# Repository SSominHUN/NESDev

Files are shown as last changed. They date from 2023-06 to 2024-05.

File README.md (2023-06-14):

# NESDev

Thesis work.

In my thesis, I re-design the iconic game console Nintendo Entertainment System to modern standards. My project based on the hardware emulation of the NES’s hardware in an FPGA (Xilinx Spartan-
6). 

This is an ongoing project. In my last semester, I designed a two layer PCB, with Altium Designer, where I upgrade the old
hardware, with modern components. I placed an HDMI for VGA rendering, also an on board SRAM (for NES game ROM's). For future improvements I placed an MicroSD card reader (holding more game ROM's). Of course next to these "upgrades" my console have to play the original games.

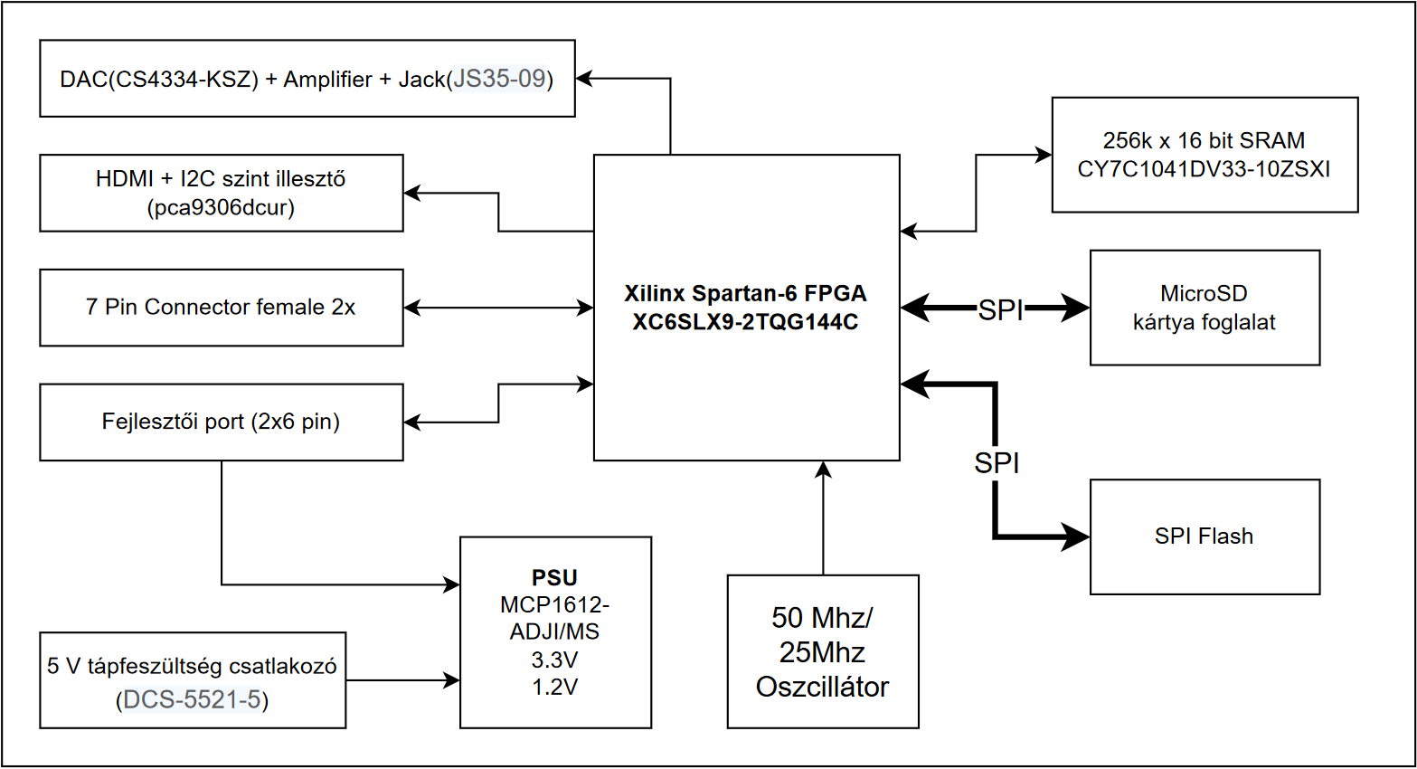
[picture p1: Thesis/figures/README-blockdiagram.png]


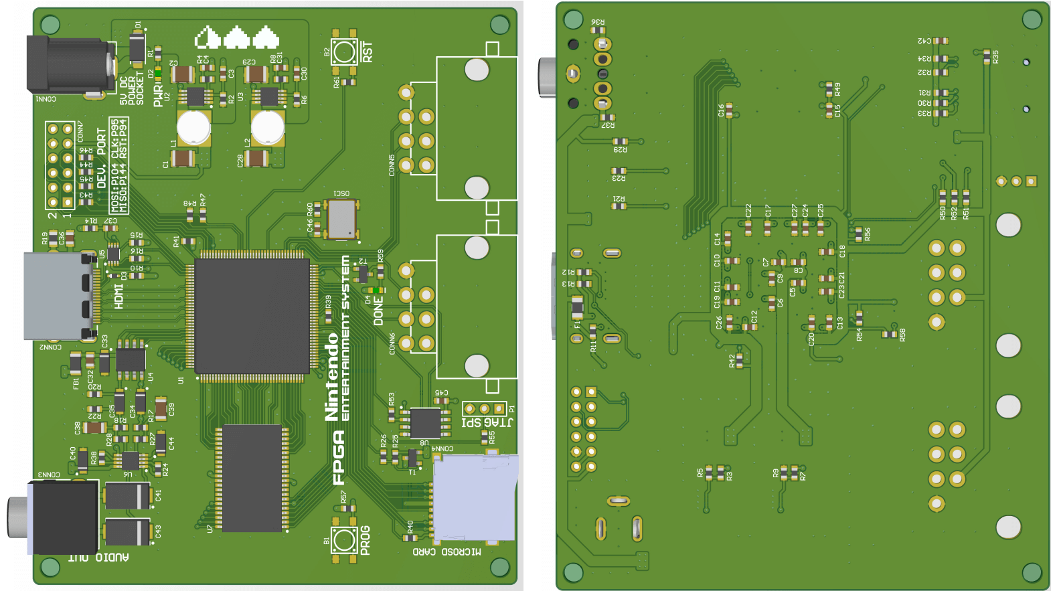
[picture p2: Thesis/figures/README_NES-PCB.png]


Moreover I started to work on re-designing the PPU (Picture Process Unit) of the NES. 

In the future I'm going to implement the CPU (6502 8-bit) of the original hardware and the APU (Audio Process Unit) and in the end I will test my hardware with the original games.
This stage of the project have a Hungarian documentation.

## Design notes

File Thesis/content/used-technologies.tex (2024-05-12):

\chapter{Felhasznált eszközök}

\section{Altium Designer}

Az Altium Designer egy teljes körű elektronikai tervező szoftvercsomag (EDA), amelyet nyomtatott áramköri lapok (PCB-k) tervezésére alkalmaznak. Egységes környezetben kombinálja a kapcsolás rajz és a PCB tervezését, ezzel lehetővé téve a tervezőknek a grafikus áramköri tervek gyors és hatékony létrehozását. A szoftver támogatja a hierarchikus tervezést és a kapcsolási rajzok valós idejű ellenőrzését. A PCB tervezés során előnyös funkciói közé tartozik az interaktív huzalozás, a 3D-s PCB megjelenítés és a különböző tervezési szabályok ellenőrzése.

Az Altium Designer integrált megközelítése lehetővé teszi a tervezők számára, hogy egyetlen platformon belül hozzák létre és optimalizálják elektronikai terveiket. A szoftver nemcsak a tervezési folyamatot egyszerűsíti, hanem magában foglalja a szimulációs és elemző eszközöket is, amelyek segítik a tervezőket az elektronikai rendszerek teljesítményének és megbízhatóságának előzetes értékelésében.

\section{Xilinx ISE}

A projektben használt Spartan-6-os FPGA-t a Xilinx új fejlesztő környezete, a Vivado már nem támogatja, ezért a fejlesztéseket a régebbi Xilinx ISE-ben kellett elkészítenem. A Xilinx ISE (Integrated Softver Environment) a Xilinx Inc. által kifejlesztett, széles körben használt szoftvercsomag. Átfogó eszközkészletet biztosít a digitális logikai áramkörök tervezéséhez, teszteléséhez és megvalósításához a Xilinx Field-Programmable Gate Array (FPGA) és Complex Programmable Logic Device (CPLD) eszközökkel.

A Xilinx ISE teljes körű megoldást kínál a digitális tervezéshez, beleértve a HDL (Hardware Description Language) tervezést, a szimulációt, a szintézist, az implementációt és az eszközprogramozást. Támogatja a különböző tervezési beviteli módszereket, beleértve a Xilinx Schematic Editor segítségével történő sematikus rögzítést és a HDL-alapú tervezést olyan nyelvekkel, mint a VHDL (VHSIC Hardware Description Language) és a Verilog.

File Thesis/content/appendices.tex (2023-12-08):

%----------------------------------------------------------------------------
\appendix
%----------------------------------------------------------------------------
\chapter*{\fuggelek}\addcontentsline{toc}{chapter}{\fuggelek}
\setcounter{chapter}{\appendixnumber}
%\setcounter{equation}{0} % a fofejezet-szamlalo az angol ABC 6. betuje (F) lesz
\numberwithin{equation}{section}
\numberwithin{figure}{section}
\numberwithin{lstlisting}{section}
%\numberwithin{tabular}{section}

\section{NES kártya alkatrész elhelyezési terve}
\label{sec:NES-components}
\subsection{Top}
\label{sec:NES-components-top}
\begin{figure}[H]
	\centering
	
	
\end{figure}

\subsection{Bottom}
\label{sec:NES-components-bottom}
\begin{figure}[H]
	\centering
	
	%\caption{Tápegység} 	
\end{figure}

\section{Nyomtatott áramköri terve (2D transparent)}
\label{sec:FPGA-nes-transparency}
\begin{figure}[H]
	\centering
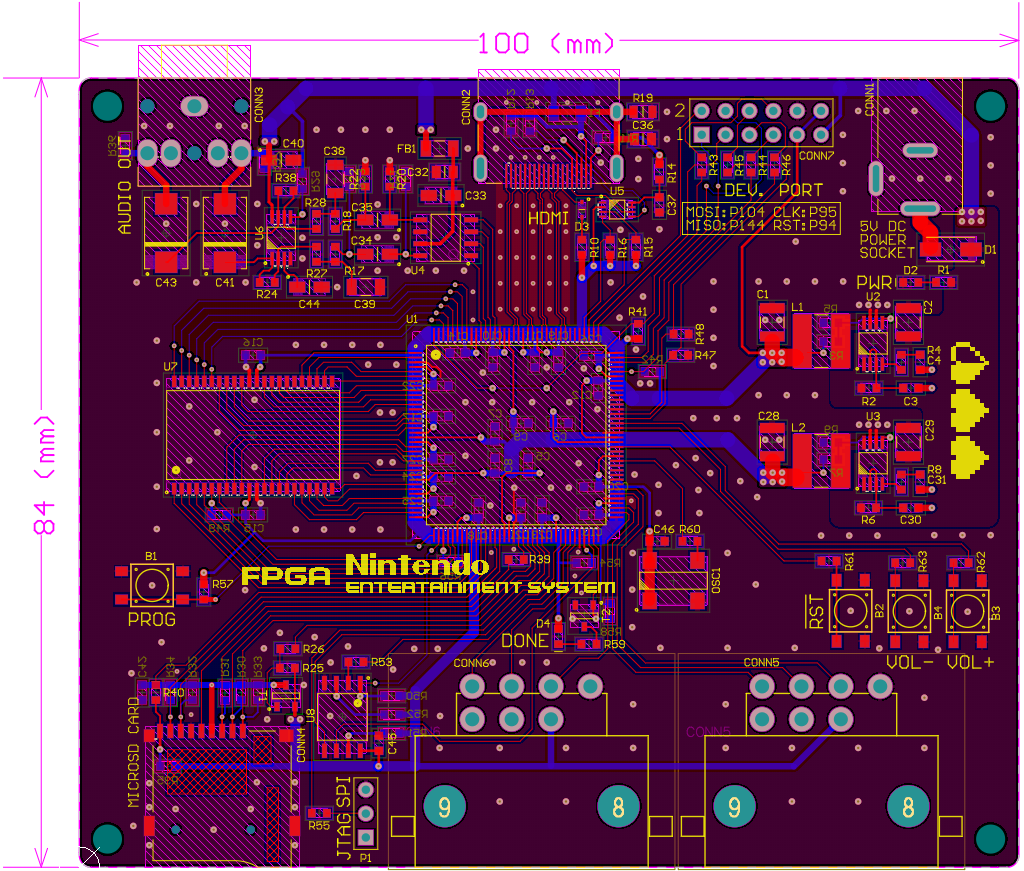
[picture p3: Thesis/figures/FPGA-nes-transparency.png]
	
	%\caption{Tápegység} 	
\end{figure}

%TODO new fugellek here
\newpage
\section{FPGA NES kártya kapcsolási rajza}
\subsection{Tápegység}
\label{sec:PSU}
\begin{figure}[H]
	\centering
	
	%\caption{Tápegység} 
\end{figure}
\subsection{HDMI és MicroSD kártya csatlakozó}
\label{sec:HDMI-MicroSDcard}
\begin{figure}[H]
	\centering
	
	%\caption{HDMI és MicroSD kártya csatlakozó} 
\end{figure}
\subsection{DAC, erősítő és kontroller áramkörök}
\label{sec:DAC-controllers}
\begin{figure}[H]
	\centering
	
	%\caption{DAC, erősítő és kontroller áramkörök}	
\end{figure}
\subsection{SRAM és SPI-Flash}
\label{sec:SRAM-SPI-Flash}
\begin{figure}[H]
	\centering
	
	%\caption{SRAM és SPI-Flash} 	
\end{figure}
\subsection{FPGA OSC és JTAG}
\label{sec:OSC-JTAG}
\begin{figure}[H]
	\centering
	
	%\caption{FPGA OSC és JTAG} 
\end{figure}
\subsection{FPGA IO bankok}
\label{sec:FPGA-BANKS}
\begin{figure}[H]
	\centering
	
	%\caption{FPGA IO bankok} 
\end{figure}

\newpage
\section{NTSC PPU eredeti képalkotás}
\label{sec:NTSC-PPU-frame}
\begin{figure}[H]
	\centering
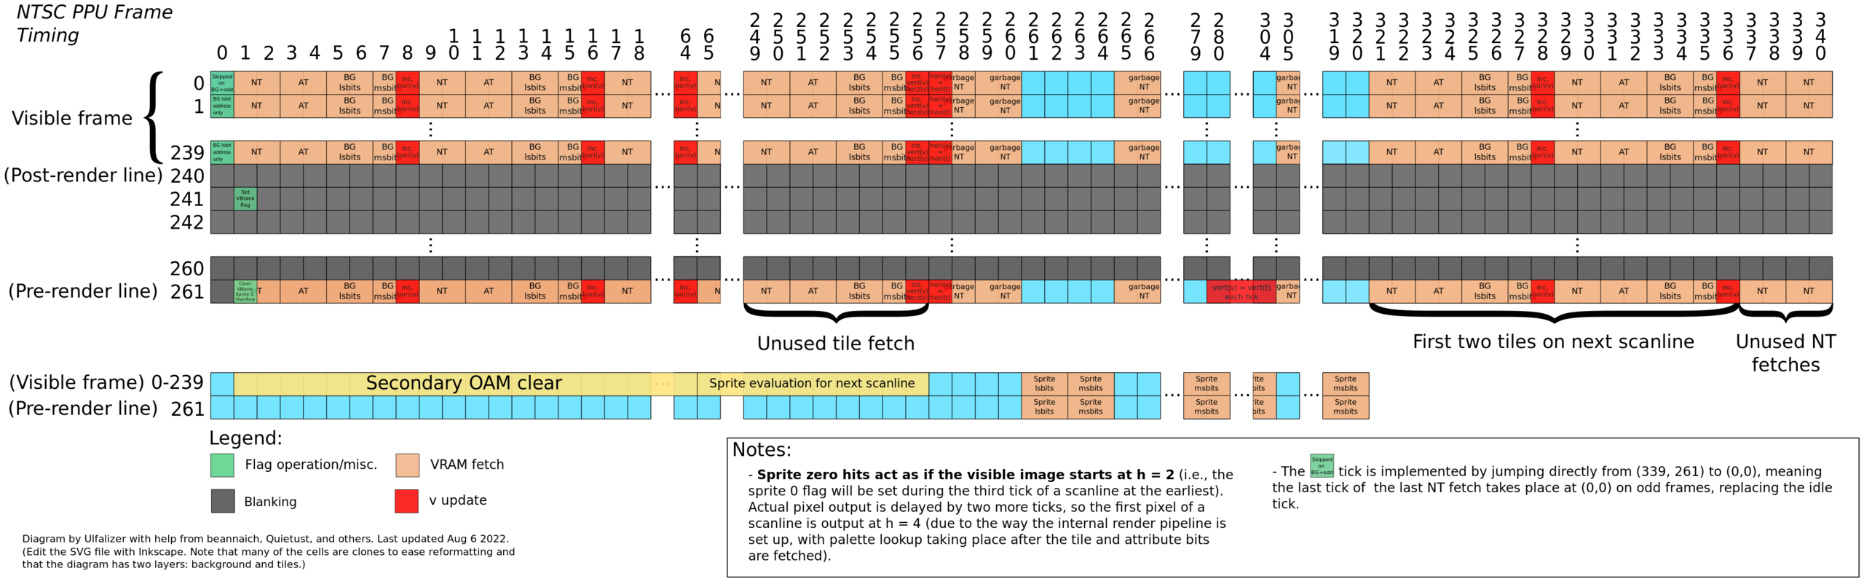
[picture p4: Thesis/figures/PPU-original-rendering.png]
	
	%\caption{FPGA IO bankok} 
\end{figure}

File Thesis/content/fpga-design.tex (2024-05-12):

\chapter{FPGA tervezés}
\label{sec:fpga-desing-begining}

A Nintendo Entertainment System hardveres komponenseinek újratervezése során az ISE Design Suite szoftvert és a Verilog hardverleíró nyelvet választottam. A tervezés fő szempontja az áttekinthetőség, %% beláthatóság?
céltudatosság és tesztelhetőség volt, mely tulajdonságok elengedhetetlenek egy nagyobb projekt fejlesztése során. A megtervezett chipeknek az összehangolt és hibátlan (az eredeti NES hardverrel megegyező) működésének ellenőrzését követően léptem tovább a következő fejlesztési egységre.

A következőkben a diplomamunka során tervezett és tesztelt hardveres komponensek működését és felépítést fogom bemutatni, az úgynevezett "top-down" elv alapján. Ennek jelentése, hogy először a teljes rendszer kapcsolatát mutatom be, majd ezt követően térek ki a különböző elemek részletes működésére.

\begin{figure}[H]
	\centering
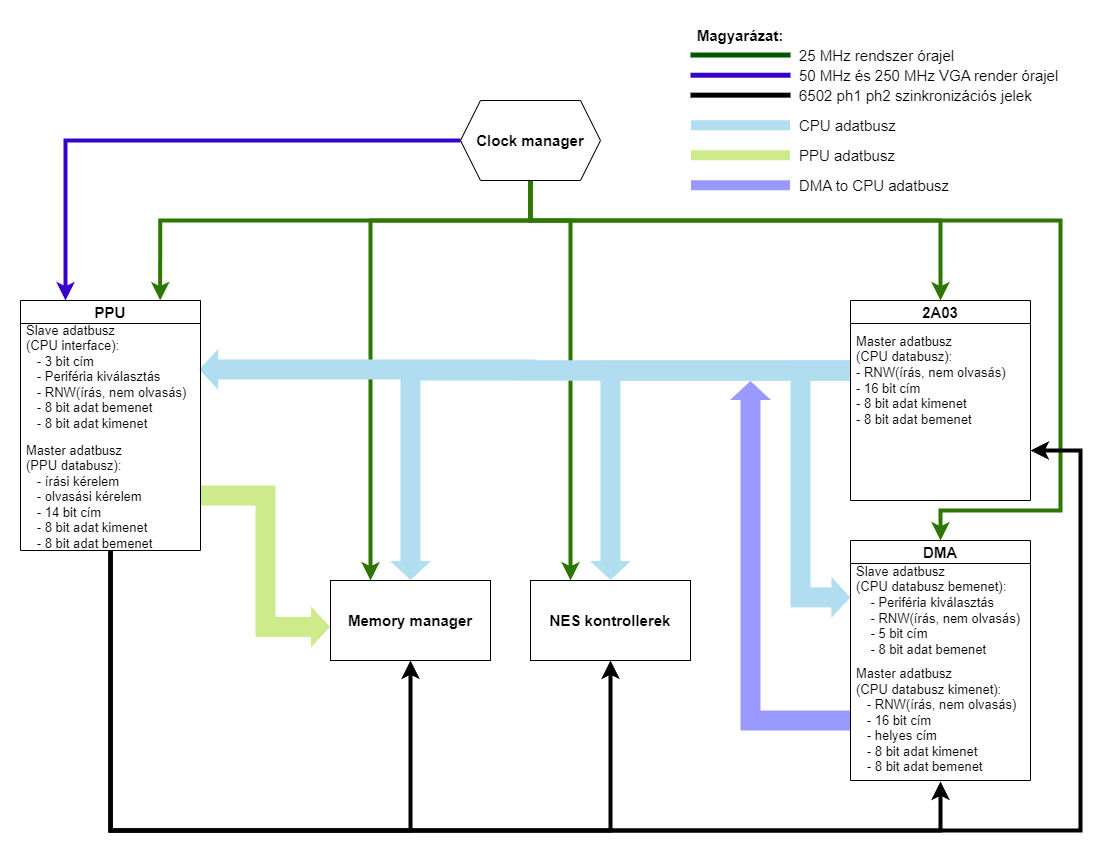
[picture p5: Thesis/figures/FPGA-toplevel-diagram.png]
	
	\caption{Megvalósult FPGA projekt (nes\_top) diagramja} 
	\label{fig:FPGA-toplevel-diagram}
\end{figure}
%\section{Rendszer blokkvázlat bemutatása}

% ebben valami nem kóser a zárójel környékén
Az FPGA tervezés első fázisában a NES eredeti hardverét a különböző funkciókat ellátó hardveres elemek (chipek) alapján modulokra osztottam. Ezeket a modulokat és a köztük lévő logikai kapcsolatokat láthatjuk \aref{fig:FPGA-toplevel-diagram}. ábrán.

% két FAJTA/CSOPORT adatkapcsolat van ha jól értem, nem két adatkapcsolat
A modulok között kétfajta logikai adatkapcsolat látható, az első a kommunikációs buszok (vastag nyilak), ezek többféle vezetéket foglalnak magukba (adat, cím, vezérlőjelek), ezek pontos tartalmát a nyilak kezdőpontjánál láthatjuk. A második pedig a rendszer órajelek. Ide tartoznak a rendszerórajelből előállított, $\phi_1$ és $\phi_2$ szinkronizációs jelek is.
% phit megcsinálni

\section{A buszok implementálása}

A NES eredeti belső logikai kapcsolatait alapul véve, két fő adatbuszt különböztetünk meg, a CPU és a PPU adatbuszt. 

A PPU adatbusz struktúrájában egyszerűbb, csupán a memória %memória kezelő?
kezelő modullal kommunikál. Az itt található névtábla (NT) memóriát írja és olvassa, illetve a karakter ROM tartalmát olvassa. %ezt nem értem, de lehet értelmes

A CPU adatbusz működése a DMA miatt egy fokkal bonyolultabb. Alapesetben a CPU az adatbuszán keresztül éri el a címtartományában található különböző perifériák regisztereit/memóriáit. A slave interfészek implementálása során ügyeltem arra, hogy a különböző hardveres komponensek minél egyszerűbben fogadják a CPU adatbuszát (ezzel egyszerűsítve a szintetizálandó hardveren). Ez \aref{code:cpu-databus-simplification}. hardverleírásban is látható. Viszont a DMA a működése során elveheti a processzor adatbuszát% ki veheti át? és nem írányítást vesz át?
, ilyenkor ő végez memória és regiszter hozzáféréseket a perifériákon. A helyes cím kiadása mellett a DMA elveszi a processzor Ready jelét is, ezzel blokkolva CPU működését és megakadályozva a busz több master egység általi meghajtását. A különböző modulok kimeneti jelei úgy lettek megtervezve, hogy csak megfelelő időzítés mellett adjanak ki adatokat (különben nullát), így \aref{code:cpu-data-bus}. hardverleírásban is látható, hogy a különböző kimenetek egyszerű logikai vagy kapcsolatával tudjuk a perifériák olvasási adatbuszait összekötni.

\begin{lstlisting}[caption={CPU adatbuszt befolyásoló DMA jelek}, label={code:cpu-data-bus}, style=prettyverilog]
// CPU data in
wire [7:0] cpu_din = (memory_manager_cpu_din | ppu_to_cpu_din | controller_cpu_din);

// DMA and CPU outputs
assign cpu_addr = (dma_cpu_avalid) ? (dma_cpu_addr) : (nes6502_addr);
assign cpu_dout = (dma_cpu_dout | nes6502_dout);
assign rnw = ~(~dma_cpu_rnw | ~nes6502_rnw);\end{lstlisting}

A különböző interfészek egyszerűsítése során \aref{tab:CPU-Memory}. táblázatban és \aref{sec:NT-AT-mirroring}. fejezetben bemutatott tükrözés (\textit{mirroring}) módszerét % ez nem egy módszer?
használtam ki. Ennek alapja hogy csupán a címbusz adott bitjeit figyeljük, például PPU regiszterek esetén az alsó három bitet. Ezzel párhuzamosan pedig megpróbálunk egy megfelelő kiválasztó jelet generálni a chiphez, PPU esetén a felső három bit fixálja a \$2000 - \$3FFF-ig tartó cím tartományt. Ilyen egyszerűsítést alkalmaztam a kontrollerek és DMA interfész esetén is (lásd \ref{code:cpu-databus-simplification}. hardverleírás).

\begin{lstlisting}[caption={A CPU adatbusz interfészek egyzserüsítése}, label={code:cpu-databus-simplification}, style=prettyverilog]
// PPU Slave interface bemenet
.slv_mem_addr(cpu_addr[2:0]),      				// register interface reg select (#2000-#2007)
.slv_mem_cs((cpu_addr[15:13] == 3'b001)), 		// register interface enable (#2000 - #3FFF just when it is active)

// Controller inputs
.cpu_data_in(cpu_dout[0]), //just one bit the $4016 write strobe

// DMA Slave databus
.slv_mem_select((ag6502_addr[15:14] == 2'b01)),  
.slv_mem_addr(ag6502_addr[4:0]),\end{lstlisting}

\section{Működési órajel választása}

Egyik első feladat FPGA tervezés során a hardver átgondolását követően, a rendszerórajel kiválasztása. Erről a fő órajelről fogjuk működtetni a szinkron tárolóinkat, a memória elérésünket és az összes perifériánk időzítésének is ez lesz az alapja. A NES megvalósítása során használtam két specifikusabb órajelet is a rendszer órajel mellett, ezeket a TMDS jelek előállítása során használtam fel. Ezek a kiemelt órajelek a többi FPGA-n található jeltől elkülönített helyen, a globális órajel hálózatban terjednek. Ennek is van késleltetése, amelyet az időzítés analízis figyelembe vesz és ez alapján befolyásolja az elérhető legmagasabb órajel frekvenciát. Ehhez az órajel hálózathoz csatlakozik a külső oszcillátorunk, % nem ehhez a hálózathoz?
 illetve a PLL és DCM FPGA-n belüli hardveres elemek is, amelyek lehetővé teszik az órajelek frekvenciájának változtatását.

%itt kicsit zavaros, hgoy melyik jelből mennyi van, egyes-többes számot kell lecsekkolni
A NES kártyán egy 50 MHz-es külső órajel forrást helyeztem el. \Aref{sec:picture-creation-ideas}. fejezetben leírtak alapján a rendszer órajelemet a megjelenítésnek megfelelően kell megválasztanom, ezt figyelembe véve a működési (rendszer) órajelemet 25 MHz-nek választom. A beérkező 50 MHz-ből a PLL helyes beállítása során előállítok 25 MHz-et és 250 MHz-et. A VGA kép generálásához szükségem lesz mind a három órajelre, a 25 MHz a pixel órajelem lesz (erre a jelre kell előállítanom a  24 bites RGB értékeimet), az 50 MHz az 5 bites párhuzamos-soros átalakítókhoz kell, végül pedig 250 MHz-el fogom kiadni a biteket a HDMI differenciális adatvezetékei számára. 

%phit itt is megcsinálni
\begin{lstlisting}[caption={6502 $\phi_1$ és $\phi_2$ vezérlőjelek előállítása}, label={code:6502-clocksignals}, style=prettyverilog]
reg  clkgen_cnt_en_clr;
wire clkgen_cnt_en_set = (x_rendercntr == (ODDFRAME_END_OF_BG_RENDERING_LINE + 4));
always @(*) 
begin
	if (background_enabled && oddframe && (y_renderingcntr == PRERENDERING_ROW))
		clkgen_cnt_en_clr <= (x_rendercntr == ODDFRAME_END_OF_BG_RENDERING_LINE);
	else
		clkgen_cnt_en_clr <= 1'b0;	
end

// clock genereation enable
reg		clkgen_cnt_en;
always @ (posedge clk)
begin
	if (rst || (x_rendercntr == END_OF_BG_RENDERING_LINE) || clkgen_cnt_en_clr)
		clkgen_cnt_en <= 1'b0;
	else
		if ((x_rendercntr == FIRST_SCANLINE_PIXEL) || clkgen_cnt_en_set)
			clkgen_cnt_en <= 1'b1;
end	

//clock generation timer
reg	[3:0]	clkgen_cnt;
always @ (posedge clk)
begin
	if (rst)
		clkgen_cnt <= 4'd0;
	else
		if (clkgen_cnt_en)
			if (clkgen_cnt == 4'd11)
				clkgen_cnt <= 4'd0;
			else
				clkgen_cnt <= clkgen_cnt + 4'd1;
end

always @ (posedge clk)
begin
	ph1_rising	<= clkgen_cnt_en & (clkgen_cnt == 4'd0);
	ph1_falling <= clkgen_cnt_en & (clkgen_cnt == 4'd5);
	ph2_rising	<= clkgen_cnt_en & (clkgen_cnt == 4'd6);
	ph2_falling <= clkgen_cnt_en & (clkgen_cnt == 4'd11);
end\end{lstlisting}

%phi
Ezekből az órajelekből kell előállítani a NES hardver számára a megfelelő kiválasztó jeleket. Az NTSC NES-ben található MOS 6502 1,789773 MHz-es bemeneti $\phi_0$ órajellel rendelkezik. Ebből hozza létre a eltolt fázisú $\phi_1$ és $\phi_2$ külső időzítési órajelet. %fázis tolt?
A $\phi_2$ órajel lefutó élére történik a periféria adatok olvasása. 

%phi
A rendszer %projekt helyett rendszer vagy kártya vagy eszköz
VGA rendrelését úgy implementáltam, hogy amíg a PPU képgenerálást kiegészíti a hardver VGA jellé, addig a PPU és vele együtt az egész NES hardver egy alvó állapotban várakozik. Ezt a $\phi_1$ és $\phi_2$ jelek megfelelő időben történő generálásával (késleltetésével) tudtam kialakítani. Ezt láthatjuk \aref{code:6502-clocksignals}. hardverleírásban. A Verilog kód első felében azt láthatjuk, hogy a PPU aktív kép generálása során az óra jel generálásáért felelős számláló engedélyezve van, viszont a képalkotás végeztével (VGA blanking terület) a számlálót tiltjuk. Legfelül pedig az látható, hogy az eredeti PPU megkülönböztette minden második (páratlan) kép generálását úgy, hogy specifikus pixeleket kihagyott a generálásból, ezt is figyelembe kell venni a hardver tervezése során (clkgen\_cnt\_en\_clr jel). Ezt követően pedig kiszámolható, hogy a 25 MHz-es órajelünkre működtetett számlálót, ha 11-re nullába állítjuk, akkor az első hat óra el alatt aktív a $\phi_1$ és a második hat alatt pedig a $\phi_2$. Ha ehhez még hozzászámoljuk a számláló megfelelő engedélyezését, ~1,8 MHz körüli értéket kapunk. Ezen órajelek felfutó és a lefutó éleihez tartozó számláló élállapotok kerülnek dekódolásra a Verilog kód második felében (\ref{fig:FPGA-phi1-phi2}. ábra).

\begin{figure}[H]
	\centering
	
	\caption{MOS 6502 órajel generálása (FPGA sim)} 
	\label{fig:FPGA-phi1-phi2}
\end{figure} 

\section{Picture Process Unit}
\label{sec:PPU-FPGA}

A PPU időzítésének és működésének alappillérét két számláló, egy horizontális és egy vertikális számláló képzi. Ezek szinkronban végigkövetik a teljes eredeti képgenerálást és ezzel együtt a új HDMI-n keresztül történő képgenerálást is. \Aref{sec:picture-creation-ideas}. fejezetben bemutatott két módszer közül az egyszerűbb megoldást választottam a képgenerálás megalkotására. Tehát minden egyes NES pixelt felnagyítok 2x2-es pixelekké, ezzel egy pixelesebb %pixelesebb de élesebb? ezek egymás ellentétei
képet kapva végeredményként (amely jobban hasonlít az eredeti konzol képére).

%itt mintha a pixel és az órajel kompatibilis lenne egymással. Nem pixel előállítása(ának ideje) és órajel, amik kompatibilisek?
Az NTSC PPU képalkotásának leírását %képalkotásáabnk leírását, nem?
\aref{sec:NTSC-PPU-frame}. függelékben láthatjuk. Az eredeti hardver, a 0-239-ig tartó sorokban, az 1. pixeltől kedve a 256. pixelig minden egyes órajelben előállít egy pixelt (kompozit jelként)% ezt nem értem
. Ha ezt a képalkotást szeretnénk szinkronba hozni a 640x480 pixeles VGA jel előállításával, ami 800 pixelt jelent horizontálisan és 525 sort vertikálisan a kioltási tartományokat is beleértve, akkor egy 1600-as horizontális és egy 261-ig tartó vertikális számlálóra van szükség, ezáltal egy PPU sor ideje alatt, két sor VGA képet küldünk ki. Természetesen így egy puffereléssel el kell csúsztatnunk a VGA képalkotást a PPU-hoz képest és az 1600-as PPU sort minden második rendszerórajelre kell mintavételeznünk. Ennek függvényében \aref{sec:NTSC-PPU-frame}. függelékben látható állapotgépek állapotaiban töltött időt is meg kell hosszabbítani, még hozzá úgy, hogy a képen látható horizontális pixel órajel minden órajele az FPGA képalkotásban négy rendszer órajelnek feleljen meg. 

	\subsection{CPU által elérhető regiszterek és CPU adatbusz}
	\label{sec:CPU-databus-ppu_reg}

    %phi
	Először is tekintsük meg a CPU adatbusz címének dekódolását és az ebből előállított vezérlőjeleket a PPU számára (\ref{code:CPU-signals-decode}. hardverlírás részlet). Ezek a jelek vezérlik a chip belső hét regiszterének elérését. A regiszterek írását a $phi_2\_falling$ jelre szinkronizálom (inaktív RNW jel mellett). Az olvasás során pedig az adatokat a $phi_2\_rising$ jel hatására (aktív RNW jel mellett) helyezem el a CPU buszinterfész adatkimenetén. Ezt az adat kimenetet a $phi_2\_falling$ jelre nullába állítom, az adatbusz helyes működése érdekében.
	
\begin{lstlisting}[caption={A CPU adatbusz feldolgozása (PPU vezérlőjelek)}, label={code:CPU-signals-decode}, style=prettyverilog]
//CTRL register write #2000
wire control_wr     = ph2_falling & slv_mem_cs & ~slv_mem_rnw & (slv_mem_addr == 3'b000);
//MASK register write #2001 
wire render_mask_wr = ph2_falling & slv_mem_cs & ~slv_mem_rnw & (slv_mem_addr == 3'b001);
//OAM read/write address #2003 
wire oam_addr_wr    = ph2_falling & slv_mem_cs & ~slv_mem_rnw & (slv_mem_addr == 3'b011);
//OAM data read/write #2004 
wire oam_data_wr    = ph2_falling & slv_mem_cs & ~slv_mem_rnw & (slv_mem_addr == 3'b100);
//fine scroll position (two writes: X scroll, Y scroll) #2005
wire scrolling_wr   = ph2_falling & slv_mem_cs & ~slv_mem_rnw & (slv_mem_addr == 3'b101);
//PPU read/write address (two writes: most significant byte, least significant byte) #2006
wire vram_addr_wr   = ph2_falling & slv_mem_cs & ~slv_mem_rnw & (slv_mem_addr == 3'b110);
//PPU data read/write #2007 
wire vram_data_wr   = ph2_falling & slv_mem_cs & ~slv_mem_rnw & (slv_mem_addr == 3'b111);
//Register read enable signals
wire status_rd      = slv_mem_cs & slv_mem_rnw & (slv_mem_addr == 3'b010);
wire oam_data_rd    = slv_mem_cs & slv_mem_rnw & (slv_mem_addr == 3'b100);
wire vram_data_rd   = slv_mem_cs & slv_mem_rnw & (slv_mem_addr == 3'b111);\end{lstlisting}

	A CPU által írt PPU regiszterek értékét \aref{code:CPU-signals-decode}. részletben látható vezérlőjelek segítségével mentem regiszterekbe. Majd ezeknek a regisztereknek a megfelelő bitjeit szétbontom a könnyebb feldolgozás érdekében. Viszont a PPU rendelkezik 16 bites belső regiszterekkel is, ezeket a regisztereket kétszeri írással tudja elérni a CPU 8 bites adatbusza. Ilyen regiszter a görgetési pozíció és a VRAM cím regisztere. Az FPGA projektben \aref{code:second-write}. hardverleírásban látható $second\_write$ jel segítségével vagyunk képesek a regiszterek második írásának detektálására. A második 8 bites adat mentésé pedig ennek a jelnek és a regiszter írását jelző jel hatására történik.

\begin{lstlisting}[caption={Cím és görgetés regiszterek második írásának figyelése}, label={code:second-write}, style=prettyverilog]
reg second_write;
always @ (posedge clk) 
begin
	if (rst || (status_rd && ph2_falling))
		second_write <= 1'b0;
	else
		if (scrolling_wr || vram_addr_wr)
			second_write <= ~second_write;
end\end{lstlisting}
	
	A PPU regiszter elérésének vannak olyan részei, amelyek időzítés kritikusak (ha ezekre nem figyelünk a játékaink képgenerálásában különböző hibákat figyelhetünk meg). Ilyen például a VRAM írása és olvasása, ezeket a jeleket megfelelő módon késleltetnünk kell, hogy szinkronban legyenek a PPU megjelenítéshez tartozó memória eléréseivel. Erre a legkönnyebb mód egy állapotgép, ezt \aref{fig:VRAM-read-write-FSM}. ábrán láthatjuk.
	
	\begin{figure}[H]
		\centering
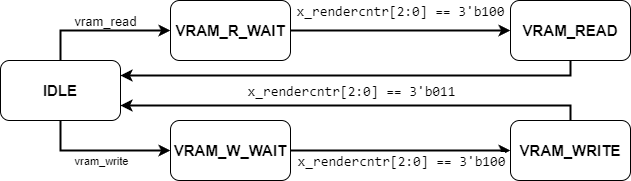
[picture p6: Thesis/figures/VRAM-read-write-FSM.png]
		
		\caption{CPU-ból ékrekző VRAM írási és olvasási jelek PPU időzítéséhez igazító állapotgép} 
		\label{fig:VRAM-read-write-FSM}
	\end{figure} 	
	
	\subsection{Háttér képalkotást és memória olvasást vezérlő állapotgép}
	
	\Aref{PPU-irodalom}. fejezetben olvasottak alapján az eredeti PPU kép generálását két nagyobb egységre bonthatjuk: a háttér, és a mozgó csempe elemek (sprite-ok) %itt szerintem valami kihagyható, vayg zárójelezni kell
 generálására. Ebben a fejezetben először az FPGA-ban implementált háttér generálási megoldást olvashatjuk.
	
	\begin{figure}[H]
		\centering
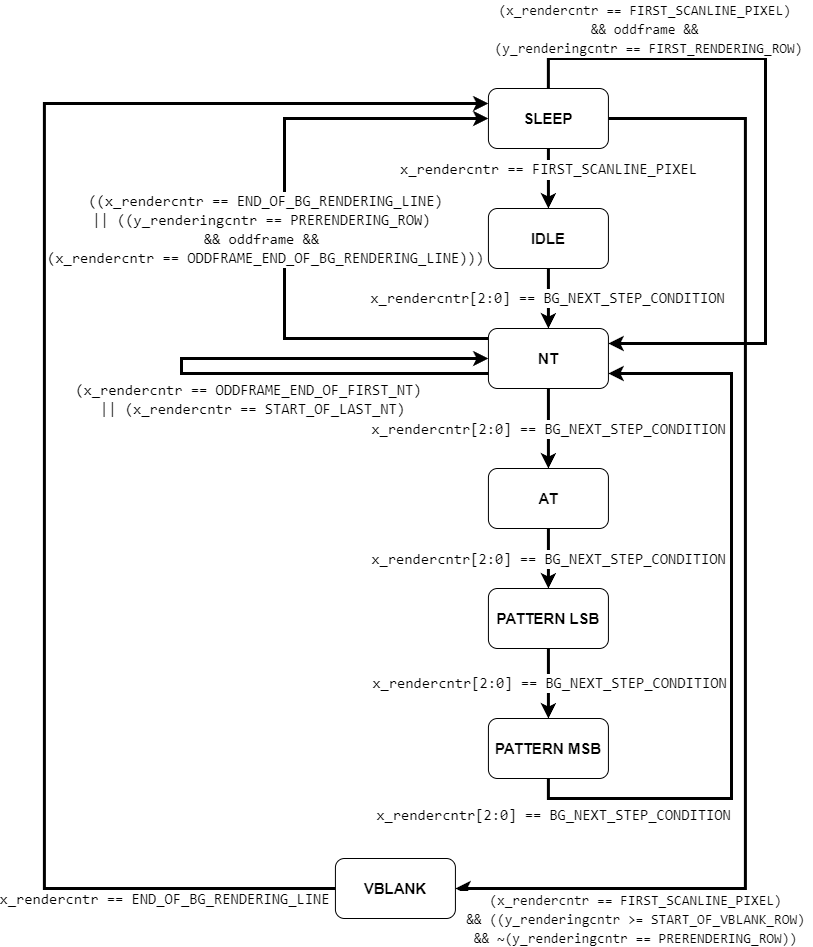
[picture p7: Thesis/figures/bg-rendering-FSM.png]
		
		\caption{Háttér képalkotás és memória olvasást vezérlő állapotgép} 
		\label{fig:bg-rendering-FSM}
	\end{figure} 
	
	Az FPGA projekt háttér képalkotását, \aref{fig:bg-rendering-FSM}. ábrán látható állapotgép határozza meg. Az állapot átmenetek képzéséhez a chip horizontális és vertikális számlálóit használtam, illetve az eredeti háttér alkotási leírást vettem alapul (lásd \ref{sec:NTSC-PPU-frame}. függelék). A PPU ismertetése során már olvashattuk, hogy az eredeti állapotgépben található állapotokban négyszer annyi időt kell tölteni a hardvernek, a VGA jel kiadásának szinkronizálása miatt. Az állapotgépünk hat, az eredeti PPU-ban is megtalálható állapotra és egy SLEEP blokkoló állapotra bonthatjuk. A SLEEP állapot során a PPU és vele együtt az egész NES hardver egy blokkolt állapotba kerül. Ezalatt az idő alatt a CPU órajel képzését is blokkoljuk, így csak a pixel kétszerezés és a TMDS jelek kiadása zajlik. 
	
	\Aref{fig:bg-rendering-FSM}. ábrán látható hat alapállapot működése hasonlít az eredeti PPU állapotokhoz (lásd \ref{sec:NTSC-PPU-frame}. függelék):
	
	\begin{enumerate}
		\item \emph{Idle:} Minden képgenerálási sor első (nulladik) órajele egy \emph{Idle} állapot, itt a PPU nem végez memória elérést, csak cím regisztereket állít. Minden páratlan teljes kép generálása során, ez az állapot kihagyásra kerül (helyette az utolsó NT olvasás zajlik le).
		\item \emph{NT, névtáblák olvasása:} Ebben az állapotban kerülnek kiolvasásra a névtábla adatok. A fentebb látható állapotgépben még azt láthatjuk, hogy \aref{sec:NTSC-PPU-frame}. függelékben is látható módon, a 261. sor és a látható képtartomány (0-239. sor) végén, az állapotgép még két névtábla olvasást végez. %ezt nem értem
		\item \emph{AT, csempe attribútumok olvasása:} Ebben az állapotban a névtábla memóriából olvassuk ki a csempéhez tartozó attribútum adatokat. A későbbiekben ez határozza meg a csempe színeit.
		\item\emph{Pattern LSB (least significant byte):} A névtábla olvasás során megszerzett Pattern csempe cím használatával, egy csempe sor (8 pixel) adatainak, alsó 8 bitjének olvasása történik ebben az állapotban. (\aref{fig:Gumba-tile}. ábrán látható csempe egy sorának alsó bitjei).
		\item \emph{Pattern MSB (most significant byte):} A negyedik állapotban leírt olvasás, befejező lépése történik ebben az állapotban, tehát a felső 8 bit kiolvasása és mentése. Illetve ebben az állapotnak történik még a vertikális és horizontális VRAM címszámlálók növelése, \aref{sec:NTSC-PPU-frame}. függelékben látható helyeken (vörös négyzetek).
		\item \emph{VBLANK:} Ez az állapot az eredeti PPU vertikális kioltása, a legtöbb játék ezalatt az idő alatt végzi a PPU memória műveletek. Itt hozom létre a PPU státusz regiszter, VBLANK (IRQ) jelét. Ez jelez a NES CPU számára (NMI), hogy a VBLANK periódus elkezdődött (szabadon elkezdheti a memória műveleteket a PPU regisztereken keresztül). 
	\end{enumerate} 
	
	A Pattern olvasási állapotok nem csupán a háttér olvasását hanem a sprite adatok kiolvasását is végzik. \Aref{sec:NTSC-PPU-frame}. függelékben láthatjuk is, hogy a 257. képponttól a 320. képpontig történik a mozgó csempe adatok olvasása a következő aktív sorra, a sor többi részen pedig a háttér adatok olvasása történik.
	
	A PPU memória területeinek olvasását (NT, AT, PATTERN) úgy időzítem, hogy az adott állapot utolsó órajelére, kerüljön mentésre az éppen aktuális adat (felhasználható legyen). Ennek pontos időzítését \aref{code:saving-from-PPU Databus}. hardverleírásban olvashatjuk.
	
\begin{lstlisting}[caption={Az állapotgép alapján az adatok mentét vezérlőjelek}, label={code:saving-from-PPU Databus}, style=prettyverilog]
assign nametable_read = (bgrender_state == NT) & (x_rendercntr[2:0] == 3'b011);
assign attribute_read = (bgrender_state == AT) & (x_rendercntr[2:0] == 3'b011);
assign bg_lsb_read = (bgrender_state == BG_LSB) & (x_rendercntr[2:0] == 3'b011);
assign bg_msb_read = (bgrender_state == BG_MSB) & (x_rendercntr[2:0] == 3'b011);\end{lstlisting}
	
	\Aref{sec:NTSC-PPU-frame}. függelékben a 241. sorban látható VBLANK jel előállítása során különösen figyelni kellett az időzítésre. Mivel ennek a jelnek a hatására képződik a 6502-es CPU felé az NMI (non maskable interrupt) megszakítás (\aref{code:vblank-set}. hardverleírás, IRQ), amelynek pontos lefutása elengedhetetlen a játékok emulálása szempontjából. Az ehhez tartozó megszakításkezelő rutin tartalmazza általában azt a programkódot, amely a név (NT) memória területek frissítésért felelős. A pontos időzítést az FPGA projektben egy kétbites léptetőregiszter használatával állítom be, ezt és a vezérlőjelek képzését \aref{code:vblank-set}. hardverleírásban láthatjuk.       
		
\begin{lstlisting}[caption={VBLANK vezérlőjelek képzése és az NMI (IRQ) jel előállítása}, label={code:vblank-set}, style=prettyverilog]
//Driving the interupt flag
reg  interrupt_flag;
wire interrupt_clr;
always @ (posedge clk) 
begin
	if (rst || interrupt_clr || (status_rd && ph2_falling))
		interrupt_flag <= 1'b0;
	else
		if (vblank_set[2] && vblank[1])
			interrupt_flag <= 1'b1;
end
//NMI towards cpu
always @ (posedge clk) 
begin
	if (rst)
		irq <= 1'b0;
	else
		irq <= interrupt_flag & vblank_irq_enable; 
end
	
// vblank set signals
assign vblank_set[0] = (x_rendercntr == (FIRST_SCANLINE_PIXEL +  0)) & (y_renderingcntr == V_BLANK_BEGIN);
assign vblank_set[1] = (x_rendercntr == (FIRST_SCANLINE_PIXEL +  4)) & (y_renderingcntr == V_BLANK_BEGIN);
assign vblank_set[2] = (x_rendercntr == (FIRST_SCANLINE_PIXEL + 12)) & (y_renderingcntr == V_BLANK_BEGIN);

//Indicates the end of the VBLANK period.
assign vblank_clr    = (x_rendercntr == FIRST_SCANLINE_PIXEL +  4) & (y_renderingcntr == PRERENDERING_ROW);
assign interrupt_clr = (x_rendercntr == FIRST_SCANLINE_PIXEL + 12) & (y_renderingcntr == PRERENDERING_ROW);\end{lstlisting}
	
	\subsection{Mozgó csempe elemek - Sprite képalkotás}
	\label{sec:fpga-sprite-rendering}

	A PPU-ban található képalkotás második rétege a mozgó csempe elemek kiolvasása és feldolgozása az OAM memóriákból. Az eredeti hardver felépítéséről részletesen olvashatunk \aref{sec:OAM-memory}. fejezetben, az itt olvasottak alapján alakítottam ki a OAM memóriákat is az FPGA modulban. 
	
	Az elsődleges és a másodlagos OAM memóriát is elosztott memóriaként hoztam létre, a lehető leggyorsabb olvasási idő miatt. Az elosztott memória az FPGA LUT-jából közvetlenül leképeződő memória, általában olyan helyeken szokták alkalmazni, ahol kevés adatot kell tárolni és késleltetés mentes aszinkron olvasásra van szükségünk. A mi felhasználásunk során elengedhetetlen a késleltetésmentes adatkiolvasás, mert a háttér állapotgépet és a sprite állapotgépet szinkronizálni kell a Pattern adatok olvasása miatt.
	
	Az Sprite képalkotásban fontos szerepe van a DMA-ból érkező adat időben történő mentésének és ezzel párhuzamosan egy olyan elsődleges OAM RAM címzésnek, amely jól lekezeli a DMA-ból érkező adatokat és a sprite állapotgépben a másodlagos OAM memória feltöltését is. 
	
	A címképzésnek két fő módja van. Az első mód során, az elsődleges RAM címzését két mozgó számlálóval címezzük meg, m és n. Az m a négy bájtos sprite adatokon halad végig, amíg az n az elsődleges memóriában található 64 sprite-ot címzi meg, ezeknek a számlálóknak az időzítését a sprite állapotgéphez kötöttem. Ezt a címzési módot használom a másodlagos OAM memória töltése során, tehát a következő sorban aktív spritok keresésére. A második mód pedig a DMA működése során aktív cím, ez egy egyszerű fölfelé számláló, amely a CPU-tól kapja kezdő címét az OAM címregiszter írása során.
	
	Az így létrejövő két címet megfelelően multiplexálva kapjuk meg, az elsődleges OAM memória címzését. A cím képzését és az elsődleges OAM írását és olvasását \aref{code:Primary-oam}. hardverleírásban olvashatjuk részletesen.

\begin{lstlisting}[caption={Az elsődleges OAM RAM írása és olvasása}, label={code:Primary-oam}, style=prettyverilog]
(* ram_style = "distributed" *)
reg  [7:0]  pri_oam [255:0];
reg  [7:0]  pri_oam_addr;
wire [1:0]  pri_oam_addr_sel;
wire [7:0]  pri_oam_dout = pri_oam[pri_oam_addr];

always @(*) 
begin
	case (pri_oam_addr_sel)
		2'b01:   pri_oam_addr <= {n_cnt, m_cnt};
		2'b11:   pri_oam_addr <= {pri_oam_addr_cnt[7:3], n_cnt[0], m_cnt}; 
		default: pri_oam_addr <= pri_oam_addr_cnt; 
	endcase    
end

always @(posedge clk) 
begin
	if (oam_data_wr)
		pri_oam[pri_oam_addr] <= slv_mem_din;    
end\end{lstlisting} 

	Az sprite képgenerálás állapotgépének fontos eleme még a következő sorban aktív sprite-ok detektálásáért felelős hardveres egység, ezt \aref{code:Sprite-in-range}. hardverleírásban láthatjuk. Ennek alapja, hogy az állapotgép alapján képzett vezérlőjellel (oam\_temp\_reg\_wr) elmentjük az éppen aktív OAM sprite vertikális pozíció értékét és az éppen aktív sor értékből kivonva egy vertikális különbség értéket képzünk. Ezt vizsgálva a 8x8 és 8x16-os spritok esetére, detektálhatjuk, hogy az éppen aktív sprite a következő sorban megjelenik-e. Abban az esetben, ha találtunk egy megjelenítendő sprite-ot akkor az állapotgép alapján (\ref{fig:sprite-rendering-FSM}. ábra) továbblépve ezt mentjük a másodlagos memóriába, vagy még egyel növeljük a túlcsordulás jelzőt. 

\begin{lstlisting}[caption={A következő kép generálási sorban aktív sprite-ok jelzése}, label={code:Sprite-in-range}, style=prettyverilog]
reg  [8:0]  y_diff_reg1;
wire      sprite_in_range = (sprite_size) ? (y_diff_reg1[8:4] == 5'd0) : (y_diff_reg1[8:3] == 6'd0);

// if I subtract from scanline cntr - tile_addr then check the upper bits of y_diff_reg to be zero then we have a sprite in range
always @(posedge clk) 
begin
	if (rst)
		y_diff_reg1 <= 9'd0;
	else
		if (oam_temp_reg_wr)
			y_diff_reg1 <= scanline_cnt - {1'b0, pri_oam_dout};    
end\end{lstlisting}

	\begin{figure}[H]
	\centering
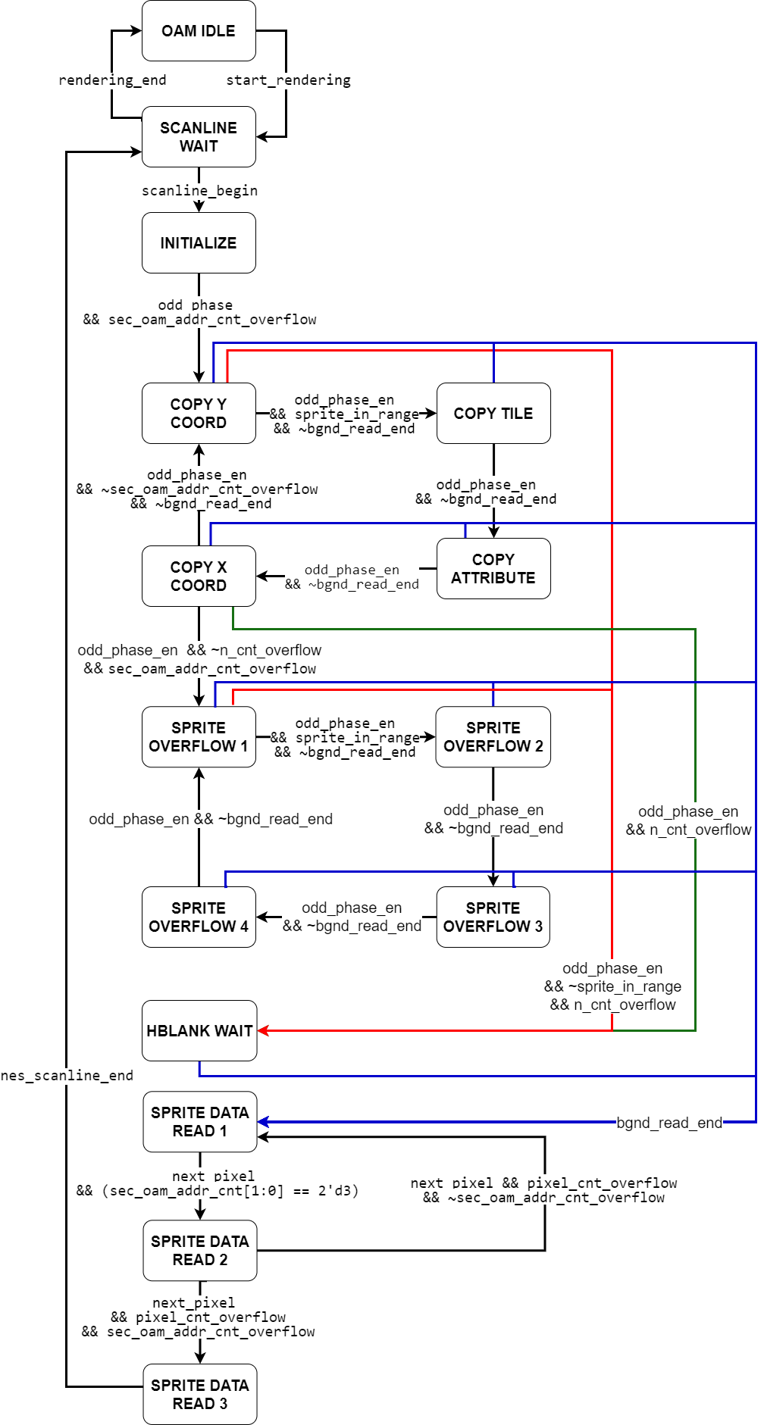
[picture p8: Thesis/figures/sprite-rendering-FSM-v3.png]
	
	\caption{Sprite képalkotás és memória olvasást vezérlő állapotgép} 
	\label{fig:sprite-rendering-FSM}
	\end{figure} 

%ez nem egy korábbi fejezet volt az eredeti hardver megértése?
	 Az eredeti sprite feldolgozás menete négy fő részre bontható, ez \aref{sec:NTSC-PPU-frame}. függelékben is látható. 	
	
	\begin{enumerate}
		\item A nyolc előző sorban mentett sprite törlése (1-64 órajel). \Aref{fig:sprite-rendering-FSM}. állapotgépben ez az IDLE állapot.
		\item Az elsődleges OAM RAM végigolvasása aktív sprite-okat keresve. Minden egyes páratlan órajel során olvassa az adatokat, a párosok alatt pedig írja őket a memória területre. Ha aktív sprite-ot találunk a négy bájtját mentjük a másodlagos OAM RAM-ba (65-256 órajel). \Aref{fig:sprite-rendering-FSM}. állapotgépben ez sorrendben az Y koordináta másolása, csempe cím másolása, csempe attribútum másolása és X koordináta másolása állapotoknak felel meg.
		\item Ha megtalált nyolc aktív sprite-ot, akkor tovább keres, hátha túlcsordulást érzékel. Itt a memória olvasásban egy hardveres hiba található, mivel ha talált egy extra aktív sprite-ot is akkor a következő sprite-ok Y koordinátája helyett a sorban következő bájtot (csempe cím) vizsgálja a rendszer. Ha ezt követően is talál még egy aktív sprite-ot, akkor pedig az ezt követő sprite bájtokat kezdi el vizsgálni (csempe attribútum) (65-256 órajel). \Aref{fig:sprite-rendering-FSM}. állapotgépben ez a négy túlcsordulási állapotnak felel meg.
		\item Végül az utolsó lépésben az aktív sprite adatok kiolvasása és mentése következik (257-320 órajel). \Aref{fig:sprite-rendering-FSM}. állapotgépben ez a három sprite adat olvasási állapotnak felel meg.
	\end{enumerate}

	\Aref{fig:sprite-rendering-FSM}. ábrán látható állapotgép két extra állapottal bővül ki az FPGA rendszer szinkronizációja miatt. Az első két állapot (OAM IDLE és SCANLINE WAIT) a VGA jel generálás alatti IDLE állapotot reprezentálja (hasonlóan \aref{fig:bg-rendering-FSM}. SLEEP állapotához). Illetve a HBLANK WAIT állapot, amely a túlcsordulás figyelést követően szinkronizálja, az állapotgép működését.

	Az állapotgép negyedik szakasza teljes mértékben szinkron működik a háttér képalkotást vezérlő állapotgép Pattern adat olvasásával. Az innen kiolvasott két bájtos csempe adatokat egy-egy pufferbe mentjük, ha kevesebb mint 8 aktív sprite van egy sorban, akkor a fennmaradó puffer területek nullás értéket kapnak. A pufferek léptetőregiszterként tárolják a csempe adatokat és figyelik a képalkotás horizontális számlálóját, ha az aktuális sprite X koordinátája megegyezik a sor indexszel, akkor elkezdődik a 8 pixelnyi képadat léptetése és kiadása. Ha a $sprite\_clipping$ jel aktív akkor az első csempe oszlop (8 pixel) időtartalma alatt nem történhet mozgó csempe megjelenítés, tehát ezeknek a sprite-oknak az értéke nullázódik. %ezt nem értem
	Ennek segítségével tudunk szép folyamatos bal oldali görgetést létrehozni.
	
	Végül a pufferekből érkező sprite pixelei között meghatározzuk a prioritási sorrendet és a nagyobb prioritással rendelkező pixel adatait adjuk ki a sprite képalkotási modulból. A prioritást az elsődleges OAM memóriában való elhelyezkedés határozza meg, a nulladik sprite-nak van a legnagyobb prioritása és a 63.-nak pedig a legkisebb (tehát minél előbb kerül a másodlagos OAM-ba a sprite annál nagyobb a prioritása).
	
	A játékok hibátlan emulálása szempontjából elengedhetetlen még a $sprite_0\_hit$ vezérlőjel pontos előállítása. Ha ezt nem pontosan hozzuk létre, egyes játékok, többek között a Super Mario Bros. a kezdő képernyőn ragad és nem kezd el futni a teljes szoftver (valószínűleg egy várakozó állapotban ragad a program). A jel egyik komponensét a $sprite_0\_visible$ jelet, a sprite képalkotást vezérlő modulon belül, \aref{code:sprite0-visible}. hardverleírásban látható módon hozom létre. A végső $sprite_0\_hit$ jel pedig a logikai és kapcsolata, a $sprite_0\_visible$, $visible\_bg\_pixel$ és a $sprite_0\_check$ jeleknek. A látható háttér pixel, a nem átlátszó háttér pixeleket vizsgálja, a $sprite_0\_check$ pedig azt, hogy a horizontális képalkotás elért-e a 255. pixelig. %ezt nem értem

\begin{lstlisting}[caption={A $sprite_0\_visible$ vezérlőjel előállítása}, label={code:sprite0-visible}, style=prettyverilog]
reg [1:0] sprite0_in_range;
assign sprite0_visible = sprite0_in_range[1] & |sprite_pixel[1:0] & ~(~sprite_enabled | (first_column & ~no_sprite_clip)); 

always @(posedge clk) 
begin
	if (rst)
		sprite0_in_range <= 2'd0;
	else
		if (scanline_begin)
			sprite0_in_range <= {sprite0_in_range[0], 1'd0};
	else
		if (odd_phase_en && (oam_state == OAM_COPY_X_COORD) && (n_cnt == 6'd0))
			sprite0_in_range <= {sprite0_in_range[1], 1'b1};
end\end{lstlisting} 

	\subsection{PPU adatbusz és memória elérése}
	
	A PPU működéséhez elengedetlen a VRAM cím regiszterének képzése is, ennek felépítése kétrétegű (az eredeti PPU mintájára). Az első réteg \aref{sec:CPU-databus-ppu_reg}. fejezetben leírtak alapján a CPU adatbuszról érkező regiszter írások hatására regiszterekbe menti a VRAM címrészleteket, ennek a pontos változásai \aref{fig:2000-2005-2006-ppu-reg-writes}. ábrán láthatók (t regiszterként). A második réteg pedig a képgenerálás során képződő számlálást és a soron kívüli regiszter töltéseket és fölfelé számolásokat foglalja magába (\aref{fig:2000-2005-2006-ppu-reg-writes}. ábrán v regiszternek felel meg).
	
	A címszámláló réteg különleges olyan szempontból, hogy megkülönböztet két fajta felfelé számolási sorrendet. Az első a standard számlálás, amikor a cím két része a horizontális és a vertikális külön-külön számolnak felfelé, mint két különálló regiszter. Ezt a számlálási módot használja a PPU \aref{sec:NTSC-PPU-frame}. függelékben látható vörössel kiemelt pixelek megjelenítése során, tehát az általános képgeneráláskor. A második számlálási mód esetén a VRAM írása vagy olvasása hatására egy felfelé számlálás történik, itt a teljes VRAM címregiszter számol fölfelé 1-et vagy 32-t a (a számlálási mód függvényében). 
	
	\begin{figure}[H]
	\centering
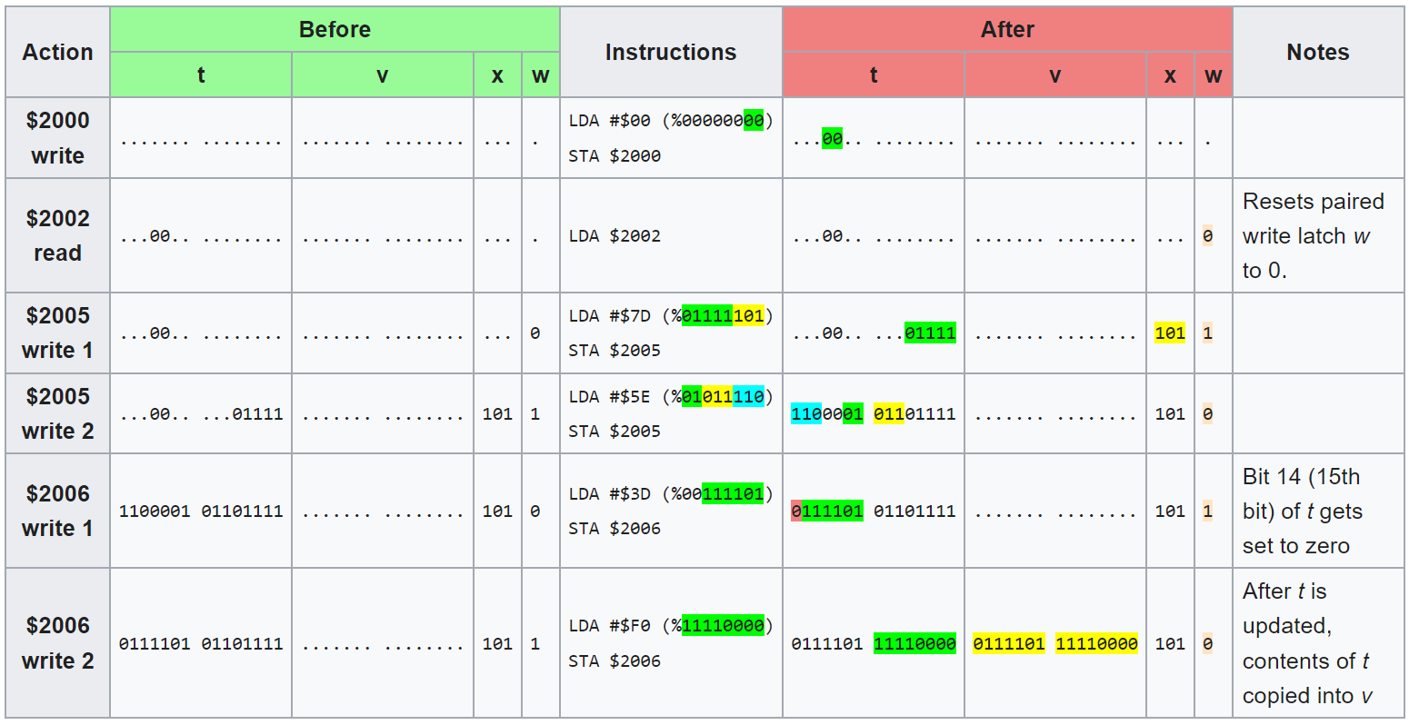
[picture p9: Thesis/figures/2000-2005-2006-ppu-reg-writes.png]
	
	\caption{VRAM cím regiszter értékadása (eredeti PPU)} 
	\label{fig:2000-2005-2006-ppu-reg-writes}
	\end{figure} 
	
	A \ref{sec:NT-AT-mirroring}. fejezetben leírtak alapján a VRAM címszámláló regiszterekből hozom létre a név tábla és attribútum tábla címeit. Majd az NT  állapotban kiolvasott Pattern cím adatok segítségével létrehozom a háttér csempeadatok olvasási címét. A sprite állapotgépből érkező adatok alapján a $sprite\_size$-nak megfelelően állítom elő sprite Pattern címeket, a 8 aktív csempeadat kiolvasása számára. A pontos címképzéseket \aref{code:VRAM-addr}. hardverleírásban olvashatjuk.
	
\begin{lstlisting}[caption={VRAM cím képzése a számlálókból és az állapotgépek alapján}, label={code:VRAM-addr}, style=prettyverilog]
wire [13:0] ppu_nt_addr = {2'b10, v_cnt, h_cnt, vt_cnt, ht_cnt};
wire [13:0] ppu_at_addr = {2'b10, v_cnt, h_cnt, 4'b1111, vt_cnt[4:2], ht_cnt[4:2]};
wire [13:0] bg_lsb_addr = {1'b0, background_pattern_sel, tile_index_reg, 1'b0, fv_cnt};
wire [13:0] bg_msb_addr = {1'b0, background_pattern_sel, tile_index_reg, 1'b1, fv_cnt};

assign sprite_lsb_addr = (~sprite_size) ? ({1'b0, sprite_pattern_sel, sprite_tile_index, 1'b0, sprite_range[2:0]}) : ({1'b0, sprite_tile_index[0], sprite_tile_index[7:1], sprite_range[3], 1'b0, sprite_range[2:0]});
assign sprite_msb_addr = (~sprite_size) ? ({1'b0, sprite_pattern_sel, sprite_tile_index, 1'b1, sprite_range[2:0]}) : ({1'b0, sprite_tile_index[0], sprite_tile_index[7:1], sprite_range[3], 1'b1, sprite_range[2:0]});\end{lstlisting}

	A PPU (mester) busz cím regiszterének meghajtása során figyelembe kell vennünk azt, hogyha a chipen bármilyen VRAM elérést hajtanak végre, akkor a címregisztert ne a VRAM címszámláló rétegéből határozzuk meg, hanem egy extra regiszteren a $vram\_addr\_reg$-en keresztül adjuk ki, ezzel késleltetve a címünket egy órajellel. Ez az eredeti NES PPU-ban is egy hardveres hiba volt, amit játékok fel is használtak (például a Super Mario Bros.). Abban az esetben is, ha a háttér vagy a sprite képalkotás nincs kiválasztva tehát $ppu\_enable$ inaktív, automatikusan a késleltetett VRAM címet kell kiadni. 
	
	A végső cím kimenetet még szinkronizálnunk kell a chip többi részéhez, erre szolgál az $addr\_reg\_ld$ jel. A busz címregiszterének képzését \aref{code:PPU-master-databus-addr}. hardverleírásban láthatjuk részletesebben.

\begin{lstlisting}[caption={PPU master adatbusz címregiszterének meghajtása és időzítése}, label={code:PPU-master-databus-addr}, style=prettyverilog]
wire vram_address_sel = (vram_state_machine_sel == VRAM_RD_WAIT) || (vram_state_machine_sel == VRAM_WR_WAIT);
wire [7:0] ppu_address_sel;
wire addr_reg_ld = (x_rendercntr[2:0] == 2'b100);

assign ppu_address_sel [0] = vram_address_sel;
assign ppu_address_sel [1] = (bgrender_state == NT);
assign ppu_address_sel [2] = (bgrender_state == AT);
assign ppu_address_sel [3] = (bgrender_state == BG_LSB) & sprite_read;
assign ppu_address_sel [4] = (bgrender_state == BG_MSB) & sprite_read;
assign ppu_address_sel [5] = (bgrender_state == BG_LSB) & ~sprite_read;
assign ppu_address_sel [6] = (bgrender_state == BG_MSB) & ~sprite_read;
assign ppu_address_sel [7] = ppu_enable;

always @(posedge clk) 
begin
	if (rst)
		ppu_mem_addr <= 14'd0;
	else
		if (addr_reg_ld)
			case (ppu_address_sel)
				8'b10000010 : ppu_mem_addr <= ppu_nt_addr;
				8'b10000100 : ppu_mem_addr <= ppu_at_addr;
				8'b10001000 : ppu_mem_addr <= sprite_lsb_addr;
				8'b10010000 : ppu_mem_addr <= sprite_msb_addr;
				8'b10100000 : ppu_mem_addr <= bg_lsb_addr;
				8'b11000000 : ppu_mem_addr <= bg_msb_addr;
				default		: ppu_mem_addr <= vram_addr_reg;
			endcase
end\end{lstlisting}

	\subsection{A PPU képgenerálás működése}
	
	A háttér állapotgép működése során kiolvasott csempe adatok feldolgozása hasonlít a sprite pixel feldolgozásra, azzal a különbséggel, hogy ennek folyamatosnak kell lennie a háttér képalkotás ideje alatt. Ezt az FPGA modulon belül egy különleges hardveres elemmel, egy LUT-ban szintetizálódó léptetőregiszterrel, SRL-el (shift register LUT) oldottam meg. %szerintem itt zárójelezni kell az srl-től kezdve
	Az általános léptetőregiszterekhez képest ebben az elemben a teljes regiszter töltése nem engedélyezett, csak a regiszterek bitszélességével történő egy bites léptetéses töltés. %ezt nem érte
	Ennek előnye, hogy könnyen összeszinkronizálható a háttér csempék két bájtja (mivel az LSB és MSB bájtok bit párjai alkotják a háttér egy pixelét). A regiszterek kimeneteként pedig bármelyik bitpár kiválasztható. A kimenet választás azért fontos, mert a görgetés során egy csempét pixelekként szeretnénk kigörgetni a megjelenített képtartományból. Ilyen SRL-t használtam a csempe attribútumának megjelenítésére is. Ezt az adatfeldolgozó láncot olvashatjuk \aref{code:SRL-shiftregs}. hardverleíró részletben.
	
	\begin{figure}[H]
	\centering
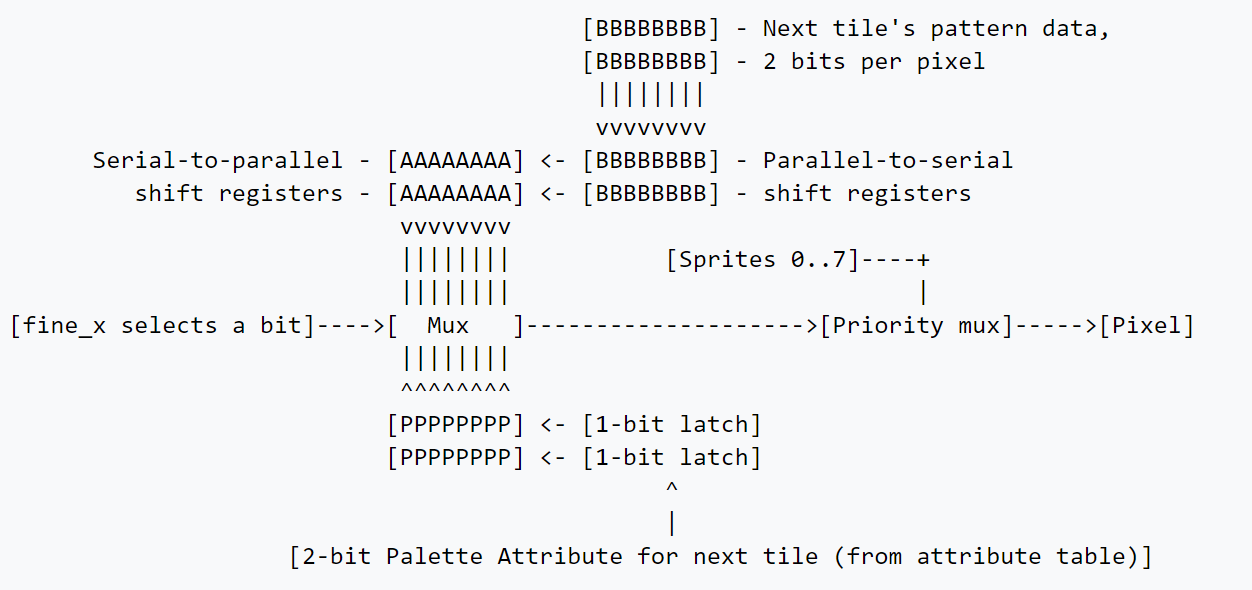
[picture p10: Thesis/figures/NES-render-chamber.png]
	
	\caption{A NES PPU-jának pixel feldolgozó egysége} 
	\label{fig:NES-render-chamber}
	\end{figure} 
	
	Az állapotgépek pixel feldolgozó egysége és működése nagyban hasonlít az eredeti hardver felépítésére, ezt \aref{fig:NES-render-chamber}. ábrán láthatjuk. A PPU két állapotgépe (háttér és sprite) során kapott pixel adatok összefűzésének és feldolgozásának három fő fázisa van: %ezt nem értem
	
	\begin{enumerate}
		\item \emph{Prioritás vizsgálat, végső pixel meghatározása:} A sprite képalkotás kétféleképpen történhet: a mozgó csempe elem kerülhet a háttér elé, illetve a háttér mögé. Erről a csempe prioritása dönt (ha 1 akkor a háttér mögé kerül a mozgó elem), ennek segítségével alkották meg a játékfejlesztők például a Mario húsevő növényeit. A pixel kiválasztás során még figyelembe kell venni hogy a háttér pixel átlátszó-e, ebben az esetben mindenképpen a sprite képkockáját válasszuk. Ezt a kiválasztási folyamatot láthatjuk \aref{code:SRL-shiftregs}. hardverleíró részlet alján.
		\item \emph{Paletta lookup táblázat:} Az így kiválasztott pixel egy paletta címet képez, a NES CPU-ja által feltöltött Paletta lookup táblázatban. Ennek működéséről olvashattunk \aref{sec:Pattern-tables-and-palettes}. fejezetben. Az FPGA-ban történő megvalósítás során elosztott memóriát használtam, a késleltetés mentes olvasás miatt. A helyes emulálás során különösen figyelnünk kell a memória területek helyes tükrözésére, ha ezt nem jól implementáljuk egyes játékok színei nagyban eltérhetnek az eredetitől, például a Mario háttere kék helyett fekete lesz. Ennek helyes implementálását olvashatjuk \aref{code:palette-mirroring}. hardverleírásban. Ha a $BG\_clipping$ jel aktív és az első csempe oszlopban vagyunk, vagy a PPU várakozó állapotban van (\ref{fig:bg-rendering-FSM}. SLEEP állapota), akkor automatikusan egy fekete pixel értékével helyettesítjük a palettából olvasott címet.
		\item \emph{RGB blokk ROM:} Az FPGA implementálás során a paletta memóriából kiolvasott színértéket egy címként értelmeztem. Ennek feldolgozásához készítettem egy RGB adatokkal előre feltöltött ROM-ot, amely a címhez a megfelelő 24 bites RGB értéket rendeli. Itt még figyelembe vettem a NES képalkotást befolyásoló két funkciót. Az első a monokróm mód, amely fekete fehér képalkotást tesz lehetővé. Ezt úgy implementáltam, hogy a palettából kiolvasott cím, hue értékének megfelelő biteket nullával helyettesítem. A második ilyen mód pedig, a szín kiemelés (a PPU képes volt, adott színek kiemelésére és a többi szín elsötétítésére). Ezt a tulajdonságot úgy implementáltam, hogy a Paletta ROM címébe beletartoznak az $emphesize\_r / -\_g / -\_b$ jelek, így egy kicsit nagyobb blokk ROM-ot képezve a hardverben.
	\end{enumerate} 
	
\begin{lstlisting}[caption={Pixel adat feldolgozó SRL léptetőregiszterek}, label={code:SRL-shiftregs}, style=prettyverilog]
//LSB of backgorund pixel
reg [7:0] bg_lsb_buff_reg;
always @ (posedge clk) 
begin
	if (rst)
		bg_lsb_buff_reg <= 8'd0;
	else
		if (bg_msb_read)
			bg_lsb_buff_reg <= bg_lsb_reg; // shift reg
		else if ((x_rendercntr[1:0] == 2'b11) && (x_rendercntr > START_OF_SHIFT) && (x_rendercntr <= END_OF_SHIFT) && ~(bgrender_state == VBLANK))
			bg_lsb_buff_reg <= {bg_lsb_buff_reg[6:0], 1'b0}; 
end
reg [7:0] shr_lsb_render = 8'd0;
wire	  bg_lsb_out;  
always @(posedge clk) 
	if ((x_rendercntr[1:0] == 2'b11) && (x_rendercntr > START_OF_SHIFT) && (x_rendercntr <= END_OF_SHIFT) && ~(bgrender_state == VBLANK))
		shr_lsb_render <= {shr_lsb_render[6:0], bg_lsb_buff_reg[7]};
assign bg_lsb_out = shr_lsb_render[~fh_reg];
//MSB of background pixel
reg [7:0] shr_msb_render = 8'd0;
wire	  bg_msb_out;  
always @(posedge clk) 
	if ((x_rendercntr[1:0] == 2'b11) && (x_rendercntr > START_OF_SHIFT) && (x_rendercntr <= END_OF_SHIFT) && ~(bgrender_state == VBLANK))
		shr_msb_render <= {shr_msb_render[6:0], bg_msb_reg[7]};
assign bg_msb_out = shr_msb_render[~fh_reg];

//0 bit of attribute
reg [7:0] shr_attr0_render = 8'd0; 
always @(posedge clk) 
	if ((x_rendercntr[1:0] == 2'b11) && (x_rendercntr > START_OF_SHIFT) && (x_rendercntr <= END_OF_SHIFT) && ~(bgrender_state == VBLANK))
		shr_attr0_render <= {shr_attr0_render[6:0], tile_attr_reg_saved[0]};
wire shr_attr0_out = shr_attr0_render[~fh_reg];
//1 bit of attribute
reg [7:0] shr_attr1_render = 8'd0; 
always @(posedge clk) 
	if ((x_rendercntr[1:0] == 2'b11) && (x_rendercntr > START_OF_SHIFT) && (x_rendercntr <= END_OF_SHIFT) && ~(bgrender_state == VBLANK))
		shr_attr1_render <= {shr_attr1_render[6:0], tile_attr_reg_saved[1]};
wire shr_attr1_out = shr_attr1_render[~fh_reg];

//pixel output
reg [3:0] bg_pixel;
always @(posedge clk) 
begin
	if (rst)
		bg_pixel <= 4'b0;
	else
		bg_pixel <= {shr_attr1_out, shr_attr0_out, bg_msb_out, bg_lsb_out};		
end
wire [4:0] palette_addr = 	(sprite_priority & visible_bg_pixel) ? ({1'b0, bg_pixel}) : ({1'b1, sprite_pixel});\end{lstlisting}

\begin{lstlisting}[caption={A paletta címek tükrözése}, label={code:palette-mirroring}, style=prettyverilog]
wire [4:0] palette_ram_nt_addr_mirrored = {vram_addr_cnt[4] & |vram_addr_cnt[1:0], vram_addr_cnt[3:0]};									
wire [4:0] palette_ram_addr_mirrored = {palette_addr[4] & |palette_addr[1:0], palette_addr[3:0]};\end{lstlisting}

	\subsection{A VGA képalkotás}
	
	A PPU véső hardveres eleme az RGB adatokat tároló és megjelenítő VGA modul, ennek felépítését láthatjuk \aref{fig:vga-rendering-top}. ábrán. 
	
	\begin{figure}[H]
		\centering
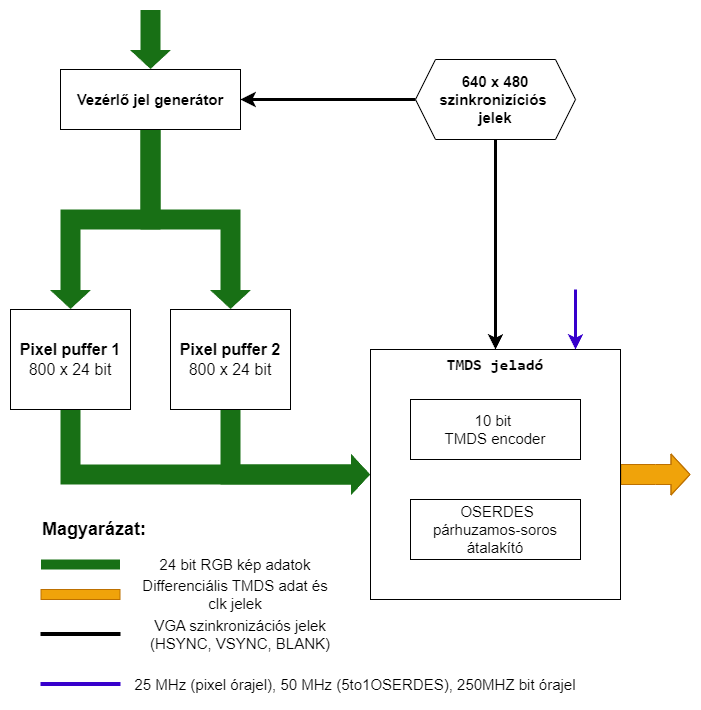
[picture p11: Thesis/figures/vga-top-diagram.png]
		
		\caption{VGA top modul blokkvázlata} 
		\label{fig:vga-rendering-top}
	\end{figure} 

	A PPU bemutatása során \aref{sec:PPU-FPGA}. fejezetben már megismertük a chip áttervezésének alapötletét. Ezek alapján a PPU egy képalkotási sora alatt (1600 órajel) a pixeleket minden második órajelben mintavételezve kapjuk meg a 800 pixel széles VGA kép egy sorát. Majd a következő képsor mintavételezése alatt, az előzőekben mintavételezett kép sort kétszer kiadva hozzuk létre az eredeti NES pixelek nagyítását. Így kapjuk meg a 640x480-as VGA kép két sorát. Így a VGA kép egy sor késésben lesz a PPU képalkotáshoz képest, viszont helyes indulási időzítések mellett, ez nem észrevehető. Puffereket egy-egy kilobájtnyi blokk RAM-ként alakítottam ki a VGA modulon belül, mivel az így kiolvasott adatok egy órajelnyi késleltetése nem okoz semmilyen extra csúszást a VGA időzítésben. Ez a dupla pufferelés látható \aref{fig:vga-rendering-top}. ábrán is, természetesen ezek közül egyszerre csak az egyik puffer kimenet aktív és a két puffer kimenetei dinamikusan váltják egymást a PPU-ban történő képsorok számának növekedésével.
	
	A TMDS jeladó és a pufferek töltésének kezdetét vezérlőjelek időzítése különösen fontos, hiszen ezek segítségével vagyunk képesek a PPU aktív képtartományát pozicionálni a VGA pixel sor közepére. A pixel kétszerezést követően a PPU aktív képtartománya 512 pixel órajelig tart. Tehát A helyes időzítéshez 64 pixel órajelig fekete pixelt kell a TMDS adónak venni, majd következik az 512 pixelnyi aktív rész, végül pedig 224 képkockányi fekete pixel, ez a tartomány tartalmazza a horizontális kioltási területeket is. Ezt a képkocka arányt határozza meg \aref{fig:bg-rendering-FSM}. háttér állapotgépben, a SLEEP állapotból történő kilépés időzítése. Illetve a puffer töltés kezdetének meghatározásával, még finomhangolható a kép pontos beállítása. Ahhoz, hogy a kezdetektől fogva helyes kép jelenjen meg a monitorunkon, a VGA szinkronizálási jelek generálását is kellett késleltetnem a pre-rendering sor és az első puffer feltöltésének idő tartalmával. Ezt az időzítést egy reset jelre nullázódó számláló segítségével oldottam meg, amely 3201 pixel órajelet (két teljes PPU sor + 1 pixel órajel) követően engedélyezi a generálást. A szinkronizációs jelek pontos időzítése a pixel órajelhez képest \aref{code:vga-timing}. hardverleírásban látható. 
	
\begin{lstlisting}[caption={A képgenerálás időzítési paraméterei}, label={code:vga-timing}, style=prettyverilog]
localparam H_BLANK_BEGIN     = 10'd639;
localparam H_SYNC_BEGIN      = 10'd655;
localparam H_SYNC_END        = 10'd751;
localparam H_BLANK_END       = 10'd799;

localparam V_BLANK_BEGIN     = 10'd479;
localparam V_SYNC_BEGIN      = 10'd489;
localparam V_SYNC_END        = 10'd491;
localparam V_BLANK_END       = 10'd523;\end{lstlisting}
	
	TMDS adók két fő elemből épülnek fel. Minden színcsatorna tartalmaz egy 10 bites TMDS kódolót, amely az RGB adatokat, csatornánként (8 bit) egy 10 bites kiadható jellé kódolja. Ezek közül egyedül a kék színcsatorna tartalmazza a hsync, vsync jeleket. Majd ezt követően, ezeket a 10 bites adatokat öt az egyhez sorosítókon (OSERDES) keresztül egy-egy kimeneti puffer (OBUF) alakítja át a differenciális p és n jelekké. Az OSERDES vezérlő strobe-ja 50 MHz-en működik, a kiadott bitek pedig 250 MHz-el jönnek. A VGA jel szinkronizációs jeleiről és a TMDS adók működéséről részletesebben  \acite{vgalogsys} irodalomban olvashatunk, ennek alapján hoztam létre én is a TMDS jeladót.

\section{NES memória felépítése az FPGA-ban}

A memória menedzser modul fejlesztése, során \aref{sec:fpga-desing-begining}. fejezet bevezetésében leírt alapelveket követve, az egyszerűséget és a gyors, könnyű tesztelhetőséget előtérbe helyezve, a játék kazettákon található karakter és program ROM-okat is a modulon belül blokk ROM-ként helyeztem el. \Aref{sec:fpga-nes-board-summary}. FPGA kártya ismertetése során kitértem a Spartan-6-ban található blokk RAM-ok számára, ez 32 db 8 kilobites blokk RAM (64 kilobájt). A NES FPGA hardverhez, legnagyobb mapper chip nélküli játék esetén a következő memória területek szükségesek:

\begin{itemize}
	\item 32 kilobájt program ROM (játék kártya), 
	\item 8 kilobájt CH ROM (játék kártya),
	\item 2 kilobájt cpu work RAM (alaplap),
	\item 2 kilobájt név tábla memória (alaplap),
	\item 2 kilobájt vga képalkotás pufferek (PPU),
	\item 512 * 3 bájt paletta RAM (PPU).
\end{itemize}

A fentebbiekből kiszámolható, hogy a kezdeti teszteléshez nem szükséges, hogy a játék kártyák memória területét SRAM-ban helyezzem el, mivel a Super Mario Bros. esetén is (32 kilobájt program ROM), még marad 16 kilobájt blokk RAM a hardverben. Ennek az egyszerűsítésnek a segítségével a teszteléshez nem kell lefejleszteni a 6502-es processzorhoz egy UART interfészt (és az ehhez szükséges szoftvereket), hogy ezen keresztül töltsük fel a SRAM memória területeit a játékprogram indítása előtt. 

A játék kártyákon található ROM területek implementálása során figyelembe vettem, hogy a blokk RAM-jaim elérési ideje ugyanakkora legyen, mintha az SRAM-ot érnénk el, így a jövőben könnyen kiegészíthetővé és cserélhetővé válik ez a hardveres modul. Az egységesítés miatt az NT RAM elérési idejét is ugyanennyire állítottam be, így a PPU memória eléréseinek időzítése során csupán egyféle időzítésre kellett figyelnem. Ez a gyakorlatban azt jelentette, hogy a memória olvasások két órajel késleltetéssel jelennek meg a kimeneten, az írások pedig egy órajel időtartam alatt valósulnak meg (ez megfelel az SRAM 10 ns-os elérési idejének). Az olvasás késleltetését egy pufferregiszterrel valósítottam meg.

A memória menedzser teljes adatbusz interfészeket implementál, ami azt jelenti, hogy a teljes címet megkapja a CPU (16 bit) és a PPU (14 bit) felől a modul. A különböző memóriák kiválasztása és címének meghatározása \aref{tab:PPU-memory}. és \ref{tab:CPU-Memory}. táblázatok alapján \aref{code:memory-addresing}. hardverleírásban olvasható.

\begin{lstlisting}[caption={A memória menedzserben található memória területek címzése}, label={code:memory-addresing}, style=prettyverilog]
wire [10:0]	cpu_work_ram_addr = cpu_addr[10:0];			 	 //cpu inner memory access
wire		cpu_work_ram_sel  = (cpu_addr[15:13] == 3'b000); //0x0000-0x07FF and the mirrors until 0x1FFF

wire [14:0]	cpu_prog_rom_addr = cpu_addr[14:0];			 
wire		cpu_prog_rom_sel  = cpu_addr[15]; 

wire [11:0]	ppu_name_table_addr = {ppu_name_table_addr_h, ppu_addr[9:0]};
wire		ppu_name_table_sel = ppu_addr[13];

wire [12:0] ppu_ch_rom_address = ppu_addr[12:0];
wire		ppu_ch_rom_sel = ~ppu_addr[13];\end{lstlisting}

A jövőbeli könnyebb kibővíthetőség érdekében a PPU névtábla tükrözései közül az összeset implementáltam, illetve fenntartottam egy extra helyet különlegesebb mapper-ek tükrözései számára. Jelenleg a tükrözést a modulban egy paramétereként állíthatjuk, de a jövőben ezt a mapper chip, illetve a játék program fogja állítani. A tükrözések működéséről és felhasználásáról részletesebben olvashatunk \aref{sec:NT-AT-mirroring}. fejezetben, ezek implementálását pedig, \aref{code:nt-address-mirroring}. hardverleírásban láthatjuk. 

\begin{lstlisting}[caption={A PPU görgetéshez használt névtábla tükrözés}, label={code:nt-address-mirroring}, style=prettyverilog]
reg  [1:0] 	ppu_name_table_addr_h;
reg	 [1:0]	mapper_mirroring; //in the future if we have a mapper

always @ (*)
begin
	case (NT_MIRRORING)
		// Horizontal Mirroring
		2'b00: ppu_name_table_addr_h <= {1'b0, ppu_addr[11]};
		// Verical Mirroring
		2'b01: ppu_name_table_addr_h <= {1'b0, ppu_addr[10]};
		// Mappers Mirroring
		2'b10: ppu_name_table_addr_h <= mapper_mirroring;
		// Four-screen mirroring 
		2'b11: ppu_name_table_addr_h <= {ppu_addr[11:10]};
	endcase
end\end{lstlisting}

%phi?
A CPU memória elérésének csupán a blokk RAM egy órajeles késleltetése van, viszont az adatbusz meghajtása során figyelni kell, hogy a $\phi_2\_falling$ jel hatására nullába kell állítanunk a modul kimenetét (a top modulban az adatbuszok összefűzésének érdekében).

\section{DMA - FPGA megvalósítása}

Az eredeti DMA működéséről \aref{sec:DMA}. fejezetben olvashatunk. A DMA modul létrehozása során a legnagyobb kihívást a pontos időzítés megvalósítása jelentette. \Aref{fig:FPGA-toplevel-diagram}. ábrán is látható módon, ha a DMA-t eléri a CPU, akkor ezt követően a DMA átveszi a CPU adatbuszát, viszont ennek szinkronban kell végbemennie a többi hardveres elem miatt. Ennek megoldása érdekében a modul egy speciális bemenettel rendelkezik, amely a CPU órajel ciklusának paritását vizsgálja. \Aref{fig:sprite-dma-FSM}. ábrán szemléltetett állapotgépben látható is, hogy ez az órajel illesztést egy speciális késleltetéssel oldottam meg, ha páratlan ciklusban érkezett a CPU kérése akkor két teljes CPU órajelet várunk, ha párosban akkor csak egyet. Ezzel pontosan annyi ciklus időt hagyva a processzor számára, hogy befejezze a jelenlegi feladatait.

A CPU adatbuszt a processzor ready jelének elvételével és a DMA $valid\_address$ vezérlőjel egybe állításával veszi el. A többi része az adatbusznak egyszerű logikai vagy műveletek segítségével összevonható \ref{code:cpu-data-bus}. hardverleírás. 

\begin{figure}[H]
\centering
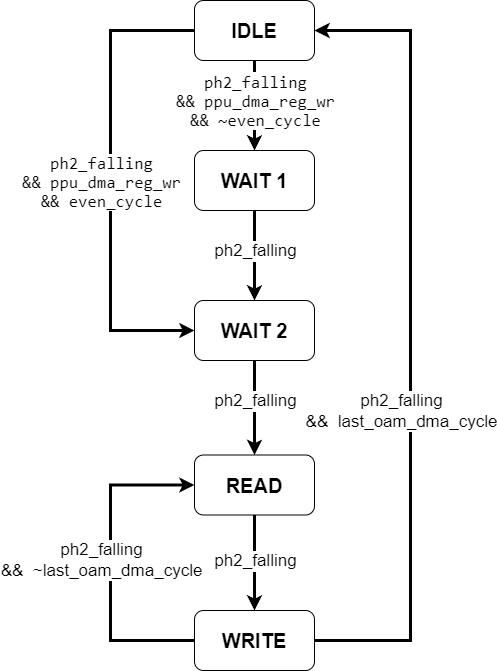
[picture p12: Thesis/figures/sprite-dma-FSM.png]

\caption{OAM DMA működési állapotgépe} 
\label{fig:sprite-dma-FSM}
\end{figure}

Ezt a szinkronizációs problémát leszámítva a hardver működése egyszerű. A CPU a DMA elérése során egy címet ad az eszköznek, amely a CPU munka memóriájának egy területére mutat, általában \$0200. Majd innen az olvasási és írási állapotok váltakozásával 64 * 4 bájt memória mennyiséget olvas és ír (a teljes elsődleges OAM memóriát). Az írás a PPU \$2004-es OAM data regiszterére történik, ennek feldolgozását \aref{sec:fpga-sprite-rendering}. fejezetben olvashatjuk.

A memória terület másolását követően az eszköz visszaadja a CPU címbuszát és master adatbusz kimeneteit visszaállítja nullára, ezzel elengedve a CPU adatbuszt. %itt a ragozás nem jó

Egy DMA ciklus teljes szimulációját \aref{fig:Full-dma-working-in-simulation}. ábrán láthatjuk, már itt is megfigyelhető, hogy a ready jel elvételét követően a DMA címbusza elkezd adni és ezek az értékek kerülnek ki a CPU összesített címbuszára. \Aref{fig:Working-dma-in-simulation}. szimulációs ábrán pedig egy DMA ciklus kezdetét láthatjuk. Itt nyomon követhetjük a címbuszok pontos tartalmát. Tehát láthatjuk, hogy a DMA \$0200 címről kezd el olvasni (ezt a címet ciklusonként növeli) és a \$2004-es címre pedig ír. Az írás és olvasás váltakozását pedig az RNW jel váltakozása mutatja. 

\begin{figure}[H]
	\centering
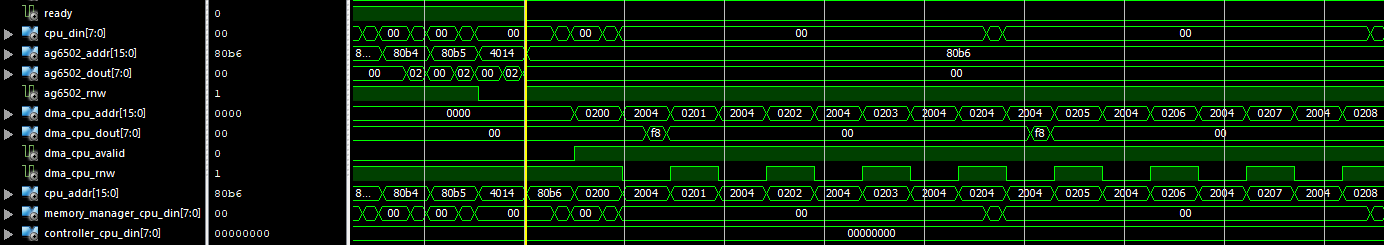
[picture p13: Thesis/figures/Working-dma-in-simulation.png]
	
	\caption{A DMA ciklus kezdete szimulációban} 
	\label{fig:Working-dma-in-simulation}
\end{figure} 

\begin{figure}[H]
	\centering
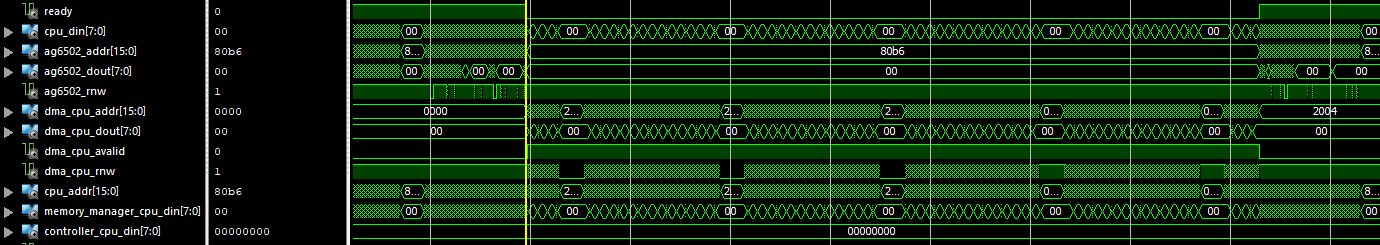
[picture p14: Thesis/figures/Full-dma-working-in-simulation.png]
	
	\caption{Teljes DMA ciklus szimuláció} 
	\label{fig:Full-dma-working-in-simulation}
\end{figure} 

\section{6502 processzor működése az FPGA rendszerben}

A PPU és az eddig elkészített hardveres elemek tesztelhetősége végett a projekt ezen fázisában inkább különböző nyílt forráskódú (Open Source) processzorokat próbáltam a rendszerbe illeszteni. Itt nagy segítségemre volt az OpenCores nevű weboldal \cite{OpenCore}, amely különböző nyílt forráskódú processzorok és hardveres eszközök hardverleírását tartalmazza. Illetve a szintén nyílt forráskódú Mister NES projekt \cite{MisterNES}, amely rendelkezik egy VHDL nyelven íródott processzorral. Ezek forráskódjai, azért nem tökéletesek, sok módosításra és javításra szorulnának a meglévő rendszerbe történő illesztésük során. Ez nagyon időigényesnek érződött, ezért konzulensemhez fordultam segítségért. Szerencsére Raikovitch Tamás el tudott látni egy általa készített és a karbantartott 6502-es processzor Spartan-6-osra szintetizált és implementált processzor binárisával a tesztelésekhez. Ez egy régebbi projektje során használt megbízható processzor implementációnak bizonyult, amelyet könnyen be tudtam illeszteni az eddig implementált rendszerbe. \Aref{fig:working-cpu-simulation}. szimulációs ábrán jól látható, hogy a rendszer helyesen olvassa be a Super Mario első utasítását, ez körülbelül a kép közepén a $cpu\_din$ csatornáján, 78-as (hexa) assembly kód. 

\begin{figure}[H]
	\centering
	
	\caption{A CPU szimulációja működés közben, Super Mario Bros. első assembly kódjának olvasása} 
	\label{fig:working-cpu-simulation}
\end{figure} 

A CPU-nak köszönhetően a tesztelések során biztos lehettem abban, hogy csak az általam létrehozott rendszerben van hiba és a processzor teljes mértékben jól működik. Ezt követően könnyebb lesz egy nyílt forráskódú vagy egy saját 6502 illesztése a NES-embe mivel biztos lehetek, hogy az általam készített hardver helyesen, az eredeti NES-nek megfelelően működik (így könnyebb a CPU hibáinak megtalálása). 

\section{NES kontrollerek kezelése}

Az eredeti NES kontrollerek működését \aref{sec:NES-controller}. fejezet során már ismertettem. Az FPGA implementáció során a modul feladata a kontrollerek párhuzamos-soros léptetőregiszterei felé a vezérlőjelek küldése, tehát az olvasási szándék jelzése ($controller\_out\_latch$), illetve a bitek olvasását követő órajelek küldése ($controller_1-_2\_out\_clk$). A kontrollerekből érkező adatok mintavételezésére egy felfutó él érzékelést készítettem a CPU \$4016-as (kontroller 1) és \$4017-as (kontroller 2) regiszterek olvasásának detektálására annak érdekében, hogy mindig stabil adatokat olvassunk (az olvasás egyszer történjen meg). Az élérzékelést egy-egy kétbites léptetőregiszterrel implementáltam, amelyekbe egyes értéket léptetek a jelek érzékelésekor.   

%phi
A kontrollerekből érkező egybites adatokat, a CPU egy bájtként olvassa ki (az adat a 1. helyi értékű %nem 1-es helyi érték? 0-s nincsen
biten szerepel). A CPU adatbusz kezelése során itt is figyeltem az interfész helyes implementációjára, tehát a $\phi_2\_falling$ jel hatására nullás értékre állítom a CPU adat kimeneteket. A modulban mind a két kontroller írását és olvasását elhelyeztem.

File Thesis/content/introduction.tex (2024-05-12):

%----------------------------------------------------------------------------
\chapter{\bevezetes}
%----------------------------------------------------------------------------

Az 1983-ban megjelent Nintendo Entertainment System (NES) 8 bites videojáték konzol a
maga korában igen népszerű volt. A hardverének kialakítása több későbbi, modernebb
videojáték konzolra volt hatással, valamint számos kiemelkedő játékprogram erre a konzolra
készült el először.

A diplomatervem során a NES viszonylag egyszerű, jól átgondolt hardverét valósítottam meg egy olcsóbb, viszonylag kevesebb erőforrással rendelkező FPGA eszközzel. Ennek a megvalósításnak több előnye is van, például ki lehet használni a modern megjelenítő interfészeket (VGA, DVI, HDMI, stb.), valamint az eredeti játékkazetta helyett alkalmazni lehet modern adattároló eszközöket is (SD kártya). Természetesen ezen „továbbfejlesztések” mellett az egyedi változatnak képesnek kell lennie futtatni az eredeti játékprogramokat.

A következőkben a projekt során elkészült egyedi, FPGA alapú NES megvalósítás hardver és szoftveres komponenseinek bemutatását olvashatjuk. Először is az eredeti NES működését, majd a hardver tovább fejlesztését ismerhetjük meg. Ezt követően pedig a FPGA NES továbbfejlesztett alaplapját, és az FPGA-ban elkészült komponensek működését és tesztelését láthatjuk.

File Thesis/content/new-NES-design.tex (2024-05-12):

\chapter{NES FPGA alapú újragondolása}

A diplomaterv projektem egyik fő célja, hogy egy hardveres emulátort készítsek a Nintendo Entertainment System játékkonzolhoz. Alapvetően emulátort lehet készíteni szoftveres, illetve hardveres módon. A szoftveres emulátorok alapja az eredeti hardver szimulálása egy magasabb programozási nyelven íródott szoftver segítségével (pyton, java). Viszont ezek az emulátorok az esetek többségében nem tudják az eredeti hardver időzítésit pontosan betartani, ezért nem teljesen autentikus a játék élmény. Hardveres emulálásnál általában egy FPGA chipet használnak és ebben implementálják az eredeti hardveres működéseket. Az általunk választott megvalósítás sokkal időigényesebb, viszont ennek segítségével képesek vagyunk az eredeti eszköz pontosabb emulálására. Illetve egy erősebb FPGA segítségével modernizálhatunk egy régebbi konzolt is, persze bármilyen hardveres módosítás esetén (amely eltér az eredeti eszköztől) át kell gondolnunk, hogy a megváltozott körülmények között is képesek leszünk-e futtatni az eredeti szoftvereket a hardveren. 

Ebben a fejezetben azt fogom bemutatni, hogy milyen hardveres változtatásokat/fejlesztéseket eszközöltem, az eredeti NES-hez képest, hogy egy friss, modernebb megjelenést adjak az eredeti konzolnak.

\section{Képalkotás}
\label{sec:picture-creation-ideas}

Már az előző \ref{subsec:PPU-CRT}. fejezetben olvashattuk, hogy a NES egy kompozit jelet állított elő CRT televíziók számára. Ez talán a játékkonzol legelavultabb része, hiszen napjainkban már ezt a televízió típust nem is lehet beszerezni. Ezeket teljes mértékben leváltották a VGA alapú (DVI, HDMI, DisplayPort csatlakozóval ellátott) különböző méretű és felbontású lapos TV-k. Ezeknek a megvalósításoknak rengeteg előnye van az analóg megjelenítéssel szemben. Az egyik legjelentősebb, hogy ezen keresztül képesek vagyunk a torzításmentes átvitelre.

A NES eredeti felbontása 256x240 pixel és 60 Hz (NTSC). Ez a  méret sajnos nem felel meg a modern VGA szabványoknak, úgyhogy ezen a téren módosítanunk kell a PPU képgenerálásán. A módosítások során a VGA adatok generálását helyeztem előtérbe. A legkisebb VGA kép méret, amivel érdemes dolgozni és a modern TV-k és monitorok is támogatják, az a 640x480 pixel és 60 Hz. Ebben a méretben pontosan elfér a kétszeres NES képméret. Tehát, ha egy NES pixelt 2x2 pixellel reprezentálunk, akkor 512x480 pixel méretű képet kapunk. Ennél bonyolultabb megoldás is létezik (bilineáris interpoláció), de a sima nagyítás a legegyszerűbb, ezért kezdetben ezt implementálom. Ez a változtatás lehetővé teszi, hogy NES nyomtatott huzalozott kártyáján modern HDMI csatlakozót helyezzek el. 

Illetve ebből a módosításból következőleg a rendszerünk működési frekvenciája is megváltozik, a VGA jelünk pixel órajele 25 MHz lesz, az TMDS adatok pedig 250 MHz-el lesznek továbbítva a TV vagy monitor felé. Ez azt jelenti, hogy a PPU-nk működési órajelét is meg kell változtatni. Ez eredetileg körülbelül 5.37 MHz az NTSC modellben. A NES nyomtatott huzalozott kártyáján, ezért egy magasabb frekvenciájú órajel forrást kell elhelyezni. Az órajel pontos beállítására pedig az FPGA chip DCM (Digital Clock Manager) és PLL (Phase Locked Loop) funkcióit használhatjuk.  

\section{Audio}
%todo fűzd össze a audio bemutatásával
Az audió feldolgozó egység (Audio Process Unit, APU), egy öt különálló hangsávot kezelő analóg komponens, mely a NES eredeti hangját nem lineáris keverés segítségével állította elő. Ezt a jelet a hardveres emulálás során mi egy digitális jelként állítjuk elő az FPGA-val. Ahhoz, hogy az eredeti eszköz hangját élvezni tudjuk, ezt először egy DAC segítségével analóg jellé kell konvertálnunk, végül pedig egy megfelelő erősítőn át egy Jack csatlakozóra kivezetnünk. Az erősítő típusa attól függ, hogy fülhallgatón vagy pedig hangszórón szeretnénk, hogy ezek az ikonikus dallamok megszólaljanak. Jó kompromisszumos megoldás lehet a kártyát fülhallgató erősítővel ellátni, mivel a hangszórókból léteznek olyan modellek (belső erősítővel rendelkezők), amelyek ezzel a gyengébb erősítővel is működnek, így mind a két opció fennáll a konzol használatára. Az eredeti konzol mono hangzással rendelkezett, viszont mi ezt jelet a DAC működése miatt, mind a két fülre kivezethetjük, ezzel sztereó hangzást imitálva (ettől még természetesen ez nem lesz valódi sztereó jel).   

Mivel a NES nyomtatott huzalozott kártyáján már a képalkotás miatt elhelyezek egy HDMI csatlakozót, ezért ennek a videó csatornáin át tudom küldeni a verikális visszafutás ideje alatt az adudió adatokat is. Viszont ehhez szükségem van egy I2C interfészre ahhoz, hogy a megjelenítő EDID ROM-ját ki tudjam olvasni, amelyből megállapítható, hogy képes-e audió adatok vételére az eszköz. Így lehetővé téve, hogy egy esetleges későbbi fejlesztés során a TV vagy monitor beépített hangszóróján szólaljon meg játékkonzolunk. 

\section{Játékok tárolása}
\label{sec:Game-store}
%todo fűzd össze a kazetták bemutatásával
A NES játékok programkódja és Pattern tábla adatai az esetek többségében a játékkazetta saját program és karakter ROM-jában helyezkedtek el. A játékkártyák befogadása rengeteg extra területet emésztene fel a nyomtatott huzalozott kártyán, mert a kazetta befogadó egységet rá kellene tervezni az eszközre, illetve az összes teszt játéknak fizikailag a birtokomba kell lennie ehhez, ebből adódóan az egyéb hardveres teszteket is nehezen lehetne megvalósítani. 

Ennek következtében egy új megoldást kell kitalálni arra, hogy az emulált NES hardvert megfelelő módon ellássam a játékokkal. Az egyik kézen fekvő megoldás, hogy a hordozó kártyára el lehet helyezni egy statikus RAM modult, amelynek elég nagynak kell lennie ahhoz, hogy a játék kártyák karakter és program ROM-ját egyszerre tartalmazza. A legnagyobb NES játék 768 KB memória területtel rendelkezik (Kirby's Adventure), ehhez képest az összes többi játék 512 KB-os vagy ennél kisebb méretű. A NES hardvernek indítás előtt ezt a SRAM-ot fel kell töltenie a játékkal, majd a konzol indítását követően a PPU és CPU innen fog dolgozni.

Annak érdekében, hogy több játékot is képesek legyünk tárolni, érdemes egy nagyobb méretű háttértárat is tervezni az eszközre, amely a játékokat fogja tartalmazni. Erre ideális lehet egy SD kártya. A projekt kezdeti szakaszában ezt még nem használom, viszont az esetleges jövőbeli fejlesztések miatt érdemes, már most a kártyára tervezni egy ilyen olvasót.

A NES hardver belső memória területeit, pedig az FPGA-ban kialakítható Blokk/LUT RAM-okban helyezhetjük el (Névtáblák, OAM, másodlagos OAM).

\section{Kompakt hordozható méret}
\label{sec:Size}

A NES újra tervezésének egyik fő aspektusa a méret csökkentése. Az eredeti konzol 256 mm hosszú, 203,2 mm széles és 88,9 mm vastag volt. Ez a modern nyomtatott áramkörök tervezésével és a komponensek méretével sokkal kisebb területre csökkenthető. Ezzel kompakt hordozható kialakítást kölcsönözve a játékkonzolnak.

%todo fekete fehét kép
\begin{figure}[H]
	\centering
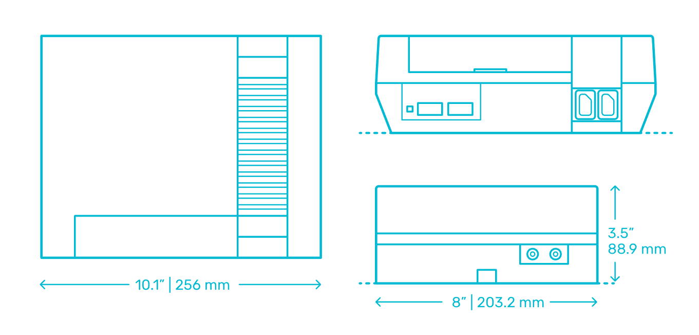
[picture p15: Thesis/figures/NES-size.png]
	
	\caption{A NES játékkonzol dimenziói \cite{NES_dimensions}}
	\label{fig:NES-size}
\end{figure}

A kompakt méret mellett szerettem volna megőrizni az eszköz nosztalgia faktorát is, ezért a kártyámon elhelyeztem két eredeti NES játék kontroller csatlakozót (kooperatív játékok miatt). Ez természetesen az eredeti hardver kontrollereivel kompatibilis.

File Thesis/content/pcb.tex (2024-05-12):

\chapter{FPGA NES kártya ismertetése}
\label{sec:fpga-nes-board-summary}

A NES hardverének újragondolásából \aref{fig:PCB-blockdiagram}. ábrán látható blokkdiagramot készítettem, ez a nyomtatott huzalozott kártyák tervezésének első lépése. Már itt érdemes feltüntetni a különböző áramköri elemek közti kommunikációs utakat (busz típusokat), illetve ezek irányát. A diagram alapján elkezdődhet a különböző komponensek keresése, ezt követően át kell gondolnunk ezek fogyasztását és feszültség szintjeit, majd ezekből az adatokból már megtervezhető a kártya tápellátása is (a mi esetünkben már kiegészítettem ezzel a blokkdiagramot). 

\begin{figure}[H]
	\centering
	
	\caption{NES kártya blokkdiagramja}
	\label{fig:PCB-blockdiagram}
\end{figure}

A komponensek közül az FPGA chip kiválasztása a legnehezebb. Ennek menete általában az, hogy megpróbáljuk felmérni az FPGA-val elvégzendő feladat hardveres méretét és ez alapján választunk megfelelő erőforrásokkal ellátott chip-et. A mi esetünkben az egyik legkomplexebb elem a 6502-es 8 bites processzor, amely méretét az OpenCores weboldalon \cite{OpenCore} található nyílt forráskódú hardvertervek alapján 1000 LUT-ra becsülhetjük. A NES működéséhez három fő komponens kell (CPU, APU, PPU), ezek méretét egyesével felülbecsülhetjük a legkomplexebb alkatrész méretével, így összesen 3000 LUT-ot kapunk. Ehhez még érdemes a VGA jel előállítását (TMDS jel kódolása), illetve az audió jel kezelését még hozzászámolni, erre is jó felső becslés az 1000 LUT. Végül még érdemes tartalékkal is számolni, ezért egy 5000-6000 LUT-al rendelkező FPGA chip valószínűleg elég nagy ahhoz, hogy a teljes projekt elférjen benne. Fontos kritérium még, hogy DCM-el és PLL-el rendelkezzen a chip az egyedi órajelek előállítása érdekében (például a 250 MHz a TMDS bitek kiadásához), ezen kívül még blokk RAM-ra is szükség lesz, legalább akkorára, mint a NES hardverének belső memóriája.  

%todo kell e ide a konzulens hivatkozása Szerencsére a konzulensem jóvoltából, szert tettem
A feladat megvalósításához egy Spartan-6-os Xilinx FPGA állt a rendelkezésemre, amely megfelel a fent említett összes elvárásnak. Ez a chip nagyban meggyorsította a nyáktervezés menetét is, mivel az egyetemi Spartan-6-os fejlesztő kártyák fő komponense is ez az FPGA volt \cite{spatan6}. Ezt a fejlesztő kártyát vettem alapul a NES kártyám fejlesztő portjának kialakítása, az SPI flash bekötése, illetve a tápvonalak kialakítása során is. 
	
A kártyán az alábbi komponensek találhatóak:

\begin{itemize}
	\item \emph{FPGA:} Xilinx XC6SLX9-2TQG144C típusú Spartan-6-os FPGA, amely lehetővé teszi az összetettebb logikák és
	a mikroprocesszoros rendszerek megvalósítását. Az eszköz főbb jellemzői:
		\begin{itemize}
			\item 5720 darab 6 bemenetű LUT és 11440 darab flip-flop
			\item 32 darab 18 kilobites blokk RAM
			\item 16 darab DSP48A1 blokk (elő összeadó, 18x18 bites előjeles szorzó és akkumulátor)
			\item 4 darab DCM (Digital Clock Manager) és 2 darab PLL (Phase Locked Loop) modul
		\end{itemize} 
	\item \emph{Memóriák a program és az adatok tárolására:}
		\begin{itemize}
			\item Egy 256kx16 bites (512 kB), 10 ns-os aszinkron SRAM (Cypress CY7C1041DV33-10ZSXI)
			\item Egy 32 Megabites SPI buszos soros flash memória (Atmel AT25DF321A), amely
			konfigurációs memóriaként is szolgál az FPGA számára
		\end{itemize}
	\item \emph{Egy MicroSD memóriakártya foglalat:}
		\begin{itemize}
			\item Teljes MicroSD kártya protokoll
			\item Egyszerű SPI protokoll
		\end{itemize}
	\item \emph{Beviteli eszközök:}
		\begin{itemize}
			\item Két eredeti 7 lábas NES (GamePAD) kontroller csatlakozók
			\item Reset és PROG gombok
		\end{itemize}	
	\item \emph{Képfeldolgozás:}
		\begin{itemize}
			\item HDMI csatlakozó 
			\item I2C szint illesztő (PCA9306DCUR típusú), megjelenítő EDID ROM-jának ki olvasásához 
		\end{itemize}
	\item \emph{Audio:}
		\begin{itemize}
			\item Digitális-analóg átalakító (DAC), CS4334-KSZ típusú  
			\item 100 mW-os TS486IST típusú erősítő (fülhallgatókhoz)
			\item CUI SJ1-3553NG 3,5mm Jack csatlakozó
		\end{itemize}
	\item \emph{Tápegységek:} MCP1612-ADJI/MS típusú szinkron buck konverterek
	\item \emph{Egy 50 MHz-es oszcillátor} 
	\item \emph{Csatlakozó a LOGSYS fejlesztői kábel számára} 
\end{itemize}
	
\section{Tápellátás}
	
	A tápellátás kialakítása a Logsys Spartan-6-os fejlesztői kártyáéhoz hasonló \cite{spatan6}. A NES kártya 5 V-os tápfeszültségről működik. Ezt a tápellátást vagy a fejlesztő kábelről kapja az eszköz, vagy egy külső 5 V-os forrásból. A külső egyenfeszültségű forrást Schottky dióda védi, illetve a kártyán elhelyeztem egy tápellátást jelző zöld LED-et is (PWR). 
	
	Az 5 V-os forrást két azonos típusú step down (buck) konverterrel 3,3 V-ra és 1,2 V-ra konvertálom. Alapvetően az FPGA működéséhez kell a két feszültségszint. A 3,3 V az I/O vonalakért, a DCM, a PLL és a konfigurációért felelős, míg az 1,2 V pedig az FPGA belső magjának kell. Ezt a két tápvonalat az FPGA dokumentációja alapján (a táp lábaihoz közel) elláttam a megfelelő mennyiségű csatoló (coupling) és hidegítő (bulk) kapacitásokkal a stabil működés érdekében. A 3,3 V-ot a kártyán található többi alkatrész is használja (SRAM, MicroSDkártya, kontrollerek, a fejlesztő kábel is megkapja, mint JTAG referencia feszültség, stb.). A kártya a HDMI csatlakozó, a DAC és az erősítő komponensek esetén a tápellátás 5 V-ját használja fel. A tápellátás kapcsolási rajzát \aref{sec:PSU}. függelékben láthatjuk. 
	 
\section{Órajel források}
	
	A NES kártyán a Logsys fejlesztő kártyához hasonlóan egy 50 MHz-es oszcillátort helyeztem el. Az FPGA, vagy a fejlesztő portról érkező CLK-tól kapja az órajelét, vagy az 50 MHz-es oszcillátorról. Ahhoz, hogy az FPGA használhassa ezeket az órajeleket, egy-egy órajel bemeneti lábára (GCLK) kellett ezeket bekötni. Az oszcillátor segéd áramkörét \aref{sec:OSC-JTAG}. függelékben láthatjuk. % és órajel források bekötését pedig \aref{tab:FPGA-OSCpin} táblázatban olvashatjuk.
	
%	\begin{table}[H]
%		\footnotesize
%		\centering
%		\begin{tabular}{|l|l|}
%			\hline
%			\rowcolor[HTML]{C0C0C0} 
%			\multicolumn{1}{|c|}{\cellcolor[HTML]{C0C0C0}{\color[HTML]{333333} \textbf{Órajel forrás}}} & \multicolumn{1}{c|}{\cellcolor[HTML]{C0C0C0}{\color[HTML]{333333} \textbf{FPGA láb}}} \\ \hline
%			50 MHz-es oszcillátor                                                                       & P85                                                                                   \\ \hline
%			Fejlesztői port CLK vonala                                                                  & P95                                                                                   \\ \hline
%		\end{tabular}
%		\caption{FPGA órajel forrásainak bekötése}
%		\label{tab:FPGA-OSCpin}
%	\end{table}
	
\section{Memória - SRAM}
	
	A választott aszinkron SRAM mérete 256kx16 bit (512 kilobájt). Ez a méret megfelel \aref{sec:Game-store}. fejezetben tárgyalt játék méreteknek (csak egy NES játék nem fog beleférni ebbe a RAM-ba). A választott memória előnye, hogy 10 ns elérési idejű aszinkron, statikus RAM, egyszerű kezeléssel. Ez azért jelent előnyt a konzol hardveres emulálása szempontjából, mert nem fogja ennek működését befolyásolni a memória elérési idő (a későbbiekben az elérést igazíthatjuk az általunk választott időzítéshez). DRAM esetén sokkal több időzítési paraméterrel kell számolni, ez jóval megnehezítené egy időzítés kritikus hardver létrehozását.
	
	Az SRAM 18 bites címmel rendelkezik, ezzel az adataink 2 bájtosával címezhetőek (összesen 256 kilobájt cím). A RAM-ból kiolvasott, illetve beírandó adatokat pedig a 16 bites adatvonalak segítségével érhetjük el. Az SRAM vezérlésétől függően kiolvasható vagy írható egyszerre mind a 16 bit, de van bájtos elérési mód is.
	
	Az SRAM szabványos vezérlési felülettel rendelkezik. A következő vezérlőjelek segítségével tudjuk irányítani (ezek mindegyike negált logikájú): chip engedélyezés CSn, írás engedélyezése WEn, olvasás engedélyezés OEn, alsó bájt engedélyezés LBn, végül pedig a felső bájt engedélyezés UBn. A memória olvasási és írási idő diagramjait \acite{sram} adatlapban olvashatjuk, a kiegészítő áramkörét pedig \aref{sec:SRAM-SPI-Flash}. függelékben láthatjuk.     
	
%	\begin{table}[H]
%		\footnotesize
%		\centering
%		\begin{tabular}{|lccccccccc|}
%			\hline
%			\rowcolor[HTML]{C0C0C0} 
%			\multicolumn{10}{|l|}{\cellcolor[HTML]{C0C0C0}\textbf{Címbusz}}                                                                                                                                                                                                                                                                                                                                                                                                                                                                                                                                                                                                                                      \\ \hline
%			\rowcolor[HTML]{EFEFEF} 
%			\multicolumn{1}{|l|}{\cellcolor[HTML]{EFEFEF}SRAM}                            & \multicolumn{1}{c|}{\cellcolor[HTML]{EFEFEF}A0}                         & \multicolumn{1}{c|}{\cellcolor[HTML]{EFEFEF}A1}                         & \multicolumn{1}{c|}{\cellcolor[HTML]{EFEFEF}A2}                         & \multicolumn{1}{c|}{\cellcolor[HTML]{EFEFEF}A3}                         & \multicolumn{1}{c|}{\cellcolor[HTML]{EFEFEF}A4}                         & \multicolumn{1}{c|}{\cellcolor[HTML]{EFEFEF}A5}                         & \multicolumn{1}{c|}{\cellcolor[HTML]{EFEFEF}A6}                         & \multicolumn{1}{c|}{\cellcolor[HTML]{EFEFEF}A7}                         & A8   \\ \hline
%			\rowcolor[HTML]{EFEFEF} 
%			\multicolumn{1}{|l|}{\cellcolor[HTML]{EFEFEF}{\color[HTML]{333333} FPGA láb}} & \multicolumn{1}{c|}{\cellcolor[HTML]{EFEFEF}{\color[HTML]{333333} P47}} & \multicolumn{1}{c|}{\cellcolor[HTML]{EFEFEF}{\color[HTML]{333333} P46}} & \multicolumn{1}{c|}{\cellcolor[HTML]{EFEFEF}{\color[HTML]{333333} P45}} & \multicolumn{1}{c|}{\cellcolor[HTML]{EFEFEF}{\color[HTML]{333333} P44}} & \multicolumn{1}{c|}{\cellcolor[HTML]{EFEFEF}{\color[HTML]{333333} P43}} & \multicolumn{1}{c|}{\cellcolor[HTML]{EFEFEF}{\color[HTML]{333333} P34}} & \multicolumn{1}{c|}{\cellcolor[HTML]{EFEFEF}{\color[HTML]{333333} P33}} & \multicolumn{1}{c|}{\cellcolor[HTML]{EFEFEF}{\color[HTML]{333333} P32}} & P30  \\ \hline
%			\multicolumn{1}{|l|}{SRAM}                                                    & \multicolumn{1}{c|}{A9}                                                 & \multicolumn{1}{c|}{A10}                                                & \multicolumn{1}{c|}{A11}                                                & \multicolumn{1}{c|}{A12}                                                & \multicolumn{1}{c|}{A13}                                                & \multicolumn{1}{c|}{A14}                                                & \multicolumn{1}{c|}{A15}                                                & \multicolumn{1}{c|}{A16}                                                & A17  \\ \hline
%			\multicolumn{1}{|l|}{FPGA láb}                                                & \multicolumn{1}{c|}{P29}                                                & \multicolumn{1}{c|}{P7}                                                 & \multicolumn{1}{c|}{P6}                                                 & \multicolumn{1}{c|}{P5}                                                 & \multicolumn{1}{c|}{P2}                                                 & \multicolumn{1}{c|}{P1}                                                 & \multicolumn{1}{c|}{P139}                                               & \multicolumn{1}{c|}{P138}                                               & P137 \\ \hline
%		\end{tabular}
%		\caption{SRAM memória címbusz bekötése}
%		\label{tab:FPGA-MEM-SRAMpin}
%	\end{table}
%		
%	\begin{table}[H]
%		\footnotesize
%		\centering
%		\begin{tabular}{|lcccccccc|}
%			\hline
%			\rowcolor[HTML]{C0C0C0} 
%			\multicolumn{9}{|l|}{\cellcolor[HTML]{C0C0C0}\textbf{Adatbusz}}                                                                                                                                                                                                                                                                                                                                                                                                                                                                                                                                                                                  \\ \hline
%			\rowcolor[HTML]{EFEFEF} 
%			\multicolumn{1}{|l|}{\cellcolor[HTML]{EFEFEF}SRAM}                            & \multicolumn{1}{c|}{\cellcolor[HTML]{EFEFEF}D0}                         & \multicolumn{1}{c|}{\cellcolor[HTML]{EFEFEF}D1}                         & \multicolumn{1}{c|}{\cellcolor[HTML]{EFEFEF}D2}                         & \multicolumn{1}{c|}{\cellcolor[HTML]{EFEFEF}D3}                         & \multicolumn{1}{c|}{\cellcolor[HTML]{EFEFEF}D4}                         & \multicolumn{1}{c|}{\cellcolor[HTML]{EFEFEF}D5}                         & \multicolumn{1}{c|}{\cellcolor[HTML]{EFEFEF}D6}                         & D7                         \\ \hline
%			\rowcolor[HTML]{EFEFEF} 
%			\multicolumn{1}{|l|}{\cellcolor[HTML]{EFEFEF}{\color[HTML]{333333} FPGA láb}} & \multicolumn{1}{c|}{\cellcolor[HTML]{EFEFEF}{\color[HTML]{333333} P40}} & \multicolumn{1}{c|}{\cellcolor[HTML]{EFEFEF}{\color[HTML]{333333} P17}} & \multicolumn{1}{c|}{\cellcolor[HTML]{EFEFEF}{\color[HTML]{333333} P21}} & \multicolumn{1}{c|}{\cellcolor[HTML]{EFEFEF}{\color[HTML]{333333} P22}} & \multicolumn{1}{c|}{\cellcolor[HTML]{EFEFEF}{\color[HTML]{333333} P23}} & \multicolumn{1}{c|}{\cellcolor[HTML]{EFEFEF}{\color[HTML]{333333} P24}} & \multicolumn{1}{c|}{\cellcolor[HTML]{EFEFEF}{\color[HTML]{333333} P26}} & {\color[HTML]{333333} P27} \\ \hline
%			\multicolumn{1}{|l|}{SRAM}                                                    & \multicolumn{1}{c|}{D8}                                                 & \multicolumn{1}{c|}{D9}                                                 & \multicolumn{1}{c|}{D10}                                                & \multicolumn{1}{c|}{D11}                                                & \multicolumn{1}{c|}{D12}                                                & \multicolumn{1}{c|}{D13}                                                & \multicolumn{1}{c|}{D14}                                                & D15                        \\ \hline
%			\multicolumn{1}{|l|}{FPGA láb}                                                & \multicolumn{1}{c|}{P8}                                                 & \multicolumn{1}{c|}{P9}                                                 & \multicolumn{1}{c|}{P10}                                                & \multicolumn{1}{c|}{P11}                                                & \multicolumn{1}{c|}{P12}                                                & \multicolumn{1}{c|}{P14}                                                & \multicolumn{1}{c|}{P15}                                                & P16                        \\ \hline
%		\end{tabular}
%		\caption{SRAM memória adatbusz bekötése}
%		\label{tab:FPGA-DATA-SRAMpin}
%	\end{table}
%
%	\begin{table}[H]
%		\footnotesize
%		\centering
%		\begin{tabular}{|llllcc|}
%			\hline
%			\multicolumn{6}{|l|}{\cellcolor[HTML]{C0C0C0}\textbf{Vezérlő jelek}}                                                                                \\ \hline
%			\multicolumn{1}{|l|}{SRAM}     & \multicolumn{1}{l|}{CSn} & \multicolumn{1}{l|}{WEn} & \multicolumn{1}{l|}{OEn}  & \multicolumn{1}{c|}{LBn}  & UBn  \\ \hline
%			\multicolumn{1}{|l|}{FPGA láb} & \multicolumn{1}{l|}{P41} & \multicolumn{1}{l|}{P35} & \multicolumn{1}{l|}{P140} & \multicolumn{1}{c|}{P142} & P141 \\ \hline
%		\end{tabular}
%		\caption{SRAM memória vezérlő jelek bekötése}
%		\label{tab:FPGA-CONTROL-SRAMpin}
%	\end{table} 
	
\section{Digital Analog Converter és erősítő}
	
	A NES kártya egyetlen analóg alkatrészekre támaszkodó része a DAC-ot követő erősítő áramkör, ennek részletes megértéséhez tekintsük meg \aref{fig:DAC-AMP-JACK}. ábrát, amely \aref{sec:DAC-controllers}. függelékből lett kiemelve.
	
	A DAC komponenst egy 100 MHz-en 600 $\Omega$-os Ferrite Bead-el védem az esetleges 5 V-os tápvonalról beszűrődő zajokkal szemben. Ide szűrési okokból tantál és kerámia kondenzátorokat is helyeztem. Az alkatrész az FPGA által előállított mono digitális "hang" jelet alakítja át és adja ki mind a két kimenetén. Ezek az analóg jelek fognak az erősítést követően, a Jack csatlakozó bal és jobb fülhöz menő lábára csatlakozni. 
	
	A DAC két kimenetét, egy-egy 3,3 uF-os csatoló kondenzátorral választom el az analóg résztől. Az áramkörben található C38, C39-es kondenzátorok és R27, R28-as ellenállások egy aluláteresztő szűrőt valósítanak meg. A kondenzátorok értékét, pedig a következő képlet alapján határoztam meg (az ellenállások értéke kötött volt az erősítő miatt):
	
	\begin{align}	
		C = \frac{R + 560 \Omega}{4} *\pi * Fs * (R * 560 \Omega)
	\end{align} 
	
	Itt $Fs$ az általunk választott audió jel frekvenciája, az 560 $\Omega$ pedig a soros ellenállás értéke. Ezek alapján a két kondenzátorom értéke 3,3 nF vagy 2,7 nF lehet, mivel így 48 kHz-hez közeli értéket kapunk a frekvenciára. Az összes kerámia kondenzátornak, amely az analóg áramkör része NP0 (vagy C0G) dielektrikummal kell rendelkeznie, mivel ezeknek nincs piezoelektromos tulajdonságuk.   
	
	\begin{figure}[H]
		\centering
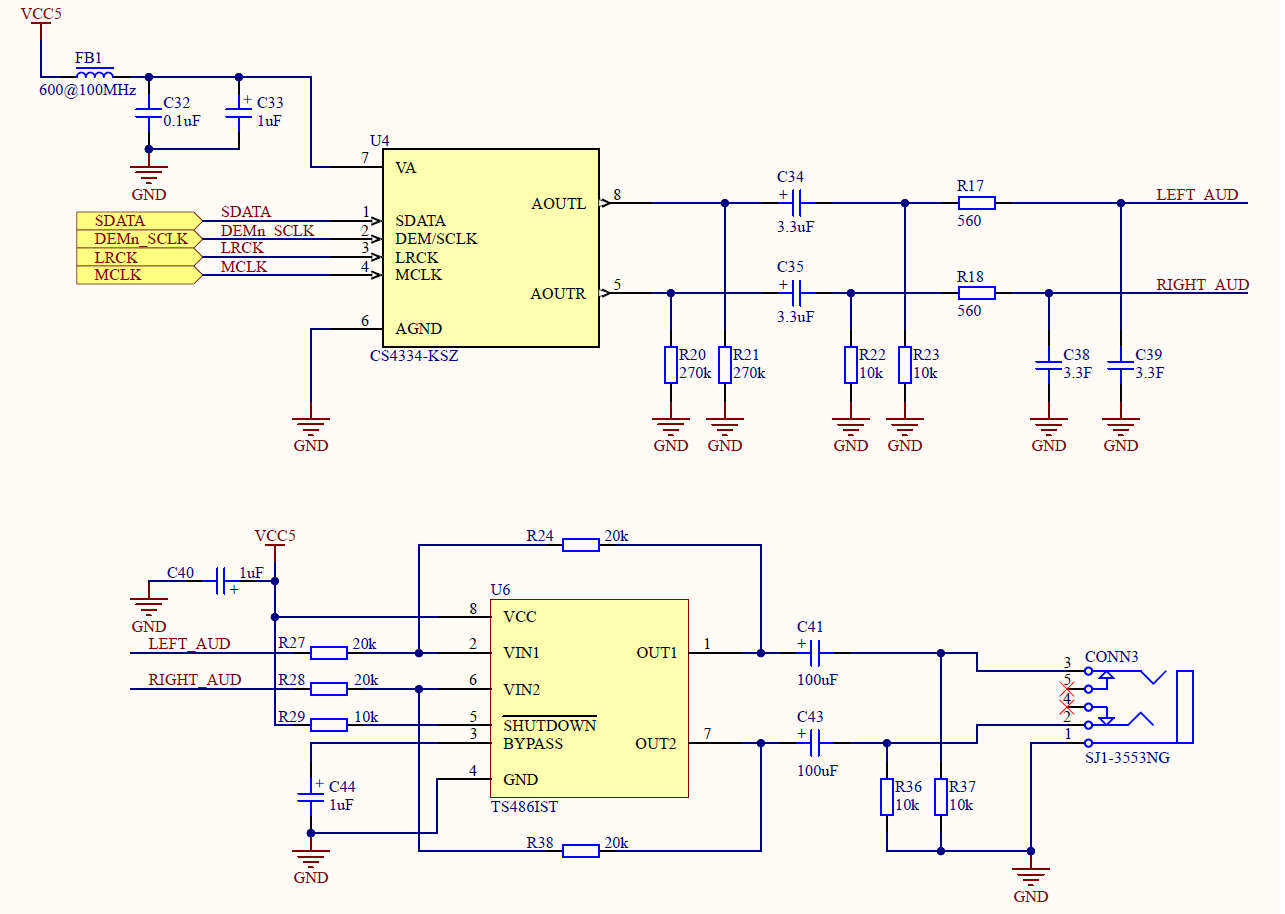
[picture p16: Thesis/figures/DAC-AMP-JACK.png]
		
		\caption{NES audió jelért felelős áramkörök}
		\label{fig:DAC-AMP-JACK}
	\end{figure}
	
	Az erősítő komponensnek egy fázisfordító erősítőt választottam, amely erősítése az R27 és R24, illetve az R28 és R38 ellenállásokkal módosítható a következő képletek alapján:
	
	\begin{align}	
		Gain_{LINEAR} = -\frac{RFEED}{RIN}
	\end{align} 
	
	\begin{align}	
		Gain_{dB} = 20 * lg(\frac{RFEED}{RIN})
	\end{align}
 
	Az áramkörben jelenleg nem állítottam be erősítést, az RFEED és RIN ellenállások értékét 20 k$\Omega$-nak határoztam meg. Ez természetesen a hardveres tesztelés során cserélhető és állítható.	
	
\section{HDMI és I2C szint illesztő}
	\label{sec:HMI-I2C}
	
	A NES nyomtatott huzalozott kártyáján elhelyeztem egy HDMI csatlakozót és a körülötte elhelyezkedő áramkör segítségével felkészítettem TMDS jelek kiadására. A teljes áramkör kapcsolási rajzát \aref{sec:HDMI-MicroSDcard}. függelékben láthatjuk.
	
	A jövőbeli fejlesztések miatt elhelyeztem a nyákon még egy I2C jelszint illesztőt is, hogy ennek segítségével a csatlakoztatott eszköz EDID ROM-ját ki tudjam olvasni. Ebből megállapítható, hogy képes-e audió adatok vételére a TV vagy monitor, így a kártya támogatja ezen eszközök beépített hangszóróit is. 
	
	Az alábbi ábrákon láthatjuk egy HDMI anya aljzat pin és láb kiosztását:   
	
	\begin{figure}[H]
	\begin{minipage}[]{\textwidth}
		\begin{minipage}[b]{0.39\textwidth}
			\centering
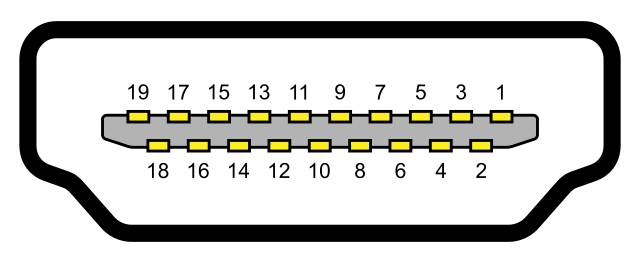
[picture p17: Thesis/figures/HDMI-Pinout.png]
			
			\captionof{figure}{aljzat anya \cite{HDMI}}
			\label{fig:HDMI-pinout}
		\end{minipage}
		\hfill
		\begin{minipage}[b]{0.59\textwidth}
			\footnotesize
			\centering
			\begin{tabular}{|l|c|l|c|}
				\hline
				\rowcolor[HTML]{C0C0C0} 
				\textbf{Funkció}  & \multicolumn{1}{l|}{\cellcolor[HTML]{C0C0C0}{\color[HTML]{333333} \textbf{Láb}}} & \textbf{Funkció}  & \multicolumn{1}{l|}{\cellcolor[HTML]{C0C0C0}{\color[HTML]{333333} \textbf{Láb}}} \\ \hline
				TMDS Data2+       & 1                                                                                & TMDS Clock Shield & 11                                                                               \\ \hline
				TMDS Data2 Shield & 2                                                                                & TMDS Clock-       & 12                                                                               \\ \hline
				TMDS Data-        & 3                                                                                & CEC               & 13                                                                               \\ \hline
				TMDS Data1+       & 4                                                                                & Reserved          & 14                                                                               \\ \hline
				TMDS Data1 Shield & 5                                                                                & SCL               & 15                                                                               \\ \hline
				TMDS Data1-       & 6                                                                                & SDA               & 16                                                                               \\ \hline
				TMDS Data0+       & 7                                                                                & DDC/CEC Ground    & 17                                                                               \\ \hline
				TMDS Data0 Shield & 8                                                                                & +5 V Power        & 18                                                                               \\ \hline
				TMDS Data0-       & 9                                                                                & Hot Plug Detected & 19                                                                               \\ \hline
				TMDS Clock+       & 10                                                                               &                   & \multicolumn{1}{l|}{}                                                            \\ \hline
			\end{tabular}
			\captionof{table}{HDMI lábkiosztás}
			\label{tab:HDMI-pinout}
		\end{minipage}
	\end{minipage}
	\end{figure} 
	
	Mivel az FPGA nem minden I/O láb pára képes differenciális jelek küldésére, ezért figyelni kell, hogy a csatlakozót az FPGA melyik oldalához közel helyezem el. A HDMI szabvány a differenciális vonalakra 100 $\Omega$-os differenciális impedanciát ír elő (15 \%-os toleranciával), ezért érdemes ezeket a vezetékeket minél rövidebben huzalozni (FPGA bekötési oldalhoz közel). 
	
	Az alkatrészeim védelmére a HDMI 5 V-os tápellátását egy 100 mA-es biztosítékon (poli fuse) vezettem keresztül, ez túláram esetén véd. A csatlakozó fém burkolatát egy 1 M$\Omega$-os ellenállással és egy 1 nF-os (1 kV-os) kapacitással földeltem, ez HDMI kimenetek esetén ideális. 
	
\section{A kártya bemenetei}
	
	A NES nyomtatott huzalozott kártyáját az eredeti játékkonzol kontroller csatlakozóival láttam el. Az eredeti kontroller a NES 5 V-járól működik, viszont a benne található párhuzamos-soros átalakító (shiftregiszter) az adatlapja alapján 3,3 V-ról is működik. Ez azért fontos, mert így nem kell extra jelszint illesztő IC a kártyára, működtethetem az adat fogadást és az órajel küldést az FPGA I/O lábairól (3,3 V).
	
	Ennek a kontrollernek egyedi hét lábas anya csatlakozója van, amit \aref{fig:7PIN-Port}. ábrán láthatunk.   
	
	\begin{figure}[H]
		\centering
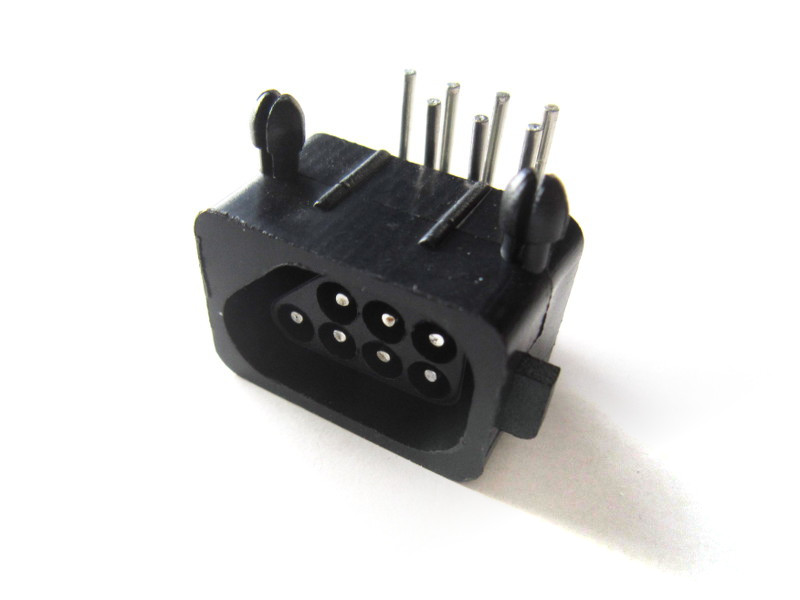
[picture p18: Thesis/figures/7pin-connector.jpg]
		 %110
		\caption{NES kontroller csatlakozó \cite{NES_controller}}
		\label{fig:7PIN-Port}
	\end{figure}
	
	Ebből a hét lábból kettőnek csak rögzítési szerepe van, kettő a tápellátásért felelős és a maradék három lábon keresztül történik a kontrollerben található regiszter olvasása, vezérlése és a működési órajel küldése. A kártyára ebből a csatlakozóból kettőt helyeztem el a kooperatív játékok végett. A kontroller portok kapcsolási rajzát \aref{sec:DAC-controllers}. függelékben láthatjuk.
	
	A nyákon négy gomb is helyet kapott: az első az FPGA és ezáltal a NES reset gombja (RST), a második az FPGA újrakonfigurálását elindító nyomógomb (PROG), a harmadik és negyedik pedig a hangerő növelő és csökkentő gombok. Az gombok pergés mentesítéséért az FPGA felelős. Ezek mindegyikét \aref{sec:OSC-JTAG}. függelékben láthatjuk. 
	
\section{MicroSD kártya}
	
	A MicroSD kártya csatlakozót teljes interfésszel tudtam implementálni, mivel az FPGA-nak még sok szabad I/O lába maradt. Ez azt jelenti, hogy teljes SD kártya protokollt is megtudok valósítani a NES fejlesztő kártyán az egyszerűbb soros SPI kommunikáció mellett. A MicroSD kártya segéd áramkörét \aref{sec:HDMI-MicroSDcard}. függelék kapcsolási rajzán láthatjuk. 
	
	Itt érdemes az áramkör ki-és bekapcsolásáért felelős P-MOSFET-es áramkört megnézni. Ez azért szükséges, mert a fent említett két protokoll közötti váltáshoz áramtalanítanunk kell az SD kártyát. A tápellátás elvétele mellett a felhúzó ellenállások tápellátását is elvesszük kikapcsolás során. Egyedül a CD kártya detektáló lábtól nem vesszük el, mivel ez csak azt jelzi, hogy van-e SD kártya a csatlakozóban (nem része a fent említett kommunikációs protokolloknak). Ezt a be- és kikapcsolási eseményt az FPGA egy I/O lábának segítségével vezéreljük.
	
	Az esetleges túllövések csökkentése érdekében elhelyeztem az SD kártya CLK lábára egy 33 $\Omega$-os soros ellenállást, ezt a PCB layout tervezése során a lehető legközelebb helyeztem el az FPGA-hoz.  
	
\section{FPGA konfigurációs módok}
	
	A NES kártyának is a LOGSYS Spartan-6 FPGA kártyához hasonló módon \cite{spatan6} két konfigurációs módja van. Az FPGA-t felprogramozhatjuk a fejlesztői porton található JTAG interfész segítségével, illetve felkonfigurálhatja saját magát a kártyán található soros flash memóriából is. A konfigurációs módok között egy rövidzár segítségével (jumper) válthatunk a LOGSYS-es kártyához hasonlóan. Ennek működését \aref{tab:FPGA-config}. táblázatban olvashatjuk, illetve \aref{sec:FPGA-BANKS}. függelékben láthatjuk.       
	
	\begin{table}[H]
		\footnotesize
		\centering
		\begin{tabular}{|c|c|l|}
			\hline
			\rowcolor[HTML]{C0C0C0} 
			\textbf{\begin{tabular}[c]{@{}c@{}}Jumper\\ állása\end{tabular}} & {\color[HTML]{333333} \textbf{\begin{tabular}[c]{@{}c@{}}Konfigurációs \\ mód\end{tabular}}} & \multicolumn{1}{c|}{\cellcolor[HTML]{C0C0C0}\textbf{Leírás}}                                                                                                                          \\ \hline
			\rowcolor[HTML]{FFFFFF} 
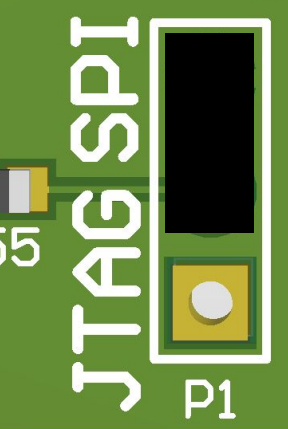
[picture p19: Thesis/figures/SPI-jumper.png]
			\raisebox{-.5\height}{}                                                                & JTAG                                                                                         & Az FPGA-t a JTAG interfészen keresztül kell felkonfigurálni.                                                                                                                           \\ \hline
			\rowcolor[HTML]{FFFFFF} 
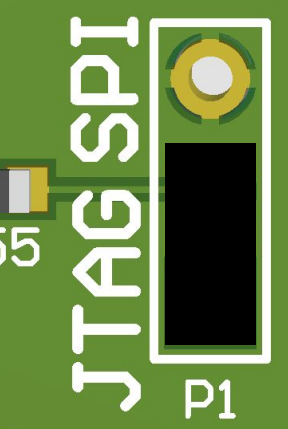
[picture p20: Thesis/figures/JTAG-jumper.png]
			\raisebox{-.5\height}{}                                                                & SPI                                                                                          & \begin{tabular}[c]{@{}l@{}}Az FPGA az SPI buszos soros flash memóriából konfigurálja \\ fel magát a tápfeszültség bekapcsolása vagy a PROG gomb \\ megnyomását követően.\end{tabular} \\ \hline
		\end{tabular}
		\caption{FPGA konfigurációs mód állítása}
		\label{tab:FPGA-config}
	\end{table}
	
\section{Soros flash memória}
	
	A NES kártyán egy Atmel AT25DF321A típusú, 32 Megabites, SPI busszal rendelkező soros flash memóriát helyeztem el. Ez a komponens az FPGA számára konfigurációs memóriaként szolgál (tehát a NES hardverének binárisát fogja tartalmazni). Ennek a komponensnek az elhelyezése, bekötése és ezáltal a működése is megegyezik a Logsys Spartan-6-os fejlesztői kártyán található flash-el \cite{spatan6}. A soros flash bekötését \aref{sec:SRAM-SPI-Flash}. függelékben láthatjuk.
	
	%TODO fix jumper heights if you have time
\section{LOGSYS fejlesztői port}
\label{sec:logsysport}
	
	A fejlesztői port kialakítása teljes mértékben megegyezik a Logsys fejlesztőkártyán található port-al, ennek köszönhetően az FPGA felprogramozása történhet a MIT tanszéken tervezett egyedi fejlesztőkábellel. Ennek részletes bemutatása \acite{spatan6}-os dokumentáció része. A fejlesztői port kialakítása \aref{sec:OSC-JTAG}. függelékben látható. Az FPGA sikeres felkonfigurálását egy zöld LED-el jelzem (DONE). %A fejlesztői port a következő elemekből áll:
	
%	\begin{enumerate}
%		\item JTAG interfész (vörös)
%		\item Soros SPI kommunikációs interfész (zöld)
%		\item 5 V-os egyenfeszültségű táp forrás (szürke)
%	\end{enumerate}
%	
%	\begin{figure}[H]
%		\begin{minipage}[]{\textwidth}
%			\begin{minipage}[b]{0.49\textwidth}
%				\centering
%				\includegraphics[width=50mm, keepaspectratio]{figures/DEV-port}
%				\captionof{figure}{Fejlesztői port kiosztása}
%				\label{fig:DEV-port}
%			\end{minipage}
%			\hfill
%			\begin{minipage}[b]{0.49\textwidth}
%				\footnotesize
%				\centering
%				\begin{tabular}{|l|l|l}
%					\cline{1-2}
%					\rowcolor[HTML]{C0C0C0} 
%					\multicolumn{1}{|c|}{\cellcolor[HTML]{C0C0C0}\textbf{jel}} & \multicolumn{1}{c|}{\cellcolor[HTML]{C0C0C0}{\color[HTML]{333333} \textbf{Irány}}} & \multicolumn{1}{c}{\cellcolor[HTML]{C0C0C0}\textbf{FPGA láb}} \\ \hline
%					\rowcolor[HTML]{FFFFFF} 
%					MOSI                                                       & bemenet                                                                            & \multicolumn{1}{l|}{\cellcolor[HTML]{FFFFFF}P104}             \\ \hline
%					\rowcolor[HTML]{FFFFFF} 
%					MISO                                                       & kimenet                                                                            & \multicolumn{1}{l|}{\cellcolor[HTML]{FFFFFF}P144}             \\ \hline
%					CLK                                                        & bemenet                                                                            & \multicolumn{1}{l|}{P95}                                      \\ \hline
%					RST                                                        & bemenet                                                                            & \multicolumn{1}{l|}{P94}                                      \\ \hline
%				\end{tabular}
%				\captionof{table}{Fejlesztői port bekötése}
%				\label{tab:DEV-pinout}
%			\end{minipage}
%		\end{minipage}
%	\end{figure} 		

\section{Nyomtatott áramköri terv}
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

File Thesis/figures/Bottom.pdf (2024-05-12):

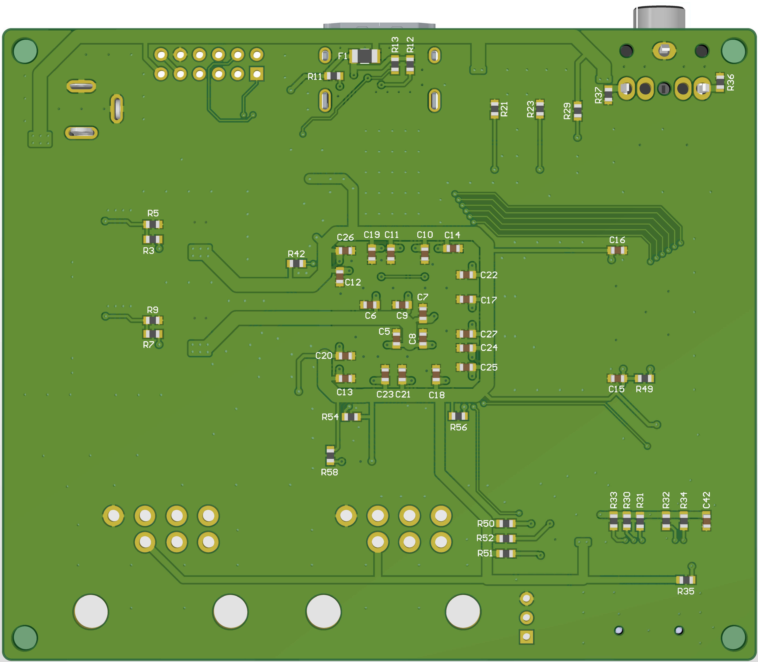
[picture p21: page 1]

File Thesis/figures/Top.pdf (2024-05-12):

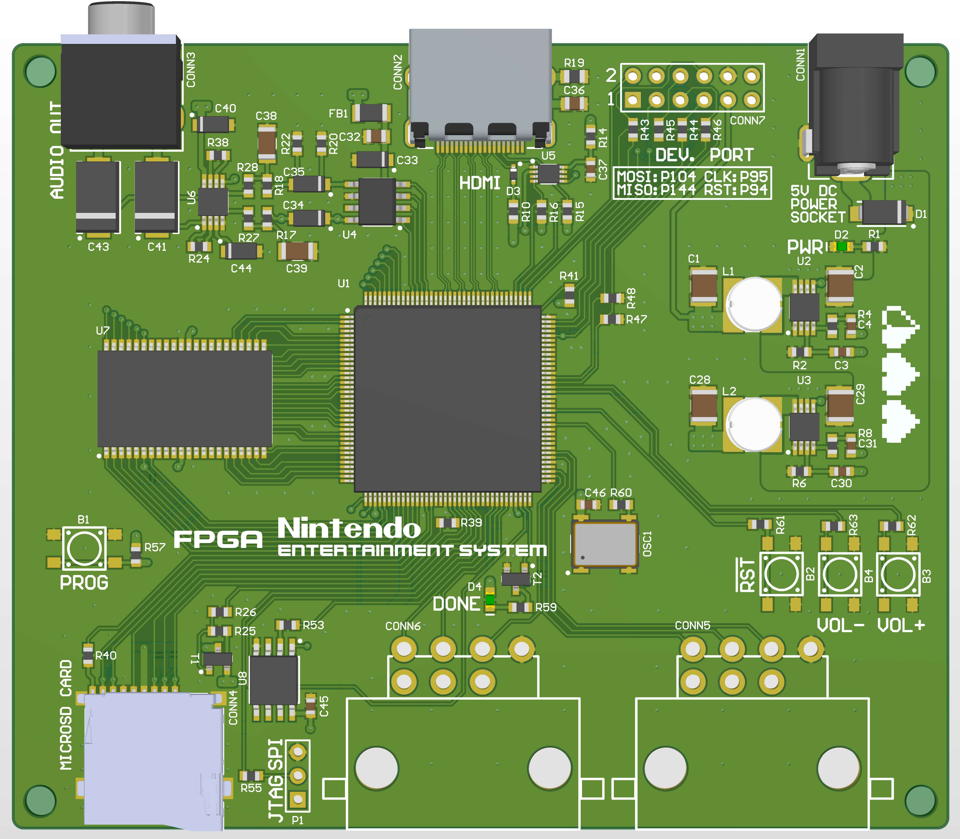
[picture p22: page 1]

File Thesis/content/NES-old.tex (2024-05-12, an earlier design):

\chapter{Nintendo Entertainment System ismertetése}

A Nintendo Entertainment System (NES) egy otthoni videojátékkonzol, amelyet a Nintendo 1983-ban Japánban (Family Computer, röviden FamiCom néven) és 1985-ben Észak-Amerikában, Európában és Ausztráliában adott ki. Ez minden idők egyik legikonikusabb és legnagyobb hatású videojátékkonzolja.

A NES döntő szerepet játszott a videojáték-ipar újjáélesztésében az 1983-as észak-amerikai videojáték-válság után. Számos klasszikus és kedvelt játékot mutatott be, amelyeket a játékosok még ma is nagyra tartanak. A konzol sikere a rá megjelent számos játéknak, a felhasználóbarát kialakításnak és az innovatív marketingstratégiáknak volt köszönhető.
%TODO kép a konzolról
\begin{figure}[H]
	\centering
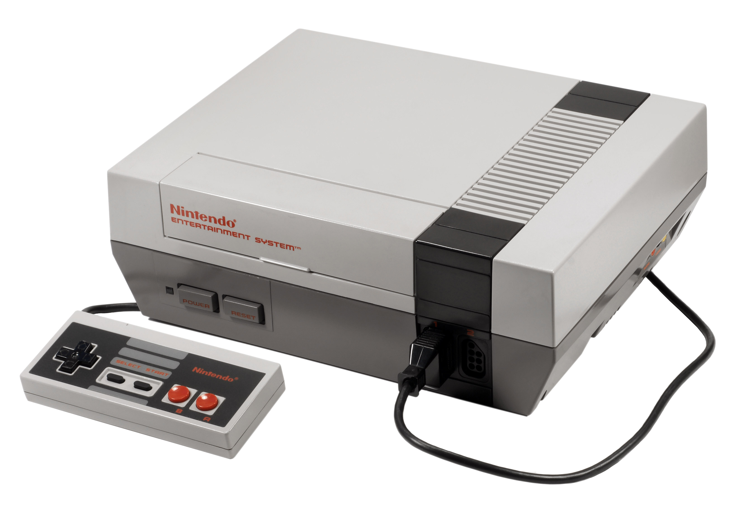
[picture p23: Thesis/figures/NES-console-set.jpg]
	
	\caption{Nintendo Entertainment System \cite{NES_picture}}
	\label{fig:NES-Consol}
\end{figure}

Az otthoni konzol 8 bites processzorral rendelkezett és a játékok tárolására elsősorban kazettákat használt. Jellegzetes, téglalap alakú kialakítása volt a játékkazetták behelyezésére szolgáló elülső betöltő mechanizmussal. A konzolhoz egy pár kontroller is tartozott és bevezette a ma már ikonikus NES kontroller kialakítását, amely irány gombokkal, start és választó (select) gombokkal, valamint az A és B gombokkal rendelkezett.

A konzolra megjelent legnépszerűbb és legnagyobb hatású játékok közé tartozik a Super Mario Bros., a The Legend of Zelda, a Metroid, a Mega Man, a Castlevania és még sok más program. Ezek a játékok megalapoztak számos sikeres franchise-t, amelyek ma is virágoznak.
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

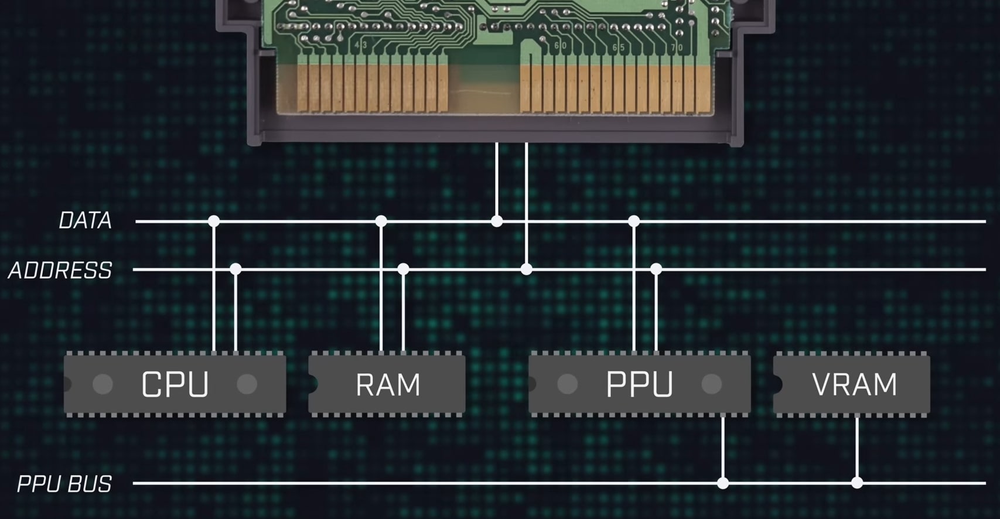
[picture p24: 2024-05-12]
Thesis/figures/NES-databuses.jpg

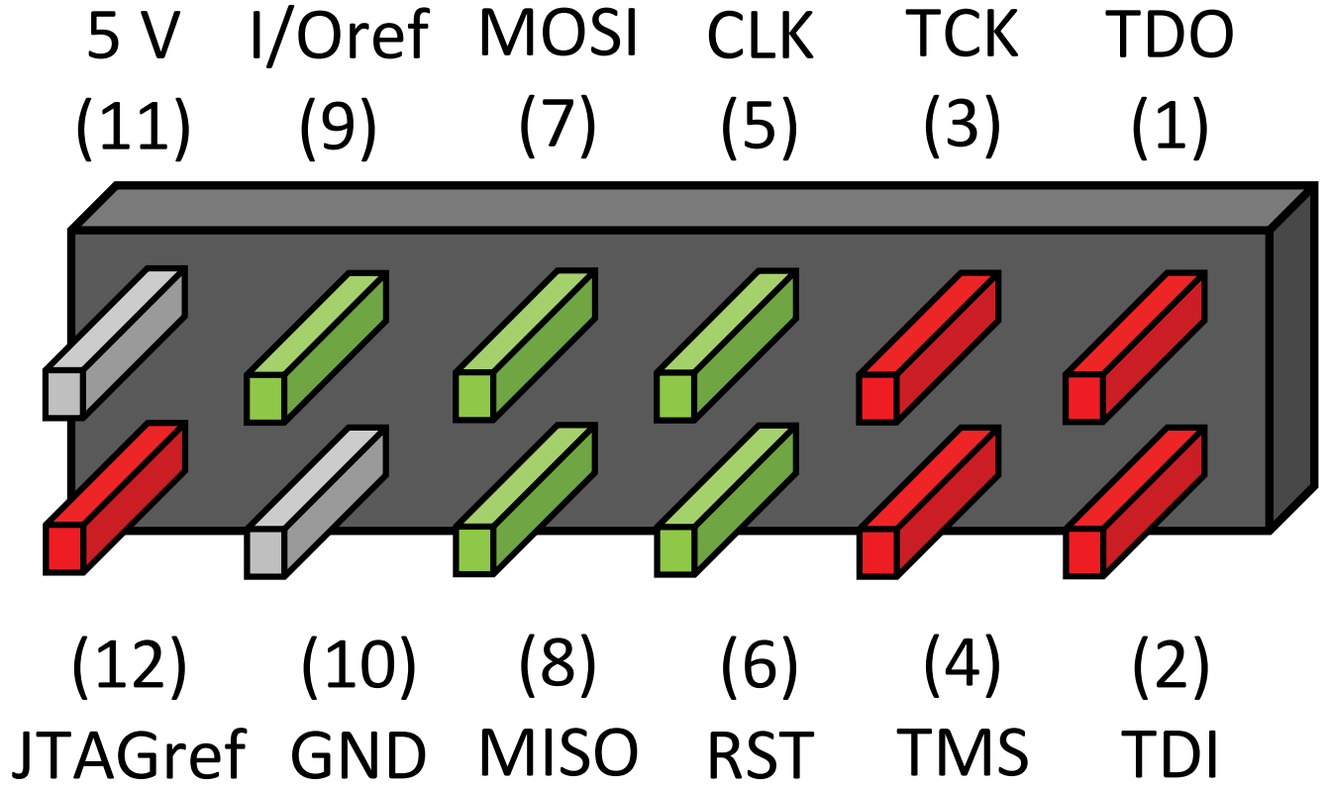
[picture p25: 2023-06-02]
Thesis/figures/DEV-port.png

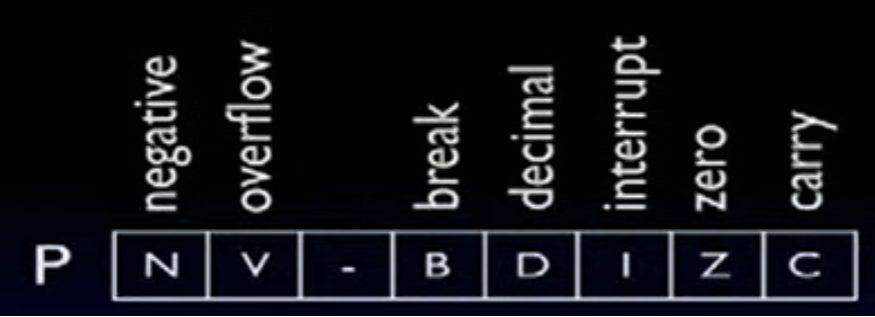
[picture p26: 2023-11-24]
Thesis/figures/6502-P-reg.png

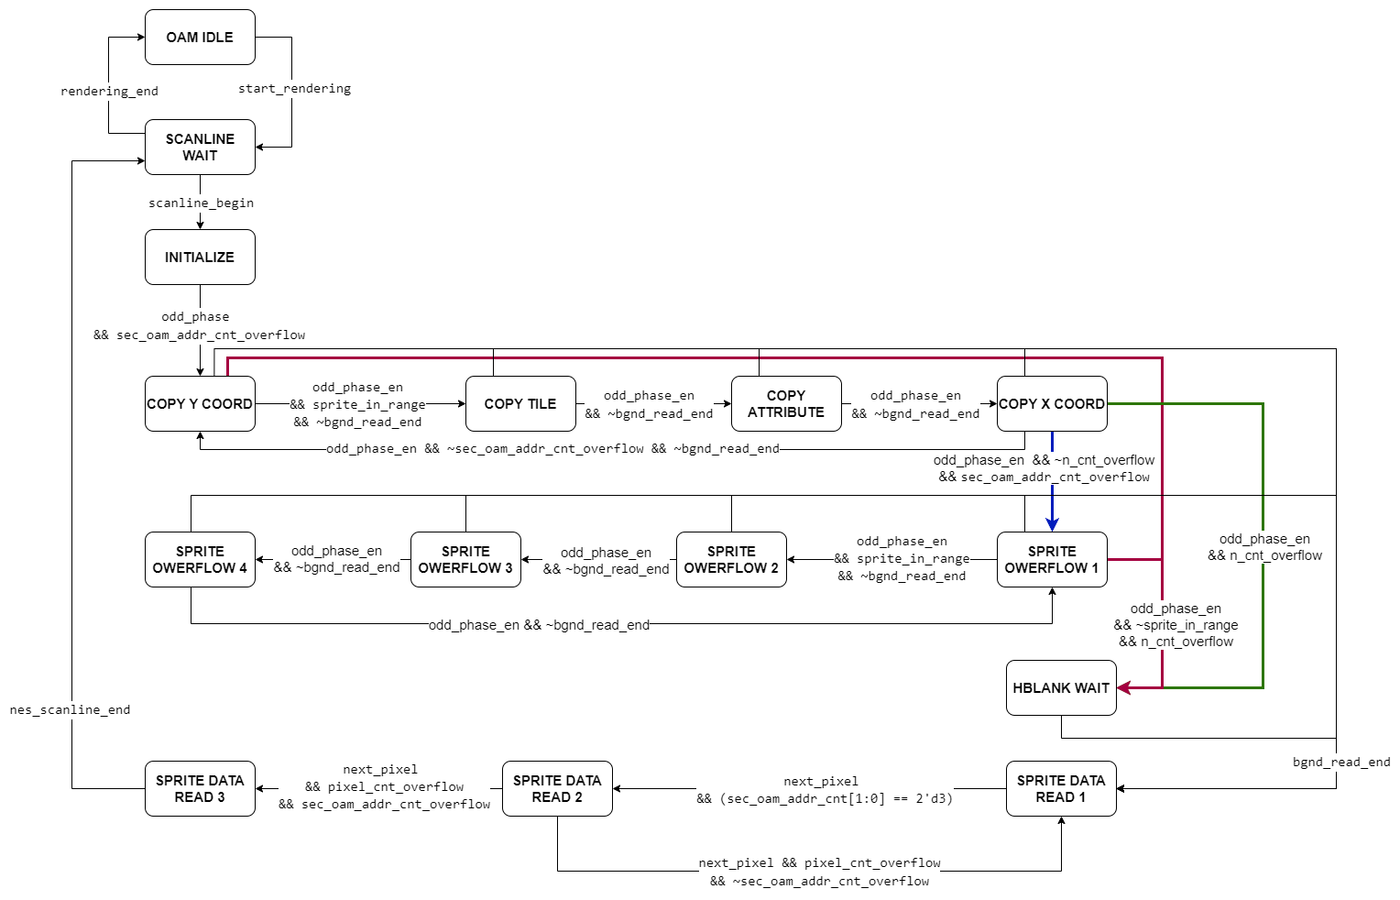
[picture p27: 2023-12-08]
Thesis/figures/sprite-rendering-FSM.png

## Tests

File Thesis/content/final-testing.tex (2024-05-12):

\chapter{Az FPGA NES tesztelése}

Az FPGA-s projektek tesztelésének általában három nagy fázisa van. Az első a fejlesztői környezet szimulációs rendszerében futtatott tesztek. A második ezt követően az éles hardverrel futtatott tesztek. A teszteket végeztével az eredmények kiértékelése a harmadik fázis. Ezeket a teszt folyamatokat fogom bemutatni a diplomaterv projektemen, ebben a fejezetben.

\section{Rendszer szimulációk}

A legtöbb esetben egy FPGA-s fejlesztések során a tesztelések két csoportra bonthatóak: a modul tesztekre és a teljes rendszer tesztelésére. A NES projekt esetén viszont olyan komplex változásokat és bemeneteket kellett volna időzítéspontosan megadni a különálló modul tesztekhez (teljes CPU ciklusok processzor oldali műveletei), hogy inkább közvetlenül a teljes rendszer tesztelését kezdtem el.

A rendszer teszteket az ISE-n belül található ISim szimulátorában végeztem. Ezzel képesek vagyunk szintetizálható hardverek működési szimulációjára és az implementálás utáni, úgynevezett post-implemented rendszerek szimulálására is. A szintetizálható rendszerek esetében Verilog test fixture készítésével tudjuk meghatározni a szimulált jeleinket és szimulációs órajeleinket. A NES tesztkörnyezetének írása során a VGA modult és a hozzá tartozó elemeket kivettem a rendszerből, mivel ez csak extra számítást vett volna el a szimulátortól, illetve a rendszer időzítéseinek szinkronizálását is nehezebbé tette volna (50 MHz és 250 MHz-es órajelek arányainak megtartása a rendszer órajellel).

Ahhoz, hogy a teljes NES hardveremet szimulálhassam, szimulálhatóvá kellett tennem a konzulensemtől kapott 6502-es processzor futtatható binárisát. Ezt a feladatot az UNISIM konzol alkalmazás segítségével tudtam megoldani. Ez az eszköz azt teszi lehetővé, hogy implementált modulokból post-implemented szimulációs fájlt készít. Majd ehhez egy általunk értelmezhető Verilog input és output portokkal ellátott modult illeszt, ezáltal képesek vagyunk a kapott szimulációs fájt beilleszteni egy Verilog test fixture-be. A program futtatásához \aref{fig:UNISIM}. ábrán látható beállításokat alkalmaztam.

\begin{figure}[H]
	\centering
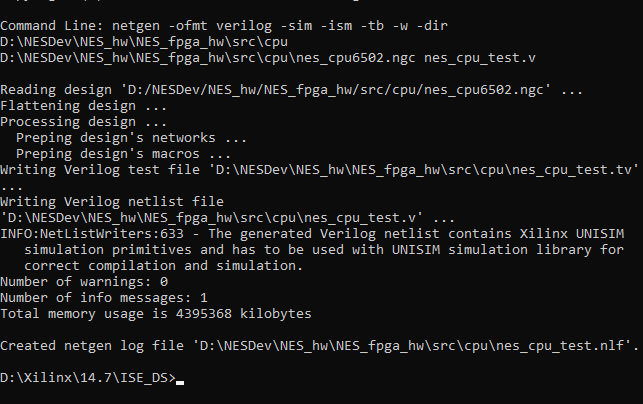
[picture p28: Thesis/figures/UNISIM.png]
	
	\caption{Az UNISIM konzol alkalmazás beállításai} 
	\label{fig:UNISIM}
\end{figure}

A szimulációkhoz és későbbiekben a hardveres tesztekhez is szükségünk van arra, hogy a Karakter és Program ROM-jaink helyes adatokat tartalmazzanak. A NES játékkártyák tartalma általában egy .nes bináris fájlban áll rendelkezésre. Ez tartalmaz egy 16 bájtos fejlécet, majd a program ROM-ot, végül pedig a karakter ROM-ot. A fejléc írja le, hogy az adott játék ROM-jai mekkora területet foglalnak, illetve a játék kártya milyen mapper-t tartalmaz. A .nes fájlt egy program segítségével könnyen felbonthatjuk két bináris ROM területre, majd egy egyszerű shell script segítségével szöveges fájlba írhatjuk a kapott binárisaink tartalmát. Majd az így kapott szöveges fájlok tartalmát a \$readmemh parancs segítségével tudjuk a blokk RAM-okba tölteni. A szimulációk kezdetén a helyes működéséhez érdemes még az összes használt memória területet 0-val feltölteni. Ezeknek az inicializációknak egy részét \aref{code:filling-RAM}. hardverleírásban olvashatjuk.

\begin{lstlisting}[caption={A memória területek inicializálása a szimulációs és hardveres tesztekhez}, label={code:filling-RAM}, style=prettyverilog]
//Character ROM initialization 
initial begin
	$readmemh( "src/games/DK_chr_rom_hex.txt" , ch_rom); //Super_Mario_Bros_chr_rom.txt
end

//NT RAM initialization 
reg  [7:0] 		name_table_ram [2047:0];
integer x;
initial begin for (x=0; x<2048; x=x+1) name_table_ram[x] = 8'b0;
end\end{lstlisting}

Azt tapasztaltam, hogy nagyobb és összetettebb rendszerek szimulációja során az ISim, hosszabb időtartalmú szimulációkra nem alkalmas (nem konzisztensek a számításai). Ezáltal csak egy adott pontig tudtam a szimulációkra hagyatkozni, viszont ez pont elégnek volt ahhoz, hogy könnyen elkezdhessem a teljes rendszer hardveres tesztelését.  

\newpage
\section{Hardveres tesztek}

A diplomatervem során sikerült elkészíteni a konzulensem segítségével az első verzióját az FPGA NES kártyának. Ez \aref{fig:PCB-Assembled}. ábrán látható. \Aref{sec:fpga-nes-board-summary}. fejezet során viszont már egy javított második verziót mutattam be (ezért láthatunk némi különbséget a két kártya elrendezése között). A második verzióra javítottam a flash chip FPGA-ba huzalozásán és két extra hangerő szabályzó gombot adtam a nyákhoz.

\begin{figure}[H]
	\centering
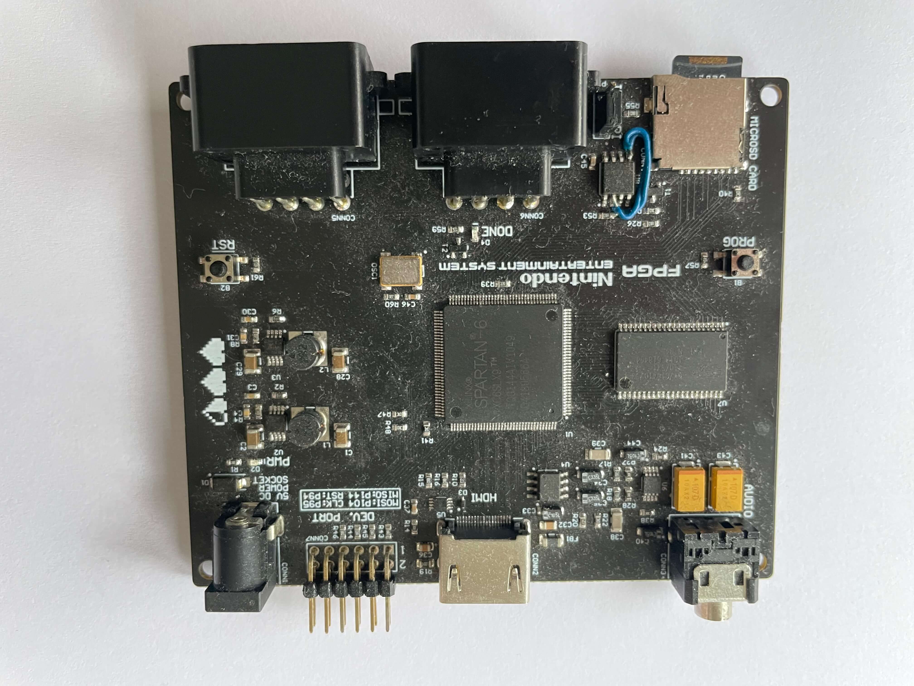
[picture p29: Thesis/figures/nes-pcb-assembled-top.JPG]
	
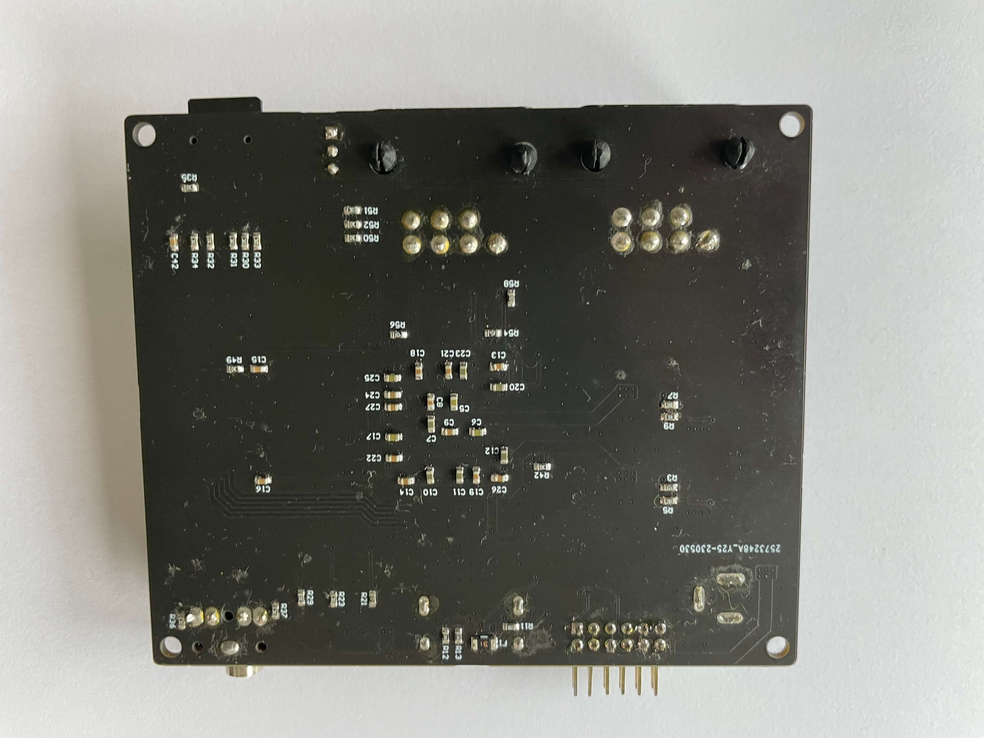
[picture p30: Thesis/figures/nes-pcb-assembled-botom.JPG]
	
	\caption{A kész FPGA NES kártya} 
	\label{fig:PCB-Assembled}
\end{figure}

A hardveres tesztelés során, a hardver binárisának feltöltésére a MIT-en fejlesztett, Logsys flash programozót használtam, ennek implementálását már a fentebbiekben olvashattuk (\ref{sec:logsysport}. fejezet). Az FPGA NES kártya mérési és tesztelési elrendezését \aref{fig:pcb-testing}. ábrán láthatjuk. 

A NES rendszer tesztelésére két klasszikus játékot választottam. Az első a Donkey Kong, amely egy könnyebben emulálható 16 kilobájtos program ROM-al rendelkező játék. A második pedig a NES egyik legnehezebben emulálható játéka, a Super Mario Bros. Ehhez a játékhoz hibátlanul implementált időzítésekre és helyesen kialakított PPU és CPU memória címekre van szükség. Ezt a játékot szokták legtöbbször a végső tesztként használni emulált PPU-k és CPU-k tesztelésére. A Donkey Kong tesztelését és futását \aref{fig:Donkey-start}. és \ref{fig:Donkey-level-1}. ábrákon láthatjuk. A Super Mario Bros.-t pedig futás közben \aref{fig:Super-Mario-start}. és \ref{fig:Super-Mario-world5-1}. ábrán tekinthetjük meg.
	
\begin{figure}[H]
	\centering
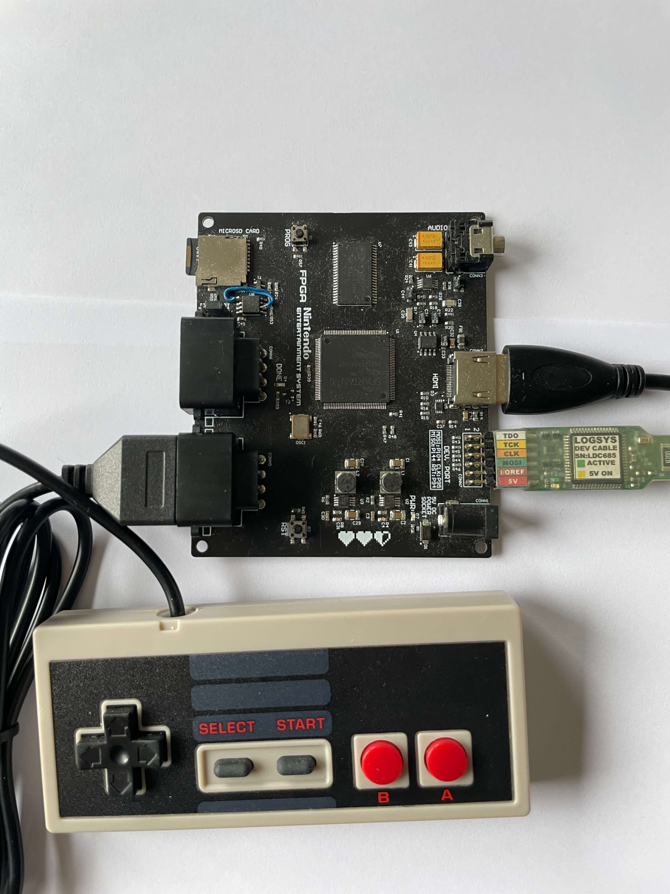
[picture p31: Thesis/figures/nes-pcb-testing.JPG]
	
	\caption{FPGA NES kártya mérési és tesztelési elrendezésé} 
	\label{fig:pcb-testing}
\end{figure}

\begin{figure}[H]
	\centering
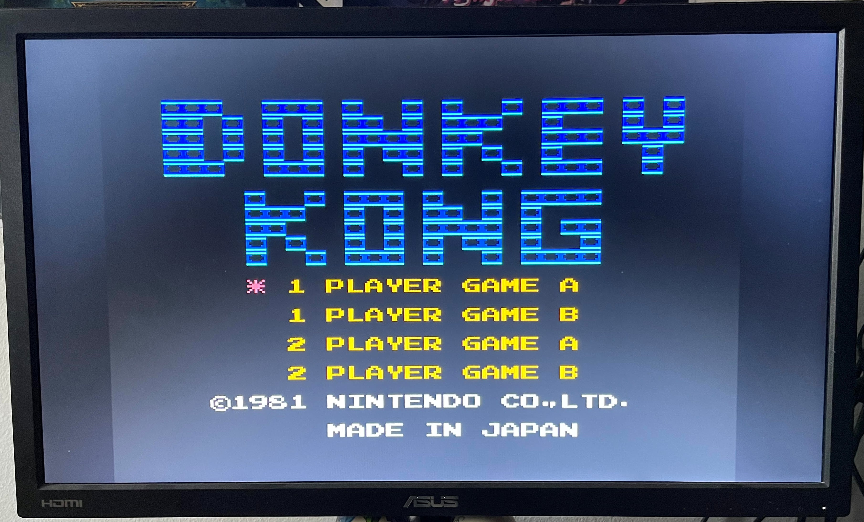
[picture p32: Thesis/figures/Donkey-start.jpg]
	
	\caption{A Donkey Kong kezdő képernyője} 
	\label{fig:Donkey-start}
\end{figure}

\begin{figure}[H]
	\centering
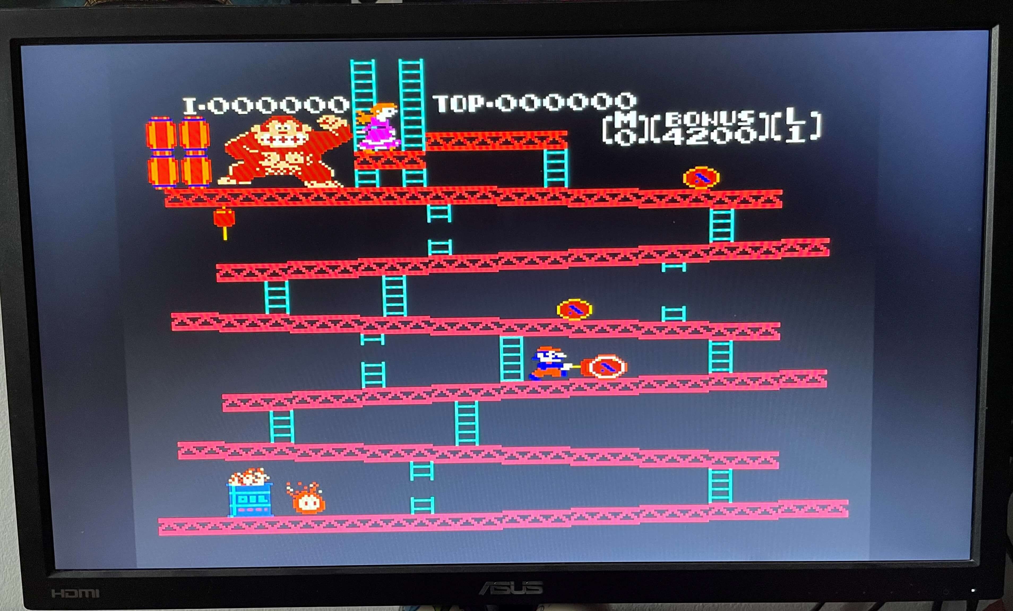
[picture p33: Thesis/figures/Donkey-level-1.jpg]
	
	\caption{Donkey Kong ikonikus első pálya futás közben} 
	\label{fig:Donkey-level-1}
\end{figure}

\begin{figure}[H]
	\centering
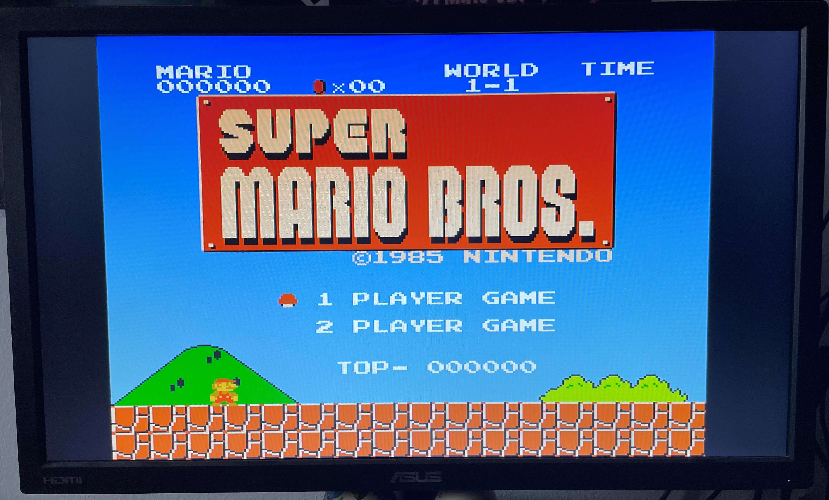
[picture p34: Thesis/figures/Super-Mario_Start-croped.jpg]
	
	\caption{A Super Mario Bros. kezdő képernyője} 
	\label{fig:Super-Mario-start}
\end{figure}

\begin{figure}[H]
	\centering
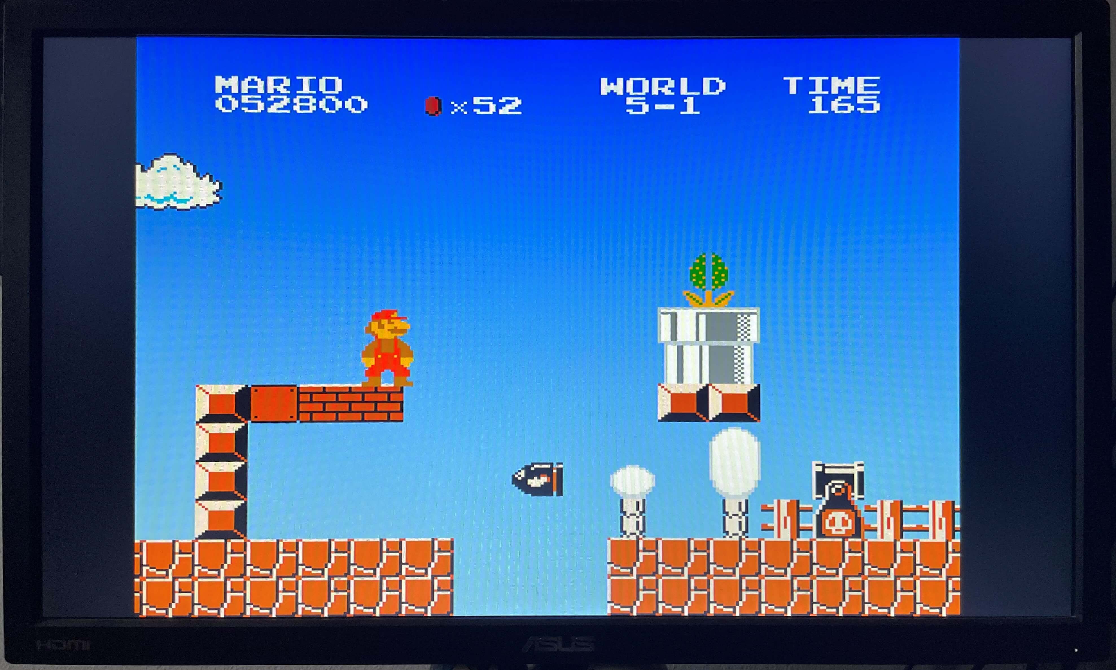
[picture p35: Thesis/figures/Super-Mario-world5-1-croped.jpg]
	
	\caption{A Super Mario Bros. ötödik világának első pályája} 
	\label{fig:Super-Mario-world5-1}
\end{figure}

\section{A tesztek eredményeinek kiértékelése}

A szimulációs tesztek során sikeresen fel tudtam éleszteni a NES rendszerét olyan szintre, hogy elkezdhettem a hardveres teszteket. A későbbiek során is voltak olyan hardveres modulok, amelyekben hibakeresés során többször is visszanyúltam a szimulátorhoz. Sajnos a ISim hibás működése miatt a teljes rendszert nem tudtam nyomon követni, viszont a szimulációk során megfigyelt hardveres működéseket \aref{sec:fpga-desing-begining}. fejezetben több helyen is láthatjuk.

A hardveres tesztelések eredménye is sikeres lett, a két játék teljes mértékben játszható állapotban van. A hosszabb tesztelések során sem akadtam olyan hibára, amely a programok futását megakadályoznák és ezzel a játékokat játszhatatlanná tennék. A képalkotásért felelős chip a PPU időzítései is pontosak, hiszen még az idő kritikus játékok, mint a Mario is játszható a konzolon. Ez \aref{fig:Super-Mario-world5-1}. ábrán is látható. Itt még jól megfigyelhető az is, hogy a PPU háttér és sprite alkotási része is összhangban van (egy sűrűbb mozgó elemekkel teli képen sem hibásodik meg a képalkotás). Az általam használt színpaletták, szépen visszaadják az eredeti NES játékok színvilágát, ezzel egy nagyon jó minőségű emulálást lehetővé téve.

Úgy érzem az FPGA-s hardverfejlesztések teszteléseinek széleskörű tárházát ismertem meg, és ezen eszközök segítségével sikeresen működésre bírtam az általam fejlesztett konzol hardverét.

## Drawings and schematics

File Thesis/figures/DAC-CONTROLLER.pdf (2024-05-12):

# DAC, Amplifier and 3.5mm Jack

# Game controller ports

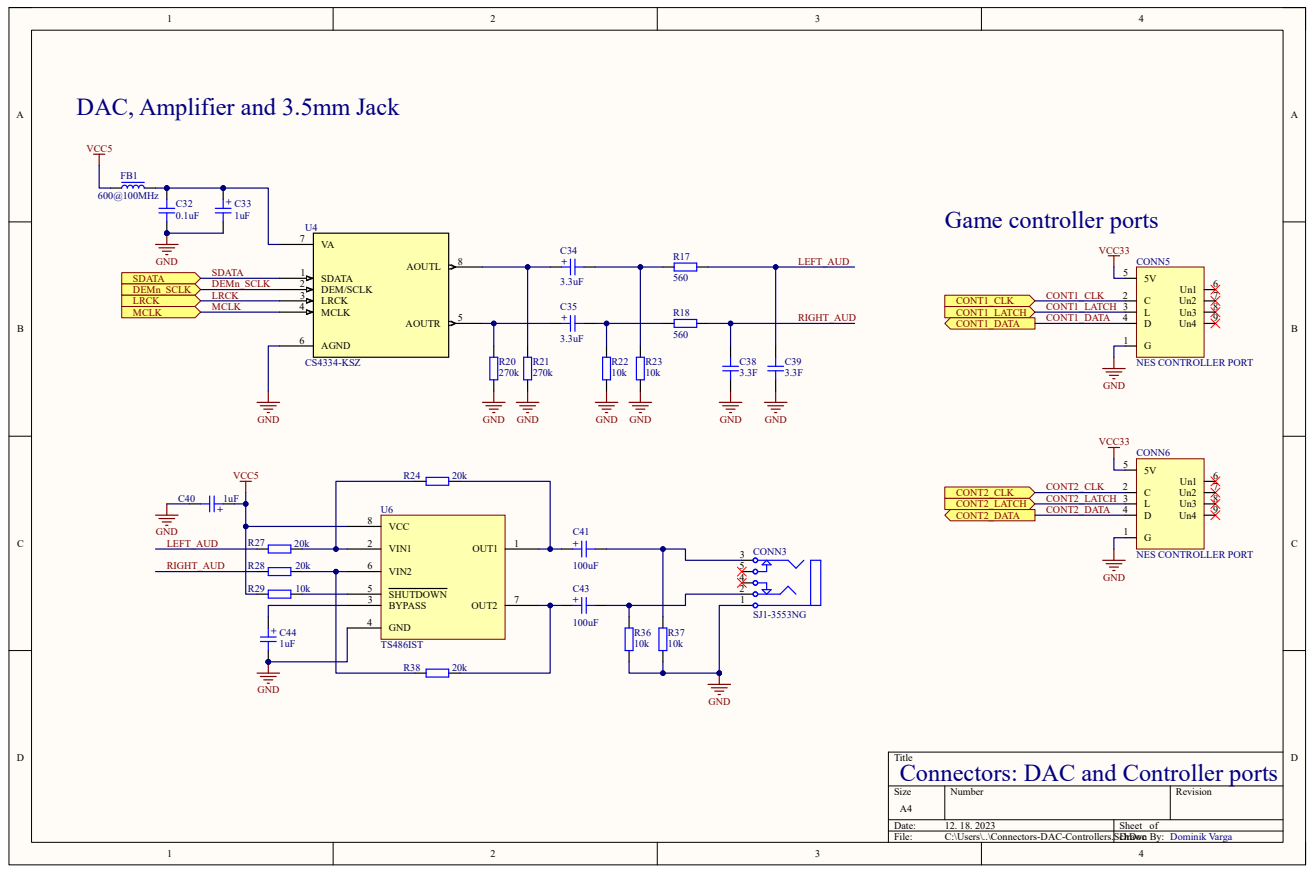
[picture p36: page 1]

Title
Connectors: DAC and Controller ports

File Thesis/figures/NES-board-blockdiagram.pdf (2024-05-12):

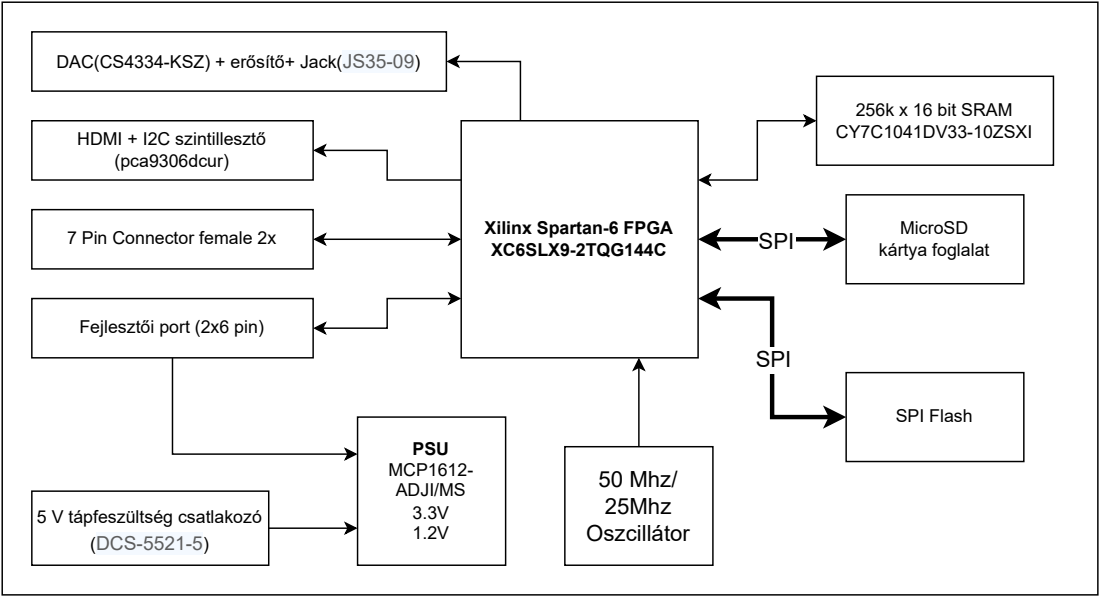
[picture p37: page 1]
256k x 16 bit SRAM CY7C1041DV33-10ZSXI; MicroSD; 50 Mhz/ 25Mhz Oszcillátor; 5 V tápfeszültség csatlakozó (DCS-5521-5); PSU MCP1612- ADJI/MS 3.3V 1.2V; HDMI + I2C szintillesztő (pca9306dcur); SPI Flash; SPI

DAC(CS4334-KSZ) + erősítő+ Jack(JS35-09) (https://lomex.hu/hu/webshop/%23/search,43-08-39/stype,1)

Xilinx Spartan-6 FPGA
XC6SLX9-2TQG144C

7 Pin Connector female 2x

kártya foglalat SPI

Fejlesztői port (2x6 pin)

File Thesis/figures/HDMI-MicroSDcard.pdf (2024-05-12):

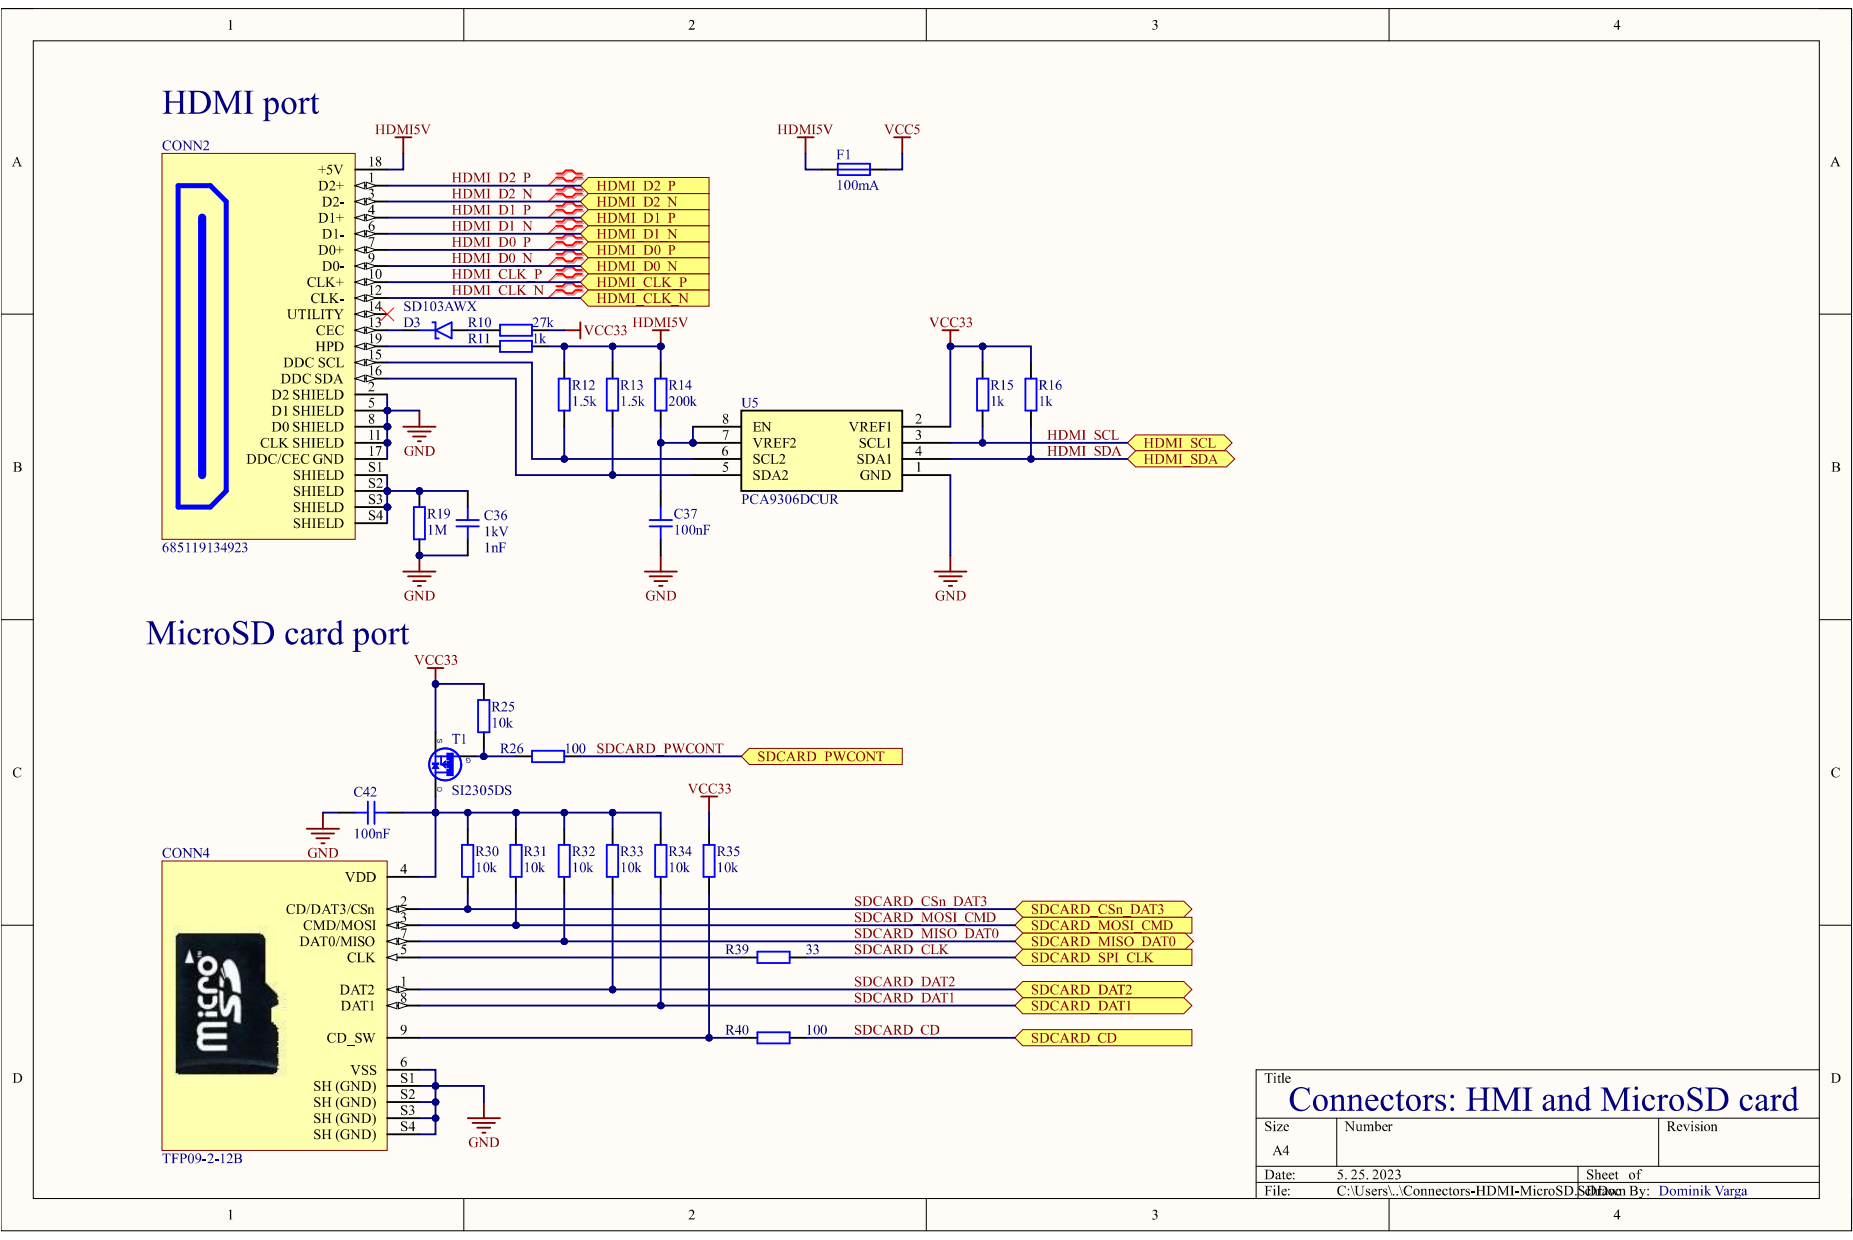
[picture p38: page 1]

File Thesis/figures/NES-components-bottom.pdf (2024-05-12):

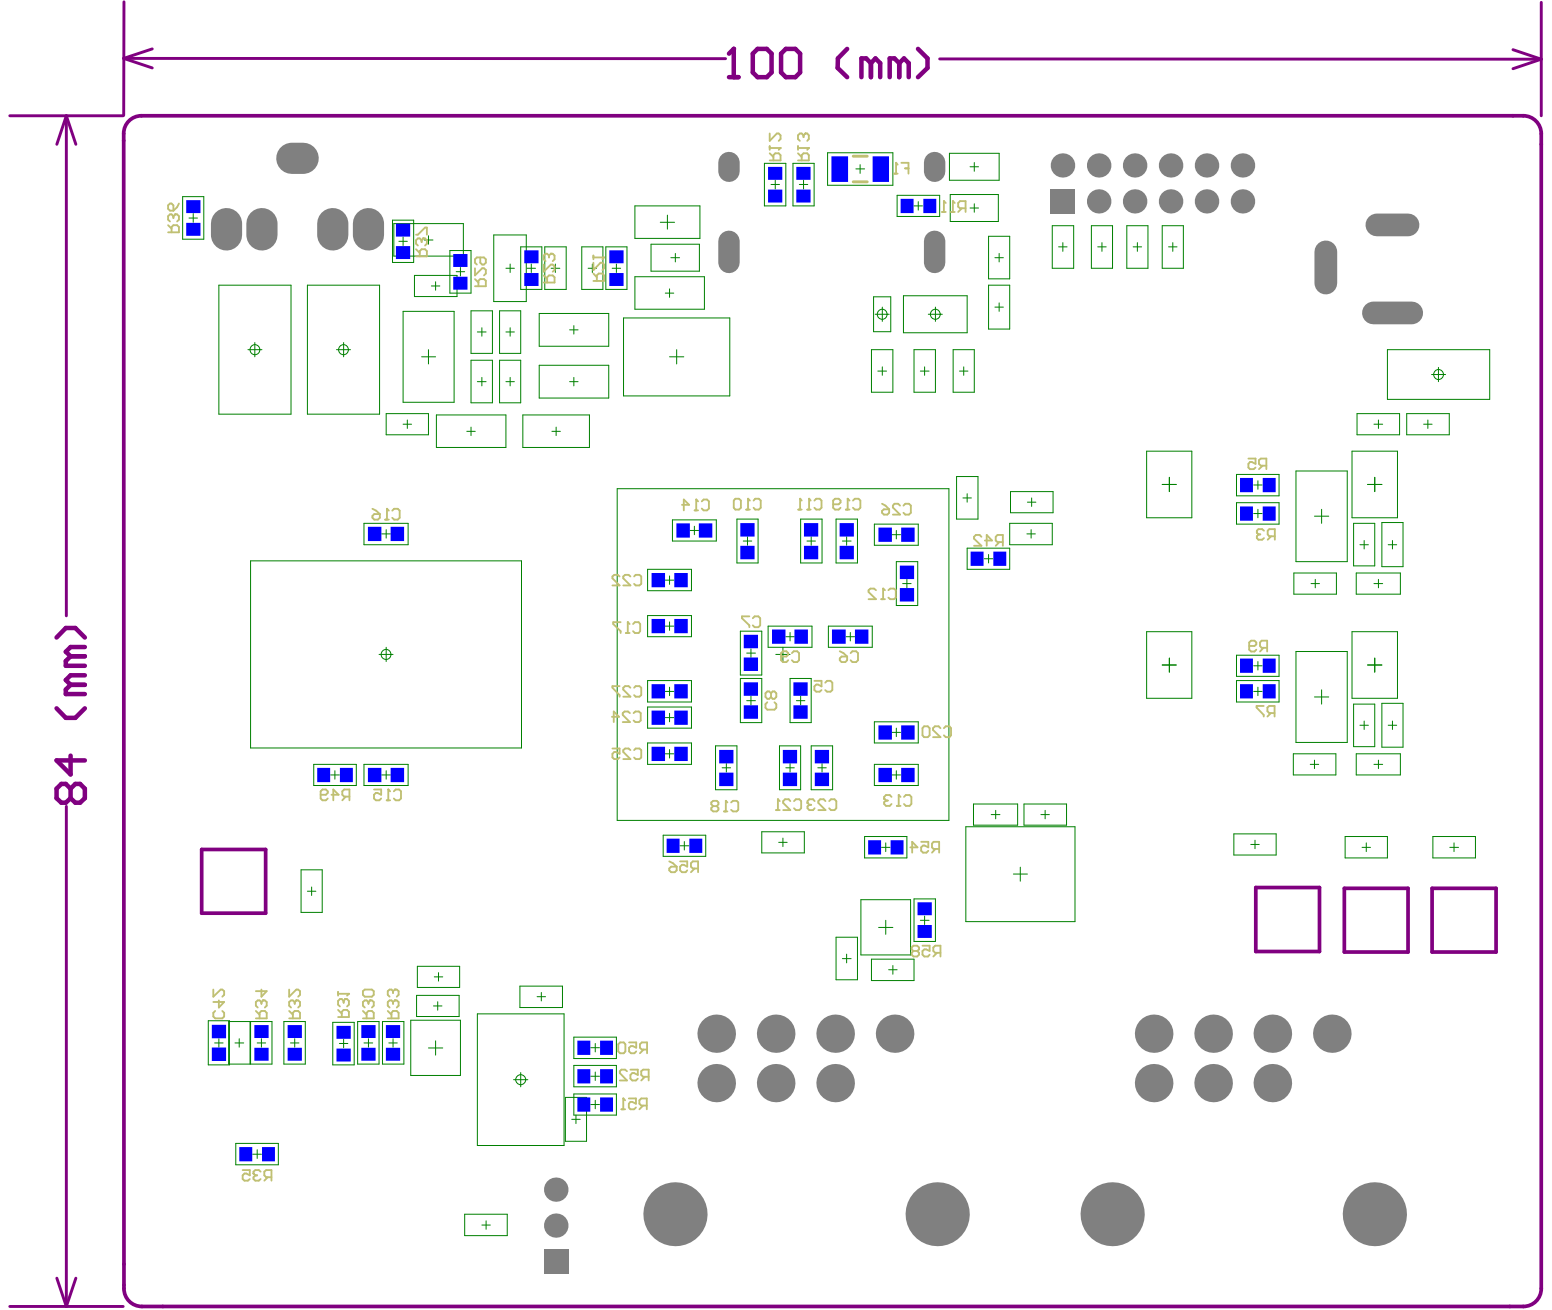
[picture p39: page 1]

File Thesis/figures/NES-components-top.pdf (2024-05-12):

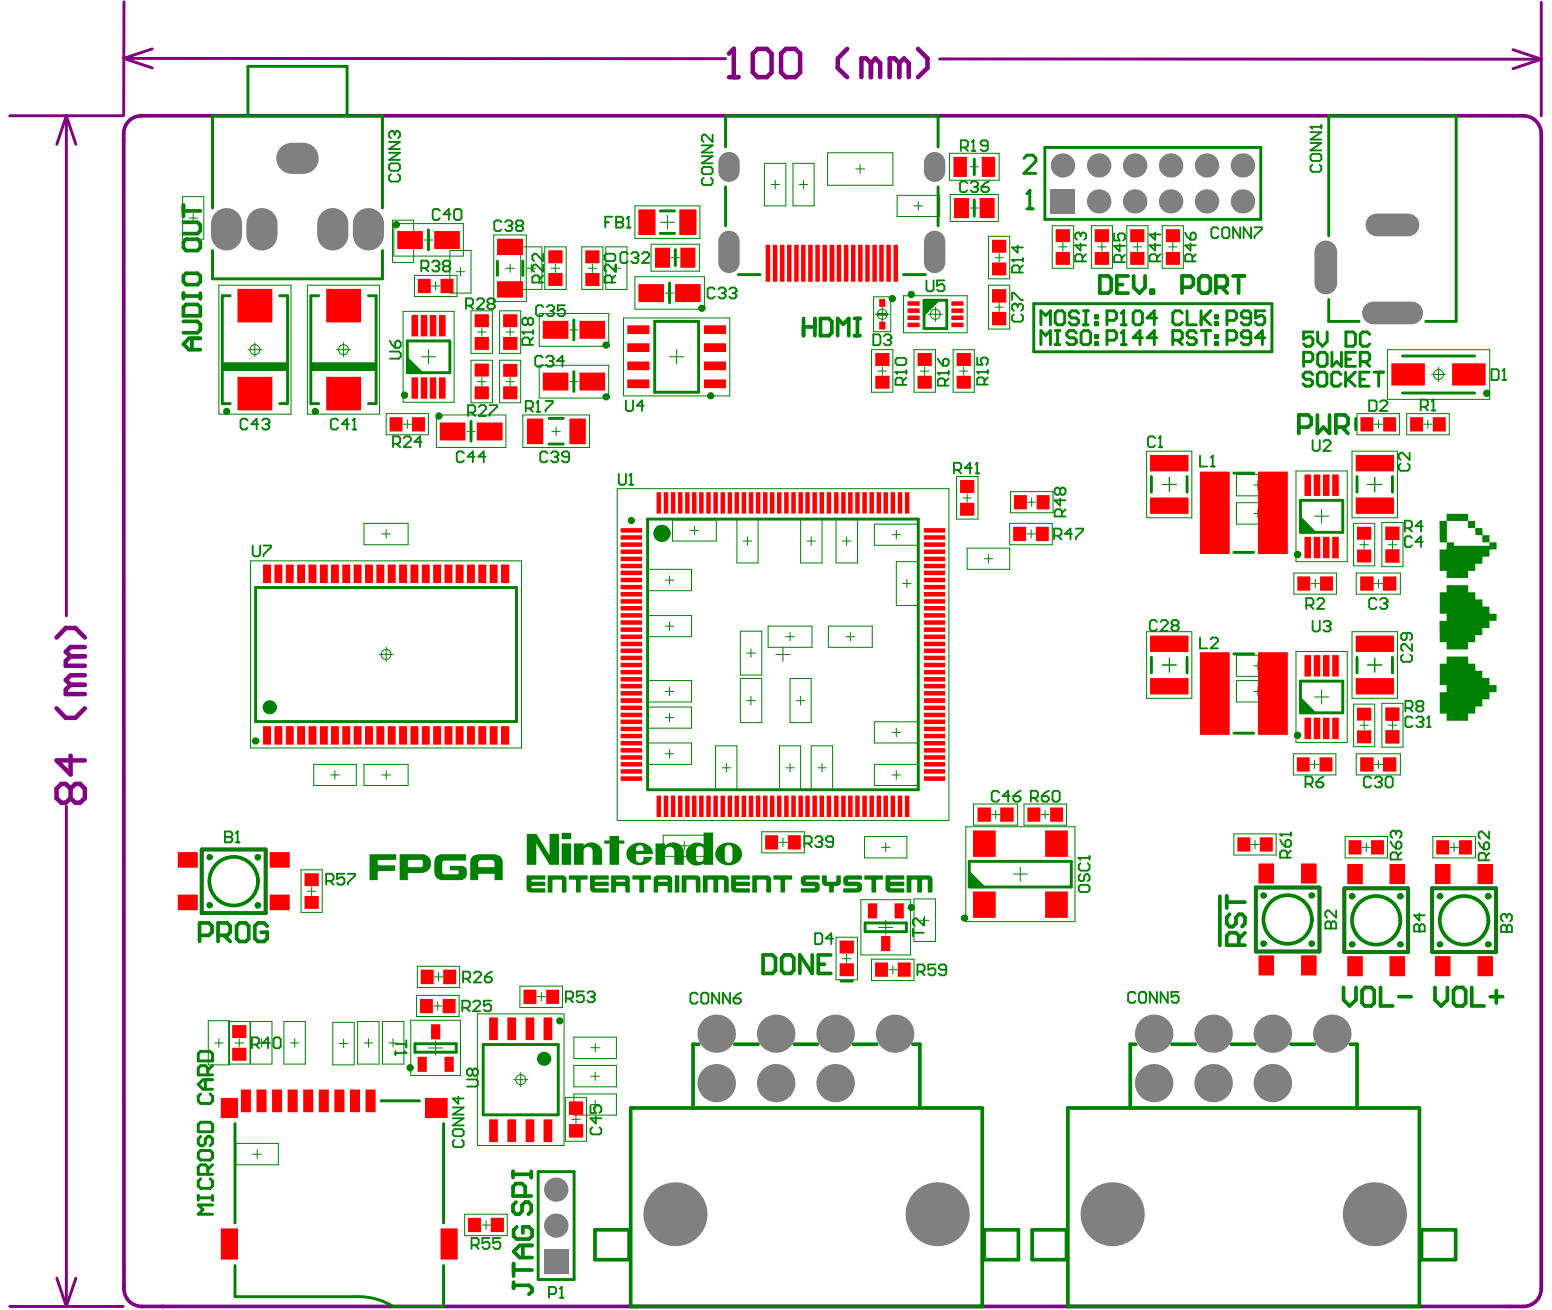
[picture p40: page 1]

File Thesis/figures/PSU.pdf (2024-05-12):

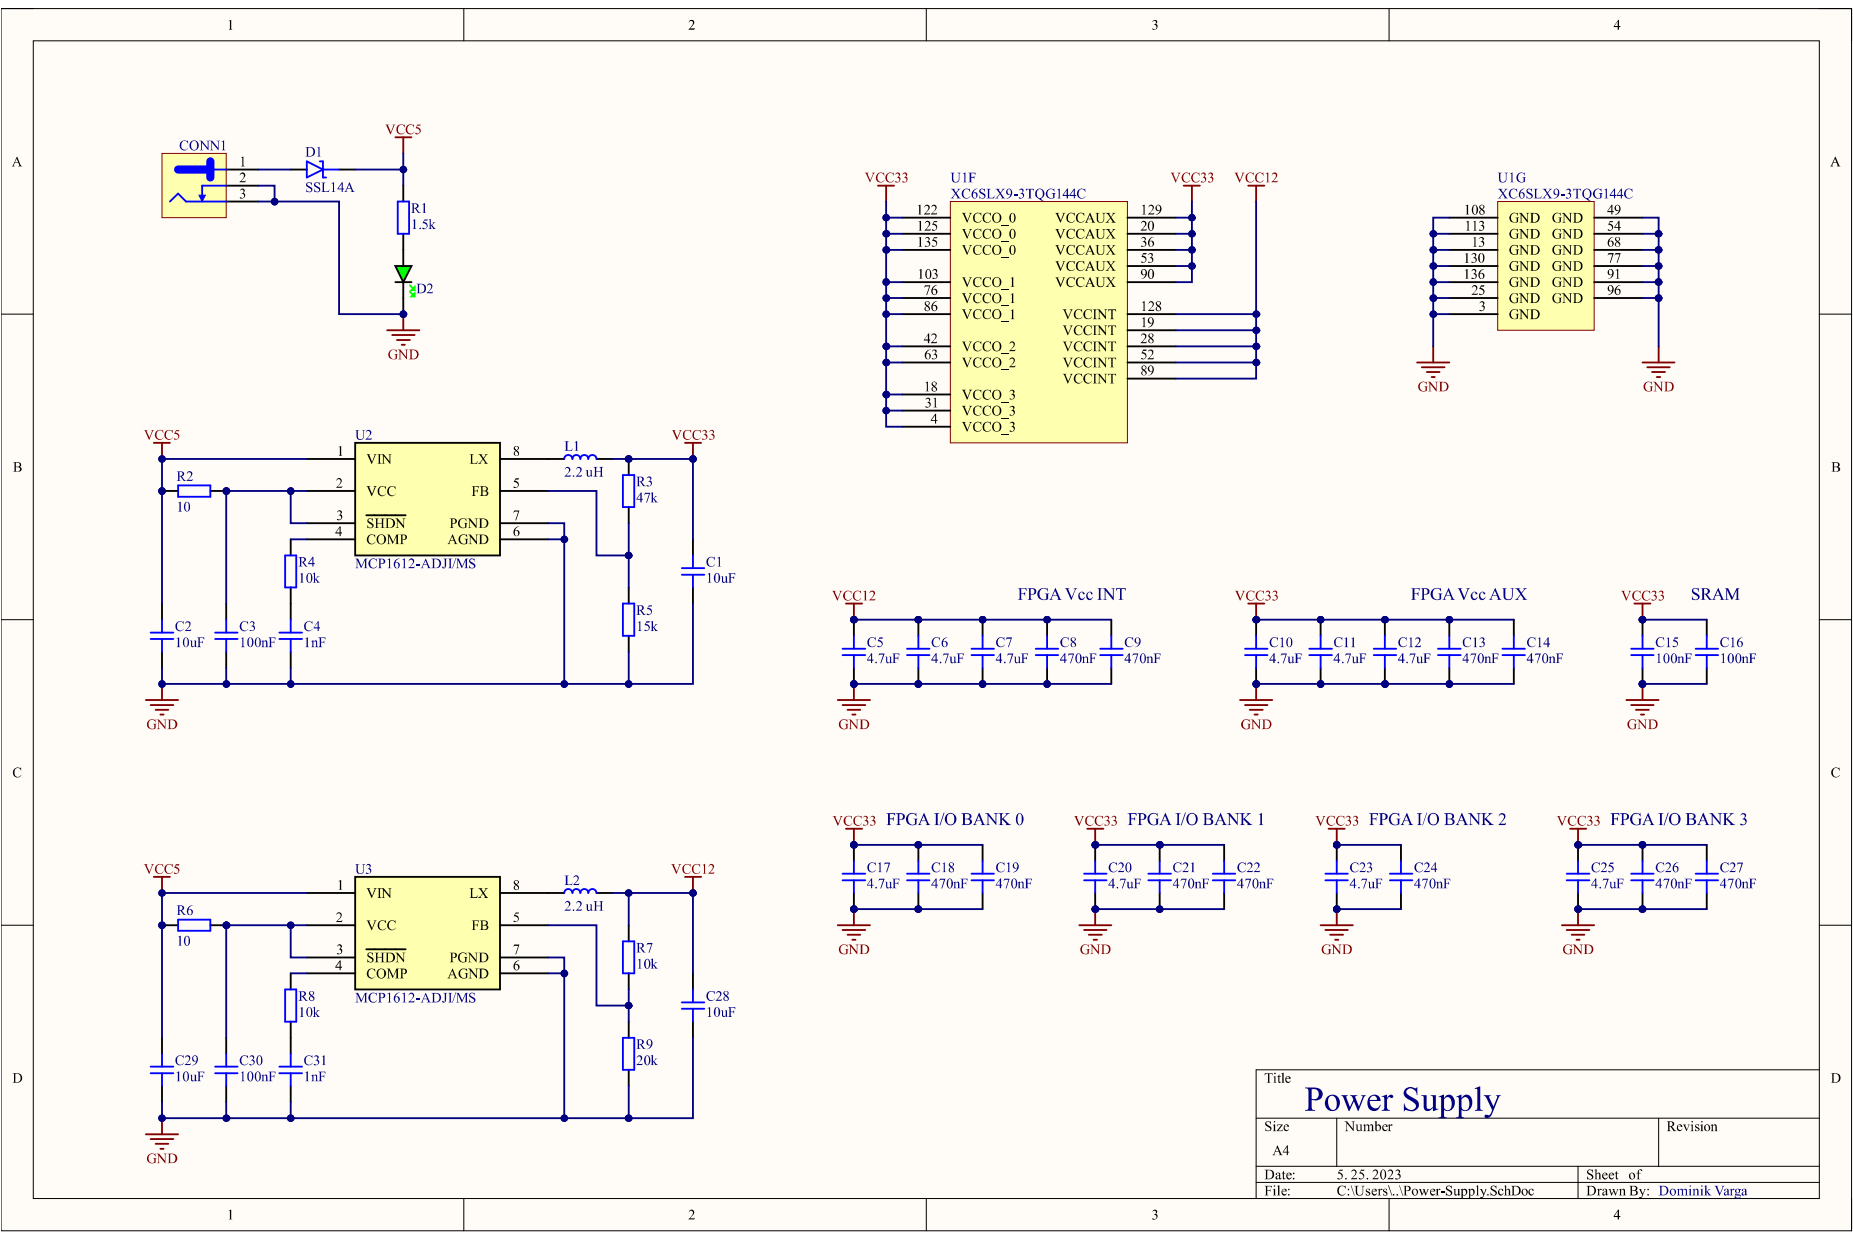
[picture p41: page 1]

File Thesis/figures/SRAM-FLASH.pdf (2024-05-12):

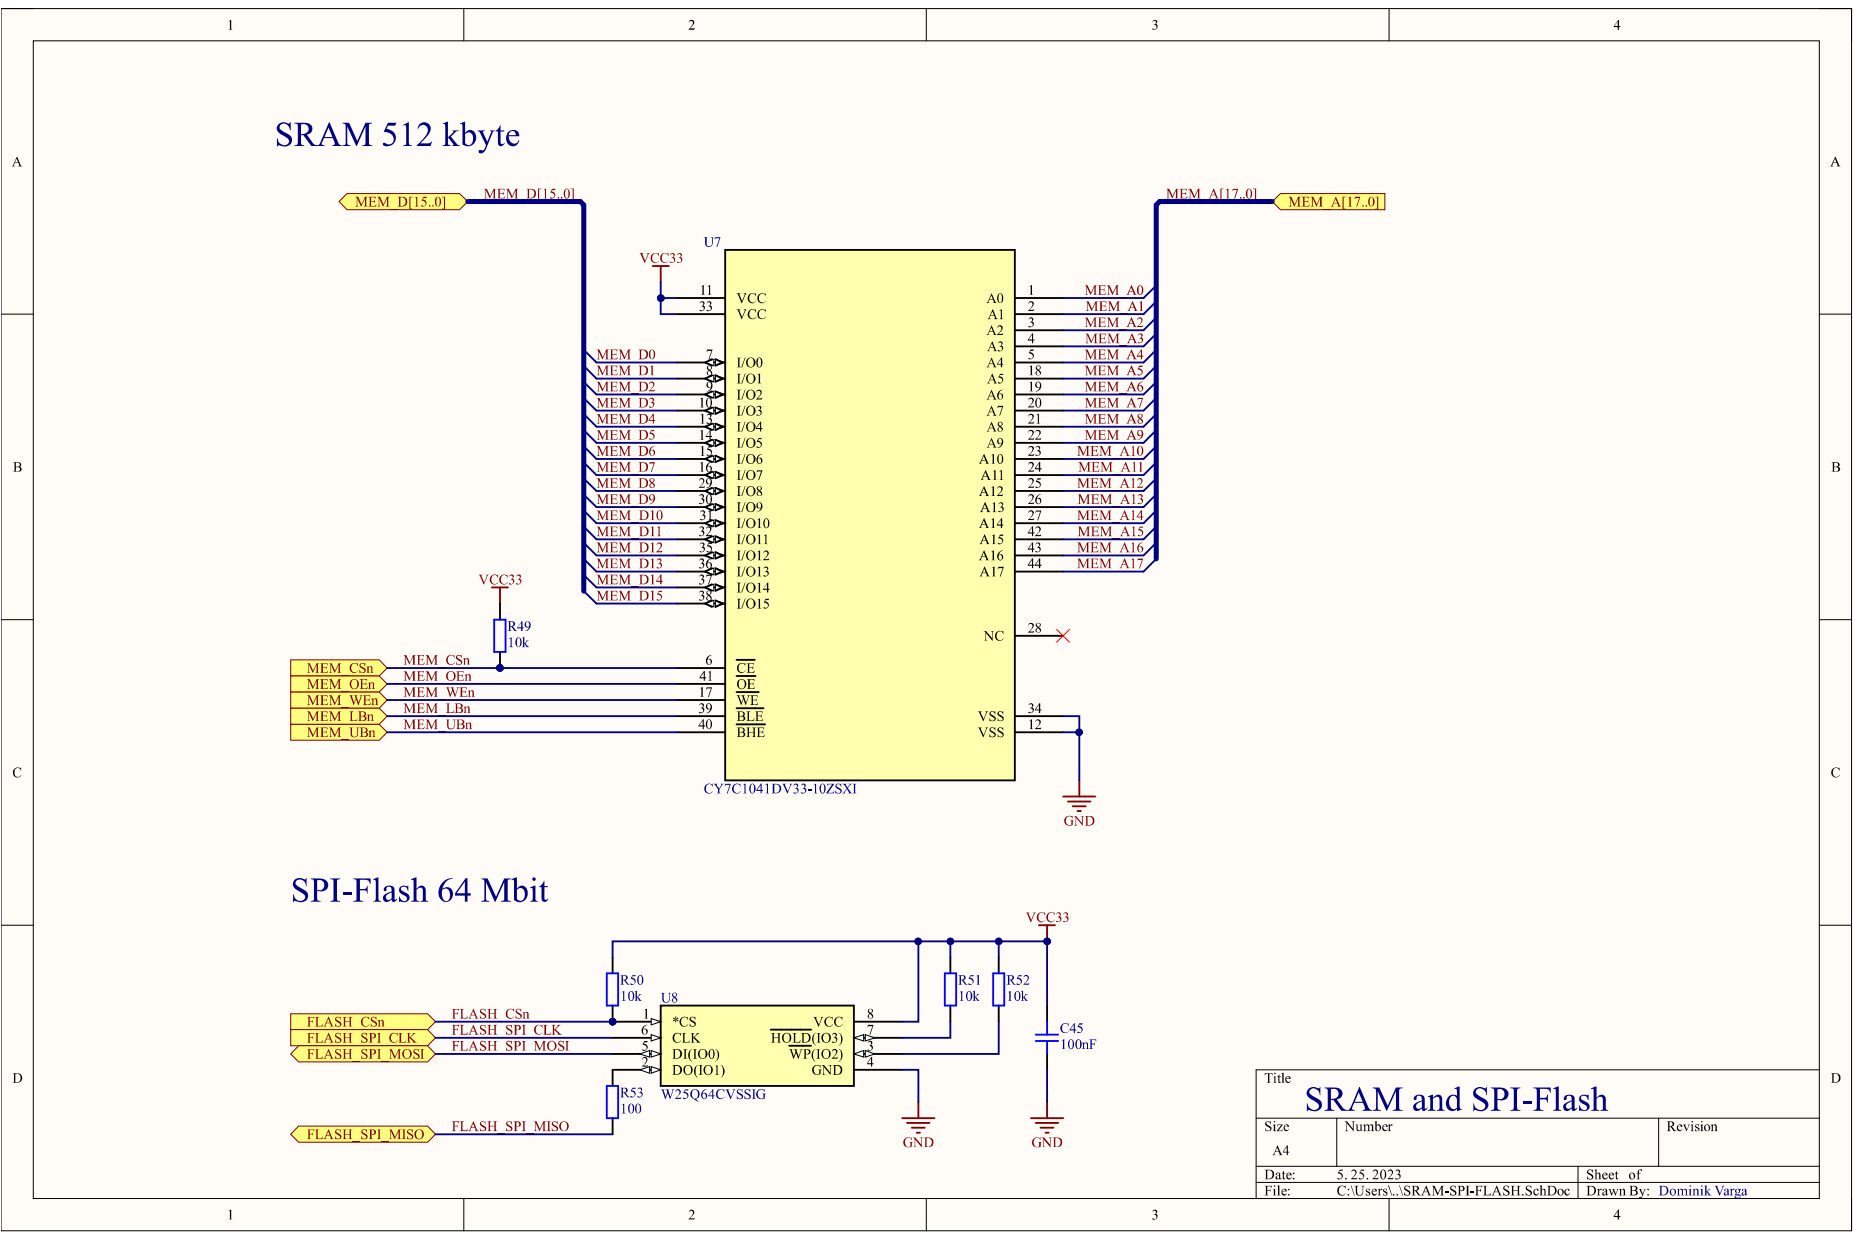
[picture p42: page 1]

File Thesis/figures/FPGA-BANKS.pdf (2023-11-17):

XC6SLX9-3TQG144C BANK ¹ | IO_L1P_1 | 105
XC6SLX9-3TQG144C BANK ³ | IO_L1P_3 | 35

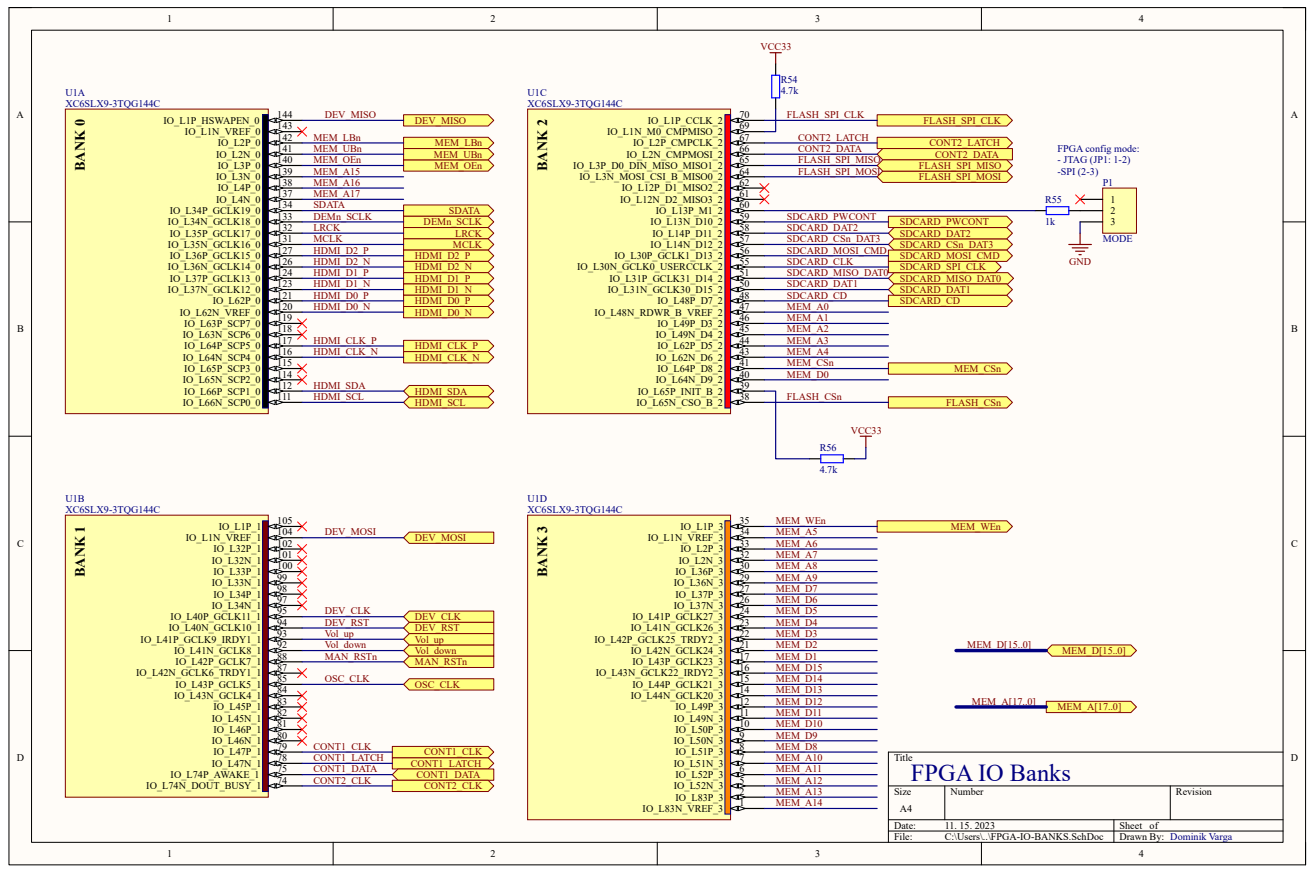
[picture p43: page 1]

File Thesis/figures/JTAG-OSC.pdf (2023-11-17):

# FPGA-JTAG

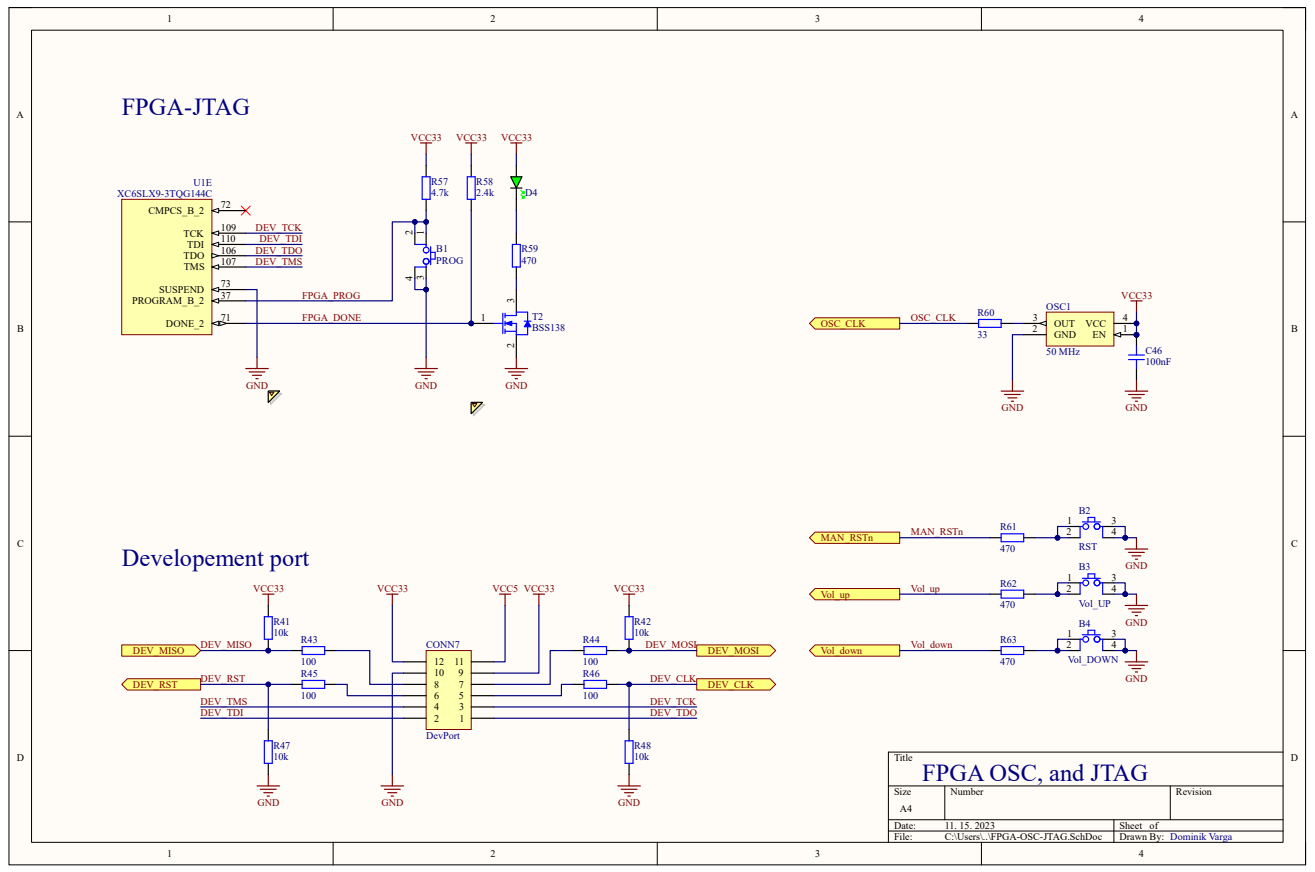
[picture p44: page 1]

Title
FPGA OSC, and JTAG

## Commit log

2023-05-18 Inital commit
    [Connectors-DAC-Controllers.SchDoc, Connectors-HDMI-MicroSD.SchDoc, FPGA-IO-BANKS.SchDoc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]
2023-07-28 Registers base frame -based on brianbennets nes
2023-10-12 major update add sprite rendering, sprite buffer, and sprite dma
2023-11-08 working PPU and NES system with Matio and DK, (with some little BG rendering glitches)
    [m_00000000000129024098_1730278898.nt64.obj, m_00000000000129589818_1491383940.nt64.obj, m_00000000000204678708_4262916950.nt64.obj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]
2023-12-08 Nearly full thesis without any correction
    [m_00000000001189877954_2410004801.nt64.obj, m_00000000003244186716_2410004801.nt64.obj, nes_top_test_isim_beh.exe_main.nt64.obj]
2024-05-12 Jan 1 stage on thesis project
2024-05-12 isim files excluded
    [m_00000000000129024098_1730278898.nt64.obj, m_00000000000129589818_1491383940.nt64.obj, m_00000000000204678708_4262916950.nt64.obj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]
